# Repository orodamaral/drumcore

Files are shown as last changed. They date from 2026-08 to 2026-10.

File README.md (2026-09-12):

# DRUMCORE — Módulo MIDI-USB/BLE para Bateria Eletrônica (ESP32-S3)

Módulo de disparo MIDI para bateria eletrônica, baseado em ESP32-S3, com suporte a
32 canais analógicos (via 2x multiplexador CD4067, uma "jackboard" de 16 canais
cada — ver [hardware/jackboard/](hardware/jackboard/)), tela TFT ST7735 (SPI) e
1 encoder rotativo com chave para navegação, e um app de configuração em React,
direto pelo navegador via Web Serial — sem instalar nada.

Projeto construído sobre a biblioteca [HelloDrum-arduino-Library](https://github.com/RyoKosaka/HelloDrum-arduino-Library)
de Ryo Kosaka (vendorizada e adaptada em [firmware/lib/HelloDrum-arduino-Library](firmware/lib/HelloDrum-arduino-Library)).

## Estrutura do projeto

```
DrumCore/
├── docs/                 Documentação do projeto (decisões, hardware, progresso)
├── design/               Especificação de UI, identidade visual (logo, paleta)
├── firmware/             Firmware ESP32-S3 (PlatformIO)
│   ├── platformio.ini
│   ├── src/              Código-fonte do módulo
│   ├── include/
│   └── lib/
│       └── HelloDrum-arduino-Library/   Biblioteca base, vendorizada e modificada
├── hardware/             Projetos KiCad (jackboard — placa de conectores TRS + rede de proteção)
├── web-app/              App de configuração do módulo (React/TS), direto no navegador via
│                         Web Serial, sem instalar nada
└── site/                 Site estático de apresentação do projeto (GitHub Pages) — publica
                          o web-app/ em site/app/, ver .github/workflows/pages.yml
```

## Documentação

Todo o histórico de decisões, aprendizados sobre a biblioteca base e notas de
hardware está em [docs/](docs/). Comece por [docs/00-visao-geral.md](docs/00-visao-geral.md).

## Status

Veja [docs/CHANGELOG.md](docs/CHANGELOG.md) para o histórico completo do que já
foi feito.

## Licença

Este projeto é licenciado sob [Creative Commons Atribuição-NãoComercial 4.0
Internacional (CC BY-NC 4.0)](LICENSE) — uso e cópia livres, **sem fins
comerciais**, sempre **citando a fonte** (este repositório e a
HelloDrum-arduino-Library, ver crédito acima). Detalhes completos e a
atribuição de terceiros (a biblioteca base, sob licença MIT própria) estão em
[LICENSE](LICENSE).

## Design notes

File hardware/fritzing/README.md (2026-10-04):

# Peça do Fritzing — DrumCore Jackboard

`DrumCore_Jackboard.fzpz` é a jackboard single-layer como peça do
[Fritzing](https://fritzing.org/), para desenhar a ligação do módulo
(ESP32-S3 + jackboards + tela + encoder) e dos pads.

## Como usar

No Fritzing: **Arquivo > Abrir** (ou arraste o `.fzpz` para a janela). A peça
aparece no bin **Minhas peças** (*My Parts*), família "DrumCore".

## O que a peça tem

- **Medidas reais** do projeto KiCad (`hardware/jackboard_singlelayer/`):
  placa de 184 × 57,5 mm, jacks a cada 22,5 mm, furos nas posições reais
  (vista PCB).
- **24 conectores**:
  - **8 de controle do MUX:** GND, VCC (3,3 V), EN, S0, S1, S2, S3, SIG. O
    EN já vai para o GND na própria placa (no Fritzing, EN e GND estão no
    mesmo barramento), então bastam 7 fios até o ESP32.
  - **Tip e ring dos 8 jacks** (J1 tip = canal 0 = pad 1 no ConfigTool, J1
    ring = canal 1, e assim por diante), para ligar os pads no diagrama.

Ligação no ESP32-S3: S0–S3 = GPIO39/40/41/42 (as 2 placas em paralelo), SIG da
placa A = GPIO2, da placa B = GPIO1. Ver [docs/02-hardware.md](../../docs/02-hardware.md).

## Gerar de novo

```
python hardware/fritzing/make_jackboard_fzpz.py
```

Gera o `.fzpz` e os arquivos soltos em `part/` (`.fzp` + SVGs das vistas
protoboard, esquemático, PCB e ícone). As medidas ficam no topo do script. Se a
placa mudar no KiCad, atualize lá.

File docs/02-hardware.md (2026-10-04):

# Hardware

**Esquemático visual**: [docs/assets/esquematico-hellodrum.html](assets/esquematico-hellodrum.html)
(abrir no navegador) reúne todo o pinout abaixo num diagrama único — ESP32-S3
↔ 2x CD4067 (HW-178) ↔ tela TFT ↔ 1 encoder, já mostrando de qual header
físico (esquerdo/direito) cada fio sai. Também publicado como
[artifact](https://claude.ai/code/artifact/7bcaa18b-a9b3-46e4-8ba0-90197b7ededc)
(link privado, pode estar desatualizado - o arquivo local é a fonte da
verdade). Gerado em 2026-08-20, redesenhado em 2026-08-21 para o CD4067
(Fase K), reorganizado por ergonomia de montagem em 2026-08-21 (Fase L),
refinado no mesmo dia pra usar pinos fisicamente **contíguos** dentro de
cada header, reduzido de 2 encoders pra 1 na Fase Y (2026-09-04) e
**reorganizado por função** (em vez de por alimentação) na Fase Z
(2026-09-05, ver seção "Divisão adotada" abaixo) — atualizar (ou marcar
como desatualizado) se o pinout abaixo mudar de novo.

## Componentes previstos

- 1x placa ESP32-S3 (dev board, 44 pinos em 2 headers de 22, USB-C nativo
  exposto). Pinout confirmado a partir de uma foto da placa real (vendedor
  "OceanLabz") em 2026-08-21 — ver seção "Pinout real da placa" abaixo.
  Módulo confirmado por Rodrigo na serigrafia em 2026-08-31: **ESP32-S3-N16R8**
  (16MB flash + 8MB PSRAM **octal**) — GPIO33-37 são internos (barramento
  da PSRAM) nessa variante, ver "Pinos evitados" abaixo.
  `firmware/platformio.ini` ajustado em 2026-08-31 (overrides de
  `board_build`/`board_upload` + `-D BOARD_HAS_PSRAM`) pra refletir o
  módulo real (16MB flash, PSRAM octal habilitada) — ver
  [01-decisoes-arquiteturais.md](01-decisoes-arquiteturais.md) pro
  detalhe. `pio run` confirmado com sucesso.
- 2x módulo multiplexador analógico CD4067 (breakout "HW-178", 16 canais
  cada → 32 canais totais). Comprado já montado em placa (resistores/
  desacoplamento inclusos) — substitui as 4x CD4051 previstas originalmente,
  ver [01-decisoes-arquiteturais.md](01-decisoes-arquiteturais.md) pro
  racional da troca (Fase K).
  **Realização física (2026-09-06, confirmado por Rodrigo)**: em vez do
  breakout HW-178 avulso, cada um dos 2 MUX vive numa placa própria — a
  **jackboard** (`hardware/jackboard/`, projeto KiCad): HC4067 onboard +
  8 jacks TRS 6.35mm (16 canais) + rede de proteção por canal. O sistema
  final usa **2 jackboards idênticas**, uma por MUX, pra fechar os 32
  canais. **Cada jack TRS leva 2 canais**: canal par (0-based: 0, 2, 4…) =
  **tip**, ímpar (1, 3, 5…) = **ring** — na numeração do ConfigTool, Pad 1
  = tip e Pad 2 = ring do Jack 1, e assim por diante (confirmado pelo
  Rodrigo em 2026-09-27). Sensores de 2 zonas leem a zona principal no 1º
  canal do par, então precisam começar no tip: **tip = pele/corpo, ring =
  aro/borda**, o padrão dos pads de mercado. O firmware recusa tipo de 2
  canais começando num ring (`set_pad` → `two_channel_needs_tip`; na tela
  o encoder pula esses tipos), e a tela LIVE/lista de pads mostra os
  canais agrupados por jack. Ver [site/hardware.html](../site/hardware.html) e
  `docs/CHANGELOG.md` (entrada 2026-09-06) pro estado atual da placa.
- Pads piezo (simples e/ou duplos), pratos 2/3 zonas, hi-hat, conforme suportado
  pela lib (ver [03-biblioteca-hellodrum.md](03-biblioteca-hellodrum.md)).
- Tela TFT 1.8" 128x160 RGB (sticker do modelo real - a doc antiga dizia
  1.44"/128x128, era só suposição antes de conferir na placa física),
  driver ST7735S, interface SPI, rodando em paisagem (160x128 na tela,
  `setRotation(1)` - ver [01-decisoes-arquiteturais.md](01-decisoes-arquiteturais.md),
  Fase R). Substitui o OLED SSD1306/I2C previsto inicialmente.
- 1x encoder rotativo com chave (push-button), para navegação/edição —
  substitui os 5 botões discretos originalmente previstos, e o par de 2
  encoders usado até a Fase Y (2026-09-04) — ver
  [01-decisoes-arquiteturais.md](01-decisoes-arquiteturais.md) (Fase Y e
  Fase Z).

## Pinout real da placa (Fase L, reorganizado na Fase Z)

A placa comprada expõe os 44 GPIOs do ESP32-S3 em 2 headers físicos de 22
pinos cada, um de cada lado do módulo WROOM. Isso importa pra ergonomia da
montagem: **cada subsistema (MUX, tela, encoder) deve sair inteiro de um
único header**, pra não precisar de fios cruzando de um lado ao outro da
placa.

Até a Fase Y, a divisão era guiada por **alimentação**: `3V3` só existia no
header esquerdo (o direito só tinha `GND`), então o MUX e a tela (que
precisam de VCC) ficavam à força no header esquerdo, sobrando o direito só
pros encoders (que usam apenas pull-up interno, sem VCC externo).

**Fase Z (2026-09-05)**: a placa física ganhou pads de `3V3`/`GND` extras
nos **dois** headers (adicionados por fora do dev board original,
independente do desenho de fábrica) — então essa restrição deixou de
existir, e a divisão passou a ser guiada por **função** em vez de
alimentação: interface do usuário (encoder + tela) de um lado, sensing
(2x CD4067) do outro. Cada lado continua usando um bloco único de pinos
**fisicamente contíguos** (sem nenhum outro sinal no meio) — só mudou o
critério de agrupamento, não a regra de contiguidade.

A ordem física real do header esquerdo (de cima a baixo) é `3V3,3V3,RST,
4,5,6,7,15,16,17,18,8,3,46,9,10,11,12,13,14,5V,GND` — descontando `3V3`,
`RST`, `5V`, `GND` (não são GPIO) e os 2 pinos de strapping (`3`, `46`,
avoid list abaixo), sobra um bloco contíguo de 9 GPIOs logo após o `3V3`:
`4,5,6,7,15,16,17,18,8`. É exatamente o tanto que encoder (3 sinais) + tela
(6 sinais) precisam juntos — cabem inteiros nesse bloco, sem pular nada.

A ordem física real do header direito inclui o trecho contíguo `...44,1,2,
42,41,40,39,38,...` (mesmo trecho que os 2 encoders usavam antes da
Fase Y/Z) — descontando o `GPIO38` (evitado, aciona o LED embutido), sobra
o bloco contíguo `1,2,42,41,40,39`, exatamente os 6 sinais que o MUX
precisa (S0-S3 + SIG0 + SIG1).

**Divisão adotada (Fase Z)**:

| Header | Subsistema | Sinais |
|---|---|---|
| **Esquerdo** | Encoder | A, B, SW |
| **Esquerdo** | Tela TFT ST7735 | DC, CS, MOSI, SCLK, BLK, RST |
| **Direito** | 2x CD4067 (HW-178) | S0, S1, S2, S3, SIG0, SIG1 |

> Os pads de `3V3`/`GND` extras nos dois headers (que tornam essa divisão
> possível) são uma modificação física da placa feita pelo Rodrigo, fora do
> escopo do que o firmware/software controla — ver
> [01-decisoes-arquiteturais.md](01-decisoes-arquiteturais.md) (Fase Z).

**Pinos evitados** (`firmware/src/main.cpp`, ver
[01-decisoes-arquiteturais.md](01-decisoes-arquiteturais.md) Fase L pro
racional completo de cada um):

- `GPIO0`, `GPIO3`, `GPIO45`, `GPIO46` — pinos de strapping (afetam o modo
  de boot; nunca usar como sinal de periférico).
- `GPIO19`, `GPIO20` — USB nativo (D-/D+), usados internamente pelo
  USB-MIDI da Fase B.
- `GPIO38` — nessa placa, aciona um LED embutido (rótulo `BUILTIN LED` na
  serigrafia/datasheet do vendedor, confirmado por Rodrigo direto na placa
  física em 2026-08-31 — corrige uma leitura anterior que atribuía o LED
  RGB a este pino). Usar esse pino pra outra coisa entraria em conflito com
  o LED onboard. O LED RGB endereçável de fato fica no `GPIO48` (rótulo
  `RGB LED`), já excluído abaixo por outro motivo (sinal interno de
  flash/PSRAM nessa variante do módulo).
- `GPIO47`, `GPIO48` — rotulados `SPICLK_P`/`SPICLK_N` na placa, sinais
  internos de flash/PSRAM nessa variante do módulo — não expor.
- `GPIO35`, `GPIO36`, `GPIO37` — essa placa expõe eles como GPIO genérico,
  mas em módulos ESP32-S3 com PSRAM **octal** esses mesmos pinos são
  internos (ligados ao chip de PSRAM) e usá-los externamente trava a
  placa. A serigrafia expor esses pinos como header sugere que este
  módulo **não** é a variante octal — mas isso não foi confirmado contra o
  datasheet exato do módulo. Desde o ajuste de contiguidade de
  2026-08-31 (ver seção de encoders abaixo), nenhum pino do projeto atual
  depende disso — o risco fica registrado só como referência caso algum
  uso futuro volte a cogitar esses 3 GPIOs.

## Ligação CD4067 (HW-178) ↔ ESP32-S3 — header DIREITO

Cada módulo HW-178 precisa de 4 pinos digitais de seleção de canal (S0, S1,
S2, S3, compartilháveis entre as 2 placas) + 1 pino ADC dedicado (SIG, saída
analógica — este **não** pode ser compartilhado, cada MUX precisa do seu
próprio pino ADC) + alimentação (VCC 3.3V, GND) + o pino **EN** (enable,
ativo em LOW) **ligado direto em GND** em cada uma das 2 placas — não é
controlado pelo firmware (a lib não expõe esse pino; como cada MUX tem seu
próprio pino SIG, não há necessidade de desabilitar um deles em nenhum
momento, então fica sempre habilitado por fiação).

**Se aparecer crosstalk entre os 2 CD4067** (mesmo canal local em cada
placa — ex: canal 3 do MUX 0 e canal 3 do MUX 1 — lidos no mesmo instante
via o barramento S0-S3 compartilhado): existe uma mitigação por software
(`xtalk`/`xtalk_group` no protocolo, Fase P — ver
[01-decisoes-arquiteturais.md](01-decisoes-arquiteturais.md)) que suprime
o hit mais fraco quando 2 pads do mesmo grupo batem "juntos". Não
substitui um bom desacoplamento elétrico (capacitores perto de cada
CD4067, fiação de sinal curta/blindada se possível) — é um plano B pra
quando o crosstalk aparecer na prática, não uma solução definitiva.

```
HW-178 (CD4067) #n --------- ESP32-S3 (header DIREITO)
S0     ------------ (compartilhado entre as 2 placas)
S1     ------------ (compartilhado entre as 2 placas)
S2     ------------ (compartilhado entre as 2 placas)
S3     ------------ (compartilhado entre as 2 placas)
SIG    ------------ pino ADC dedicado ao MUX #n
EN     ------------ GND (sempre habilitado, fixo por fiação)
VCC    ------------ 3.3V (pad extra adicionado no header direito, Fase Z)
GND    ------------ GND
```

### Pinout (usado em `firmware/src/main.cpp`)

> **Status: validado em hardware real** (2026-10): as 2 jackboards
> montadas, com os 32 canais lidos pelo MUX. Reorganizado na Fase Z (2026-09-05) pro header
> DIREITO, no bloco contíguo
> `GPIO1,2,42,41,40,39` (mesma faixa física que os 2 encoders usavam antes
> da Fase Y/Z). SIG0/SIG1 (leitura analógica) precisam de pino com ADC —
> só `GPIO1`/`GPIO2` desse bloco têm (**ADC1_CH0**/**ADC1_CH1**), então
> ficam com eles; S0-S3 (linhas digitais de seleção, sem precisar de ADC)
> ficam nos 4 restantes (`42,41,40,39`). Isso troca o MUX de ADC2 (Fase L)
> pra ADC1 — mais simples que antes: ADC1 nunca conflita com Wi-Fi (nem
> precisa do racional "tá seguro pq não tem Wi-Fi" que a Fase L precisou).

| Sinal | GPIO (ESP32-S3) |
|---|---|
| S0 (compartilhado) | 39 |
| S1 (compartilhado) | 40 |
| S2 (compartilhado) | 41 |
| S3 (compartilhado) | 42 |
| SIG — MUX 0 / jackboard A (jacks 1-8, pads 0-15) | 2 (ADC1_CH1) |
| SIG — MUX 1 / jackboard B (jacks 9-16, pads 16-31) | 1 (ADC1_CH0) |

**Ajustado em 2026-10-01** com a jackboard A montada (Rodrigo): a ordem do
S0-S3 inverteu (antes S0=42 … S3=39) e os SIGs trocaram de lugar. GPIO39-42
são os pinos de JTAG por pino (MTCK/MTDO/MTDI/MTMS) — livres como GPIO, porque
o ESP32-S3 usa por padrão o JTAG pelo USB (GPIO19/20) — e nenhum deles é de
strapping (0, 3, 45, 46). A ordem do S0-S3 precisa bater exatamente com a
fiação: invertida, o endereço sai com os bits ao contrário e os canais
embaralham (canal 1 lido como 8, 2 como 4...).

As 2 jackboards (A e B) estão montadas e validadas desde 2026-10. Se uma
delas for desconectada, o SIG dela fica flutuando e os pads dessa placa
podem ler ruído como batida: desligue esses canais no ConfigTool.

## Tela TFT (ST7735, SPI) — header ESQUERDO

**Modelo**: 1.8" 128x160 RGB (confirmado pelo sticker na placa física -
`INITR_BLACKTAB`, não `INITR_144GREENTAB`), driver IC ST7735S. 8 pinos:
`GND VCC SCL SDA RES DC CS BLK` (SPI, não I2C). Rodando em paisagem
(`setRotation(1)`, 160x128) - ver
[01-decisoes-arquiteturais.md](01-decisoes-arquiteturais.md) Fase R.

| Sinal na tela | Função | GPIO (ESP32-S3) |
|---|---|---|
| SCL | SPI Clock (SCK) | 7 |
| SDA | SPI Data (MOSI) | 15 |
| RES | Reset | 16 |
| DC | Data/Command | 17 |
| CS | Chip Select | 18 |
| BLK | Backlight | 8 (ou direto em 3.3V, se não precisar controlar brilho) |
| VDD | 3.3V | — (pad extra ao lado do bloco, ver ajuste abaixo) |
| GND | GND | — (pad extra ao lado do bloco, ver ajuste abaixo) |

> **Status: validado em hardware real (2026-09-06)** — Rodrigo conectou a
> tela nesse pinout novo e confirmou funcionando.
>
> **Fase Z (2026-09-05)**: a tela forma um feixe único e contíguo com o
> encoder (`GPIO4,5,6,7,15,16,17,18,8` — encoder nos 3 primeiros, tela nos
> 6 seguintes), já que ambos saem do header ESQUERDO agora (interface do
> usuário de um lado, MUX do outro — ver "Divisão adotada" mais acima).
>
> **Ajuste (2026-09-06)**: a pedido do Rodrigo, os 6 GPIOs da tela foram
> reordenados dentro desse mesmo bloco pra casar com a ordem física real
> do conector dela (`GND VDD SCL SDA RES DC CS BLK`) — descontando
> `GND`/`VDD` (não são GPIO), os 6 sinais restantes saem na sequência
> `SCL(7) → SDA(15) → RES(16) → DC(17) → CS(18) → BLK(8)`, batendo 1:1 com
> a ordem física do bloco `7,15,16,17,18,8`. `GND`/`VDD` da tela vão nos
> pads extras que o Rodrigo está adicionando fisicamente perto desse
> bloco (não existe `GND`/`3V3` de fábrica logo ali — ver "Divisão
> adotada" mais acima sobre os pads extras).

## Navegação/configuração: 1 encoder rotativo com chave — header ESQUERDO

Substitui os 5 botões discretos (EDIT/UP/DOWN/NEXT/BACK) que a classe
`HelloDrumButton` da lib pressupõe originalmente. Até a Fase X eram 2
encoders (rotação + chave cada); a Fase Y (2026-09-04) reduziu pra 1 só,
que sozinho cobre toda a navegação (girar = navega/ajusta valor, clicar =
desce um nível/confirma, segurar = volta um nível) — ver
[01-decisoes-arquiteturais.md](01-decisoes-arquiteturais.md) Fase Y pro
mapeamento completo e o racional, e Fase Z pro pinout atual.

| Sinal | Função | GPIO (ESP32-S3) |
|---|---|---|
| A | Quadratura | 4 |
| B | Quadratura | 5 |
| SW | Click/hold | 6 |

> **Fase Z (2026-09-05)**: migrado do header direito (`GPIO41,40,39`) pro
> header esquerdo, no bloco contíguo que também tem a tela
> (`GPIO4,5,6,7,15,16,17,18,8` — ver "Divisão adotada" mais acima). Os
> `GPIO41,40,39` (ex-encoder) agora fazem parte do bloco do MUX no header
> direito; `GPIO1,2,42` (livres desde a Fase Y) também entraram no bloco
> do MUX.
>
> **VCC do encoder (2026-09-02, ainda válido)**: o módulo físico que
> chegou é um breakout pronto (5 pinos: `GND S1 S2 KEY VCC`) com
> componentes SMD visíveis (resistor + capacitor) — quase certamente
> pull-ups de `S1`/`S2`/`KEY` pra `VCC` (+ talvez um capacitor de
> debounce), não um encoder cru. `VCC` vai no `3V3` (o ESP32-S3 também
> mantém `INPUT_PULLUP` interno ativo em `S1`/`S2`/`KEY` — os dois
> pull-ups ao mesmo tempo não causam problema elétrico).
>
> **Status: validado em hardware real (2026-09-06)** — Rodrigo religou o
> encoder nesse pinout novo (GPIO4/5/6) e confirmou a navegação
> funcionando (giro/clique/hold).

## Notas

- Pinos livres/sobressalentes: `GPIO9,10,11,12,13,14` (header esquerdo,
  onde a tela ficava antes da Fase Z) e `GPIO21` (header direito) — nenhum
  uso previsto por ora. `GPIO9`/`GPIO10` eram usados pelo bring-up sem
  jackboard (canais 1 e 2 lidos direto do ESP32), removido em 2026-09-27
  com a jackboard montada: os 32 canais são lidos pelo MUX.
- `GPIO43`/`GPIO44` (header direito) **não estão livres**, apesar de
  aparecerem como GPIO genérico na serigrafia: são o UART físico
  (TXD0/RXD0) que o firmware usa pra `Serial` (protocolo NDJSON com o app)
  quando compilado com `ARDUINO_USB_CDC_ON_BOOT=0` — ver
  [01-decisoes-arquiteturais.md](01-decisoes-arquiteturais.md) (Fase R).
  Corrige uma nota anterior que os listava como "sem uso previsto".

## Lista de componentes

Lista completa (módulo principal, por jackboard e pads/pedal) na página de
hardware do site: [site/hardware.html](../site/hardware.html#componentes).
Resumo por jackboard (do projeto KiCad `hardware/jackboard_singlelayer/`):

| Por placa | Componente |
|---|---|
| 1 | placa cobreada face simples, mín. 184 × 57,5 mm |
| 8 | jack P10 estéreo (TRS 6,35 mm), footprint Neutrik NMJ6HCD2 |
| 1 | módulo multiplexador 16 canais CD74HC4067 (ex.: HW-178) |
| 1 + 1 | barra de pinos fêmea 2,54 mm 1×16 e 1×8 |
| 16 | resistor 1 kΩ (série, 1 por canal) |
| 16 | resistor 100 kΩ (canal → GND) |
| 32 | diodo 1N4148 (2 por canal: GND e 3V3) |
| 1 | resistor 4,7 kΩ (SIG → GND) |

## Jackboard single-layer montada (2026-10)

As 2 jackboards (A e B) foram corroídas em casa, montadas e validadas.

| Vista de cima | Vista de baixo |
|---|---|
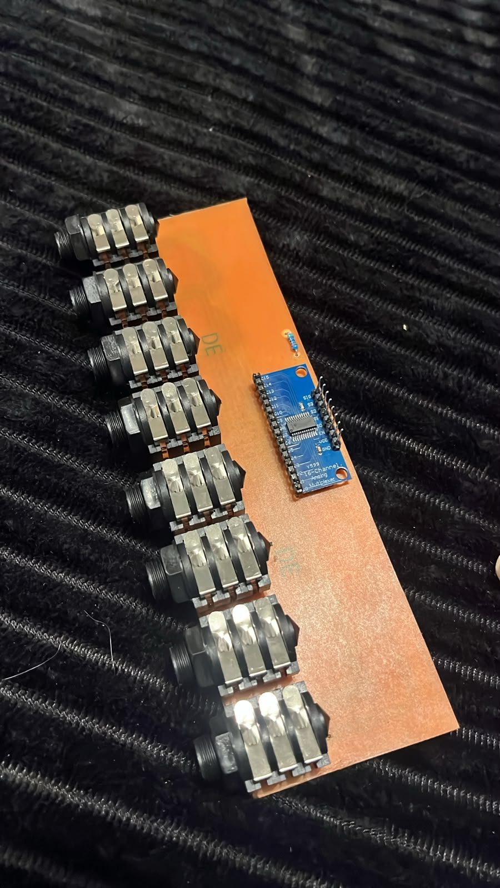
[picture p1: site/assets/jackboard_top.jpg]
Jackboard montada, vista de cima: 8 jacks TRS e o módulo do MUX
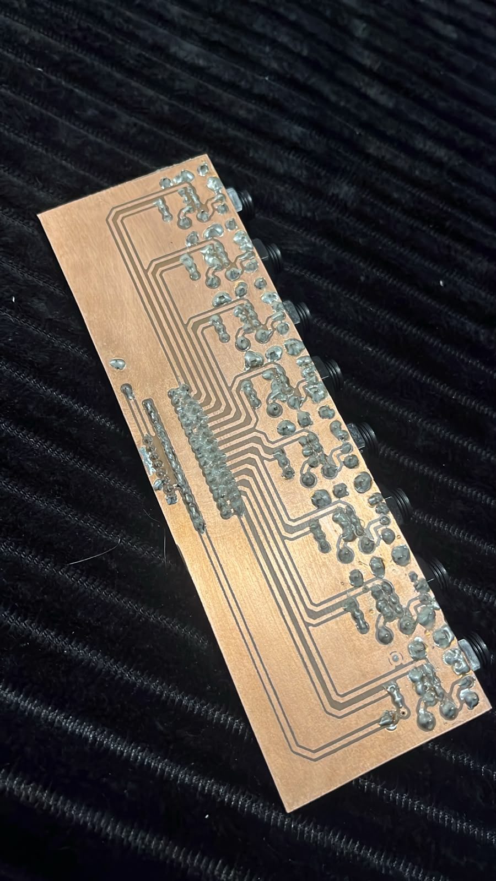
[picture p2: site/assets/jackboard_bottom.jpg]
Jackboard montada, vista de baixo: trilhas corroídas e soldas
|  |  |

## Jack 1: controlador de chimbal com sensor Hall SS49E (2026-10-01)

Montagem **validada na bancada** (Rodrigo, jackboard A single-layer): o
controlador de chimbal do kit de fábrica fica no **jack 1** (ring = sinal,
tip livre), e o SS49E precisa de alimentação pelo cabo.

**Como ficou o jack 1 na placa:**

- **Todos os componentes de proteção dos canais 0 e 1 retirados** (R1, R2,
  R17, R18, D1, D2).
- **Jumper do +3,3 V para o tip** do J1 (alimenta o SS49E). Ponto prático: a
  via de +3,3 V fica logo acima do R1, a ~3 mm do furo de cima dele.
- **Jumper no lugar do R2**: ring do J1 direto no canal 1 do MUX.

Montado com os componentes do esquemático (1k em série, 100k e diodos), a
leitura ficou em 0 o tempo todo e a causa não foi identificada; só com os
jumpers o sinal apareceu. Pela conta, só o 1k + 100k + o 4,7k do SIG deveriam
atenuar ~20%, não zerar — fica como ponto a investigar se um dia esse jack
voltar a ter proteção.

**Cabo / pedal (TRS):** tip = VCC do SS49E · ring = OUT · sleeve = GND.
Opcional: 100 nF entre VCC e GND junto do sensor (reduz o tremor do CC4).

**Leituras (`mux_test`, ADC 12 bits):** repouso ~1850–1860 (±20 de ruído);
com um ímã à mão, 1228–2443 — ~600 contagens úteis para cada lado do repouso,
o suficiente para o CC4 (~5 contagens por degrau). No pedal, o ímã deve se
aproximar **de frente** do sensor, para o percurso aberto→fechado andar num
sentido só (o SS49E sobe com um polo e desce com o outro).

**Cuidados dessa montagem:**

- **Jack 1 é dedicado ao chimbal.** Sem a proteção, um pad de piezo ligado
  ali por engano manda picos direto pro MUX/ADC — marcar o jack no painel.
- **3,3 V direto no tip, sem limitação de corrente:** ao plugar ou desplugar
  com o módulo ligado, a ponta do plugue encosta um instante no GND e pode
  reiniciar o ESP32. Plugar o pedal com o módulo desligado (ou trocar o
  jumper por ~47 Ω).
- **Perna TN do J1:** com 3,3 V no tip, o contato TN (ligado ao GND) não pode
  ficar soldado, senão o 3,3 V entra em curto sempre que o jack estiver
  vazio.
- **Placa B:** o jack 9 é montado normal, como os outros pads.

## Mapeamento de fábrica (2026-09-27)

Kit gravado na primeira inicialização da EEPROM e pelo "restaurar padrão
de fábrica" (comando `factory_reset`, botão na aba Global do ConfigTool,
GLOBAL > FABRICA na tela do módulo). Função `applyFactoryPreset()` em
`firmware/src/main.cpp`; notas do keymap do Addictive Drums 2.

| Jack | Tip (canal par) | Ring (canal ímpar) | Notas |
|---|---|---|---|
| 1 | desligado | HH Pedal (FSR / VH-10 / VH-11) — só CC4, sem chick | (48 se ligar o chick) |
| 2 | HiHat (pad simples, nota fixa) | desligado | 8 ("HiHat CC Tip") |
| 3 | Kick | desligado | 36 |
| 4 | Snare 3 zonas (tip + ring) | | 38 / 43 borda / 37 aro |
| 5–8 | Tom 1–4 dual (tip pele, ring aro) | | 71/72, 69/70, 67/68, 65/66 |
| 9–12 | Cym 1–4 simples | Choke 1–4 | 77/78, 79/80, 81/82, 89/90 |
| 13 | Ride 1 prato 3 zonas (tip corpo, ring borda/cup) | | 60 / 62 / 61 |
| 14–16 | desligado | desligado | — |

Apelidos dos jacks na tela LIVE (até 6 caracteres): HHC, HH, KICK, SNARE,
TOM1–TOM4, CYM1–CYM4, RIDE, XTRA1–XTRA3.

Sensibilidade/threshold/scan/mask e demais parâmetros ficam nos valores
iniciais da lib (100/10/10/30, gain 100%, sem crosstalk); canal MIDI 10,
saída USB + BLE.
- Esta seção deve ser atualizada com o pinout real assim que o hardware for
  prototipado/testado, incluindo fotos ou diagramas se fizer sentido.

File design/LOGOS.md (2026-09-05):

# DrumCore — logos

Referência visual: `DrumCore Logos.html` (abre offline no navegador, contém as 5 direções em tamanho grande, versão 1-bit e ícone quadrado).

**Direção escolhida: 1A (pixel / grade de pads)** — já implementada como serigrafia
(F.SilkS) na `hardware/jackboard/drumcore_jackboard.kicad_pcb`: wordmark "DRUMCORE"
em bitmap 5x7 pixel-art (134 quadrados individuais), canto superior esquerdo da
placa, lado componente (topo). As outras 4 direções (1B-1E) seguem no arquivo de
referência apenas como registro histórico, não usadas.

## Paleta (mesma da UI do módulo)

| Nome | HEX | RGB565 |
|---|---|---|
| BG | #101418 | 0x10A3 |
| SURFACE | #1E252B | 0x1925 |
| LINE | #38434D | 0x3A09 |
| TXT_DIM | #7A8894 | 0x7C52 |
| TXT | #E6EDF3 | 0xE77E |
| ACCENT | #00D2FF | 0x069F |
| HIT | #FF7A1A | 0xFBC3 |

## Tipografia

- **Silkscreen** (Google Fonts) — usada em 1A e em todos os rótulos técnicos. É a fonte pixel; no firmware o equivalente é a GFX 5x7.
- **Archivo** (Google Fonts), pesos 500 / 700 / 900 — usada em 1B, 1C, 1D, 1E.

## As 5 direções

**1A — Pixel / grade de pads.** Grade 8x4 de quadrados de 14 px (gap 3) acima do wordmark em Silkscreen 30 px, tracking 2 px. Uma célula acesa em HIT. É a que casa direto com a tela LIVE.

**1B — Peso partido.** Archivo, "DRUM" em 500 / TXT_DIM e "CORE" em 900 / TXT, 56 px, tracking −2 px, sublinhado ACCENT de 3 px na largura do texto. Ícone: quadrado ACCENT com "DC" em 900.

**1C — Núcleo concêntrico.** Dois quadrados de borda 5 px (76 px externo, 44 px interno) com um quadrado HIT de 16 px no centro, à esquerda do lockup "DRUMCORE" (Archivo 900, 38 px) + "TRIGGER MODULE" (Silkscreen 10 px, tracking 3 px). Única direção com símbolo separável do texto.

**1D — Envelope.** Wordmark Archivo 700, 48 px, tracking 5 px, sobre uma linha de base de 24 barras que descrevem o decay de um trigger (primeiras 2 barras em HIT).

**1E — Placa.** Caixa de borda 3 px dividida: bloco "DC" invertido (Archivo 900, 44 px) + "DRUMCORE" (700, 24 px) e "32 PAD · ESP32-S3" (Silkscreen 8 px, ACCENT).

## Uso na tela de boot (128x128)

O arquivo HTML mostra 1A, 1B e 1D aplicadas ao boot, em 2x. Regras:
- Wordmark centralizado, cor ACCENT, baseline em y≈50.
- Barra de progresso 80x4 em x=24, y=82 (trilho SURFACE, preenchimento ACCENT).
- `v0.1  ESP32-S3` em Silkscreen size 1, cor LINE, y=110.
- Para 1A no firmware, o wordmark cabe em size 2 da GFX 5x7 (8 caracteres × 12 px = 96 px, sobra 16 px de margem em cada lado).

## Grade de 1A como bitmap

Padrão de células acesas (grade 8 colunas × 4 linhas, índice 0 na esquerda em cima, ordem em linha):
`1,2,5,6,9,11,12,14,17,18,21,22,25,26,29,30` acesas em TXT; a célula `12` em HIT; restantes em SURFACE.

Ícone 4x4: acesas `1,2,4,7,8,11,13,14` em TXT; célula `5` em HIT.

## Pendências

- Se uma segunda jackboard (ou outra placa futura) precisar do logo, repetir o
  mesmo processo (bitmap 5x7 manual + import pixel-a-pixel via Konnect — ver
  `hardware/jackboard/assets/pixel.svg`) já que não existe arquivo vetorial
  (.svg/.ai) do wordmark, só a arte pixel-a-pixel direto no `.kicad_pcb`.

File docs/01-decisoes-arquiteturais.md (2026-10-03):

# Decisões Arquiteturais

Registro cronológico de decisões técnicas relevantes, com contexto e alternativas
consideradas. Formato: **Data — Decisão — Contexto/Racional — Alternativas descartadas**.

---

## 2026-08-20 — Placa: ESP32-S3

**Decisão**: usar ESP32-S3 como microcontrolador do módulo.

**Contexto/Racional**: o objetivo é MIDI-USB nativo (o módulo aparece como
dispositivo MIDI USB plug-and-play no computador/DAW, sem software intermediário).
O ESP32 "clássico" (WROOM/WROVER) não tem controlador USB nativo — só USB-serial
via chip conversor (CP2102/CH340), o que não permite classe USB-MIDI real. O
ESP32-S3 (e também o S2) tem USB OTG nativo, suportado pelo core arduino-esp32 via
TinyUSB, permitindo implementar a classe MIDI USB de verdade.

**Alternativas descartadas**:
- ESP32-S2: também teria USB nativo, mas o S3 tem mais memória/performance e
  Wi-Fi+BLE mais robusto, útil caso o projeto evolua para incluir BLE-MIDI como
  opção adicional no futuro.
- ESP32 clássico + BLE-MIDI: viável, mas não atende ao requisito de "módulo
  MIDI-USB" (seria sem fio, não USB).
- ESP32 clássico + Hairless MIDI (serial-to-MIDI): funcional mas depende de
  software rodando no PC, não é plug-and-play.

## 2026-08-20 — Toolchain: PlatformIO

**Decisão**: desenvolver o firmware com PlatformIO (não Arduino IDE).

**Contexto/Racional**: projeto de longa duração, com múltiplas bibliotecas e
necessidade de builds reprodutíveis e bom versionamento das dependências junto
com o código no Git. PlatformIO tem melhor suporte a isso e integra bem com
VSCode.

**Nota de setup**: o PlatformIO CLI ainda não está instalado na máquina de
desenvolvimento no momento da criação do projeto — precisa ser instalado antes
da primeira compilação (via extensão do VSCode ou `pip install platformio`).

**Alternativas descartadas**:
- Arduino IDE: mesmo fluxo dos exemplos originais da HelloDrum-lib, porém pior
  controle de versão de dependências e menos adequado a um projeto que também
  terá firmware + interface desktop versionados juntos.

## 2026-08-20 — Biblioteca base: fork + vendorização

**Decisão**: usar [HelloDrum-arduino-Library](https://github.com/RyoKosaka/HelloDrum-arduino-Library)
como base, mas vendorizada (copiada) em `firmware/lib/HelloDrum-arduino-Library`
dentro do próprio repositório do projeto, em vez de depender dela como submodule
ou dependência externa intocada.

**Contexto/Racional**: o projeto provavelmente vai precisar de modificações na
biblioteca (ex: integração mais direta com USB-MIDI nativo do ESP32-S3, ajustes
para o esquema de 4 MUXes / 32 canais, integração com a tela OLED e fluxo de
configuração custom). Vendorizar permite modificar livremente e documentar essas
mudanças, sem ficar preso à estrutura de um submodule Git ou depender de PRs
aceitos no repositório original.

**Importante**: qualquer modificação feita na cópia vendorizada da lib deve ser
registrada em [03-biblioteca-hellodrum.md](03-biblioteca-hellodrum.md), na seção
"Modificações em relação ao original", para não perdermos rastro do que é
biblioteca original vs. código nosso.

**Alternativas descartadas**:
- Dependência externa (git submodule ou `lib_deps` do PlatformIO apontando pro
  repo original): manteria a lib "limpa", mas dificultaria modificações
  necessárias no código dela.

## 2026-08-20 — Multiplexação: 4x CD4051 nativamente suportado

> **Atualização (Fase K, 2026-08-21)**: essa decisão foi revertida — o
> projeto passou a usar 2x CD4067 (`HelloDrumMUX_4067`) em vez de 4x CD4051.
> Ver entrada "Fase K" no final deste documento. Mantida aqui como registro
> histórico do porquê o CD4051 foi escolhido originalmente (era o chip que
> a lib já suportava nativamente) — os fatos técnicos descritos abaixo sobre
> `rawValue[]`/`muxIndex`/offset manual continuam corretos, só que agora
> aplicados à classe `_4067` (16 canais por MUX, não 8).

**Decisão**: usar a classe `HelloDrumMUX_4051` da própria biblioteca, criando 4
instâncias (uma por chip CD4051), sem necessidade de modificar a lib para isso.

**Contexto/Racional**: ao ler o código-fonte (`hellodrum.cpp`), descobrimos que:
- Existe um array estático global `rawValue[64]` quando compilado para ESP32
  (comentário no código: "8 * 8channel Mux"), ou seja, já suporta até 8 MUXes
  CD4051 (64 canais) nativamente.
- Cada instância de `HelloDrumMUX_4051` recebe um `muxNum` sequencial automático
  (variável estática `muxIndex`, incrementada no construtor) — o 1º MUX
  instanciado no código é `muxNum = 0`, o 2º é `muxNum = 1`, etc.
- O método `scan()` de cada MUX escreve os valores lidos em
  `rawValue[muxNum*8 .. muxNum*8+7]`.
- **Porém**: o construtor de `HelloDrum` (pad) com 1 argumento (`HelloDrum pad(pin1)`)
  usa esse `pin1` diretamente como índice em `rawValue`, **sem aplicar o offset do
  MUX automaticamente**. Ou seja, para pads ligados ao 2º, 3º ou 4º MUX, o índice
  passado deve ser calculado manualmente como `muxNum * 8 + canal_local` (ex: pad
  no canal 3 do 3º MUX instanciado → `HelloDrum pad(2*8 + 3)` = `HelloDrum pad(19)`).
  Isso deve ficar claro no código do firmware (idealmente com uma constante/helper
  que deixe esse cálculo explícito, em vez de números mágicos).

**Conclusão prática**: não é necessário modificar a biblioteca para suportar 4x
CD4051 / 32 canais — é uma questão de uso correto da API existente.

## 2026-08-20 — USB-MIDI nativo: Adafruit TinyUSB + FortySevenEffects MIDI Library

**Decisão**: implementar o envio MIDI usando `Adafruit_USBD_MIDI` (biblioteca
`Adafruit TinyUSB Library`) como transporte da `MIDI Library` (FortySevenEffects,
a mesma já usada nos exemplos originais da HelloDrum-lib) — via
`MIDI_CREATE_INSTANCE(Adafruit_USBD_MIDI, usb_midi, MIDI)`. Isso mantém a mesma
API (`MIDI.sendNoteOn()`/`sendNoteOff()`) já usada no código de sensing, só
trocando o transporte de Serial/BLE para USB nativo.

**Contexto/Racional**: o core `arduino-esp32` (verificamos a v3.20017, instalada
no ambiente de dev) não expõe uma classe Arduino de alto nível para USB-MIDI —
só `USBCDC` e `USBMSC`. A camada MIDI só existe no nível baixo do TinyUSB
(`tinyusb/src/class/midi/midi_device.h`, dentro do próprio core). A
`Adafruit_TinyUSB_Arduino` é a forma prática e testada pela comunidade de obter
uma classe MIDI USB de alto nível no ESP32-S3, confirmada lendo o exemplo oficial
`examples/MIDI/midi_test/midi_test.ino` do repositório.

**Configuração de build necessária** (`firmware/platformio.ini`):
- `-D ARDUINO_USB_MODE=0` — muda o modo USB do ESP32-S3 de "Hardware CDC and
  JTAG" (padrão do board `esp32-s3-devkitc-1`, que é `ARDUINO_USB_MODE=1`) para
  "USB-OTG (TinyUSB)", necessário para expor classes USB customizadas como MIDI.
  Confirmado direto no `boards.txt` do core instalado (menu "USB Mode").
- `-D ARDUINO_USB_CDC_ON_BOOT=1` — mantém uma interface CDC (Serial) ativa desde
  o boot, para continuarmos com debug via Serial monitor mesmo com o dispositivo
  USB composto (CDC + MIDI).

**Problema encontrado e contornado — conflito de linker**: o core `arduino-esp32`
3.x já embute uma TinyUSB pré-compilada (`libarduino_tinyusb.a`, usada
internamente por `USB.cpp`/`USBCDC.cpp`/`USBMSC.cpp`) e a `Adafruit TinyUSB
Library` compila a sua própria a partir do código-fonte — as duas juntas
duplicam símbolos (`tusb.c`, `usbd.c`, `usbd_control.c`, etc) e o link falha
("multiple definition of ..."). Contornado adicionando
`-Wl,--allow-multiple-definition` aos `build_flags`, que faz o linker manter a
primeira definição encontrada (a da Adafruit, confirmado pela ordem nas
mensagens de erro antes da correção). Esse é um conflito conhecido dessa
combinação de versões (core 3.x + Adafruit TinyUSB no ESP32), não um bug do
nosso código.

**Status de validação**: o firmware **compila e linka com sucesso**
(RAM 11.1%, Flash 9.5% no `esp32-s3-devkitc-1`), mas **ainda não foi testado em
hardware real** — não temos como confirmar que o dispositivo enumera
corretamente como USB-MIDI (e que o Serial via CDC continua funcionando
simultaneamente, já que é um dispositivo composto) até termos a bancada
montada. Isso é o próximo passo de validação quando o hardware estiver pronto.

**Alternativas descartadas**:
- Implementar a classe MIDI diretamente sobre a API TinyUSB de baixo nível já
  embutida no core (`esp32-hal-tinyusb.c`), no estilo do que `USBCDC.cpp`/
  `USBMSC.cpp` fazem para suas respectivas classes. Mais trabalho manual
  (descritores USB, callbacks de classe) e sem exemplo de referência pronto —
  descartado em favor da solução já testada pela comunidade.

## 2026-08-20 — Tela: TFT ST7735 (SPI) em vez de OLED SSD1306 (I2C)

**Decisão**: usar uma tela TFT 1.44" 128x128, driver ST7735S, interface SPI
(modelo definido pelo usuário por preço — foto em `Modelo Tela.jpeg` na raiz do
projeto), em vez do OLED SSD1306/I2C previsto inicialmente (que era só o
componente usado nos exemplos da HelloDrum-lib, não um requisito do projeto).

**Contexto/Racional**: o requisito original (item 2 do escopo) era só "prever
possibilidade de tela + botões de configuração" — o componente específico
ficou em aberto até o usuário encontrar um modelo com bom preço. A troca para
SPI (em vez de I2C) muda o pinout (6 sinais dedicados: SCL/SCK, SDA/MOSI, RES,
DC, CS, BLK — vs. 2 pinos compartilhados de I2C) e a biblioteca a usar: a
`u8g2` (usada nos exemplos originais da lib) é focada em displays
monocromáticos e não é a escolha natural para uma TFT RGB colorida.

**Biblioteca escolhida**: `Adafruit GFX Library` + `Adafruit ST7735 and
ST7789 Library` — API simples via construtor (`Adafruit_ST7735(cs, dc, rst)`),
sem exigir edição de arquivo de configuração dentro da lib (diferente da
`TFT_eSPI`, que exige customizar `User_Setup.h` ou definir dezenas de
`build_flags` equivalentes). Como o uso aqui é uma tela de configuração (texto,
menus, valores) e não algo performance-crítico, a simplicidade da Adafruit
pesou mais que a velocidade extra da TFT_eSPI.

**A fazer quando implementarmos o código da tela (Fase C)**:
- Adicionar `lib_deps` no `platformio.ini` (`adafruit/Adafruit GFX Library`,
  `adafruit/Adafruit ST7735 and ST7789 Library`).
- Validar se o pino BLK (backlight) fica fixo em 3.3V ou controlado por GPIO
  (permite dimming/desligar a tela).

**Alternativas descartadas**:
- Manter OLED SSD1306/I2C: descartado porque o usuário já encontrou/comprou
  (ou está prestes a) o modelo TFT por preço.
- `TFT_eSPI`: mais rápida (usa DMA/SPI otimizado para ESP32) mas exige mais
  configuração inicial; guardado como alternativa caso a Adafruit se mostre
  lenta demais na prática (o que não é esperado para uma tela de config).

## 2026-08-20 — Navegação: 2 encoders rotativos com chave (em vez de 5 botões)

> **Atualização (Fase J, 2026-08-21)**: mapeamento de rotação/clique
> redesenhado por completo pra navegação de 6 telas — ver entrada "Fase J"
> mais abaixo. **Atualização (Fase Y, 2026-09-04)**: reduzido de 2
> encoders pra 1 só (rotate navega, click desce um nível/confirma, hold
> sobe um nível) — ver entrada "Fase Y". Mantida aqui como registro
> histórico do porquê os encoders (2, na época) foram escolhidos no lugar
> dos 5 botões originais da lib — esse racional continua válido mesmo com
> 1 encoder só.

**Decisão**: usar 2 encoders rotativos com chave (push-button) para navegar e
editar a configuração, em vez dos 5 botões discretos (EDIT/UP/DOWN/NEXT/BACK)
que a classe `HelloDrumButton` pressupõe nos exemplos originais da lib.

**Mapeamento adotado**:
- **Encoder 1 (pad/valor)** — rotação: navega entre pads (fora do modo de
  edição) ou ajusta o valor do parâmetro selecionado (dentro do modo de
  edição) — o comportamento já muda automaticamente conforme o estado interno
  da lib, sem lógica extra nossa. Chave: entra/confirma a edição do item atual
  (equivalente ao botão EDIT/SET).
- **Encoder 2 (item/parâmetro)** — rotação: navega entre os parâmetros do pad
  selecionado (SENSITIVITY, THRESHOLD, SCAN TIME, ..., NOTE) — equivalente aos
  botões NEXT/BACK. Chave: sem função definida ainda (reservada).

**Contexto/Racional**: a lib já expõe exatamente o ponto de extensão certo
para isso — `HelloDrumButton::readButton(bool set, bool up, bool down, bool
next, bool back)` — um overload que recebe os 5 sinais diretamente, em vez de
`readButtonState()` (que leria botões físicos via `digitalRead()` nos pinos do
construtor). Não precisamos modificar a lib: o `main.cpp` lê os 2 encoders
(via a lib `mathertel/RotaryEncoder`, decodificação em quadratura por
interrupção) e a chave de cada um (debounce simples por tempo), traduz cada
evento (giro ou clique) em um "pulso" momentâneo de um dos 5 sinais (LOW só
durante a chamada em que o evento ocorreu, HIGH nas demais — imita uma
pressionada rápida de botão físico) e chama `readButton()` manualmente a cada
`loop()`. `HelloDrum::settingEnable()` (chamado para todos os pads a cada
`loop()`, como nos exemplos originais) continua lendo os mesmos sinais
internamente, sem saber a diferença entre um botão físico e um encoder.

O construtor de `HelloDrumButton` ainda exige 5 pinos, mas como nunca chamamos
`readButtonState()` (só `readButton()` manualmente), esses pinos nunca são
lidos — usamos `255` como placeholder.

**Bug/pegadinha encontrada durante a implementação**: `HelloDrum::settingName()`
não é só cosmético — além de guardar o nome do pad em `showInstrument[]`, ele
incrementa `nameIndexMax` (variável global da lib que limita até onde a
navegação entre pads pode ir). Sem chamar `settingName()` uma vez por pad na
inicialização, `nameIndexMax` fica 0 e a navegação via encoder fica travada no
pad 0. Além disso, `settingName()` guarda o **ponteiro** que recebe (não copia
a string) — por isso os nomes dos pads (`"Pad 1"`, `"Pad 2"`, ...) são escritos
num buffer `static`/global (`padNames[NUM_PADS][8]` em `main.cpp`) que dura o
programa todo, e não num buffer temporário de escopo local (que causaria um
ponteiro pendente/lixo de memória depois de sair do loop de setup).

**Biblioteca escolhida para os encoders**: `mathertel/RotaryEncoder` —
decodificação em quadratura testada e estável, funciona bem por interrupção
(`attachInterrupt` + `tick()` nos pinos A/B de cada encoder), sem exigir
hardware dedicado (PCNT) do ESP32.

**Status de validação**: build compila e linka com sucesso. **Ainda não
testado em hardware real** — nem os encoders, nem a tela, nem os 4x CD4051
foram montados na bancada até agora. Pontos que só dão pra confirmar com
hardware real: sentido de giro dos encoders (CW/CCW pode estar invertido
dependendo da fiação — fácil de corrigir trocando A/B ou invertendo o sinal no
código), e se o `LatchMode::FOUR3` é o mais adequado para o modelo de encoder
usado (pode precisar de `FOUR0` dependendo do encoder).

**Alternativas descartadas**:
- 5 botões discretos (EDIT/UP/DOWN/NEXT/BACK), como nos exemplos originais da
  lib: descartado por preferência do usuário (encoders dão uma navegação mais
  compacta e fluida com menos componentes físicos no painel).
- Usar a chave do encoder 2 para alguma função imediatamente: deixada em
  aberto por enquanto (reservada) até surgir uma necessidade concreta (ex:
  atalho para "salvar tudo"/"voltar pra tela inicial").

## 2026-08-20 — Persistência: EEPROM (NVS) com flag de primeiro boot

**Decisão**: ativar `EEPROM_ESP` (já presente na lib, wrapper sobre NVS do
ESP32) com um layout de 10 bytes por pad (320 bytes pros 32 pads) + 1 byte
extra usado como flag de "já inicializado" (endereço `NUM_PADS*10`, valor
mágico `0xA5`). No `setup()`: se a flag não bater, chama
`HelloDrum::initMemory()` pra cada pad (grava os valores padrão em EEPROM);
senão, chama `HelloDrum::loadMemory()` (restaura o que foi salvo, incluindo
edições feitas via os encoders em boots anteriores).

**Contexto/Racional**: adiamos isso nas Fases A-C de propósito (ver entrada de
2026-08-20 sobre USB-MIDI/Fase C) porque ativar `EEPROM_ESP.begin()` sem um
fluxo de primeiro-boot deixaria `sensitivity`/`threshold1`/etc como `0` (bytes
não inicializados do NVS), o que quebra o sensing (threshold 0 = dispara com
qualquer ruído). A flag de primeiro boot resolve isso: só usamos os valores
lidos da EEPROM depois de termos certeza que ela foi gravada com
`initMemory()` alguma vez.

As escritas feitas durante o uso normal (girar o encoder em modo de edição)
**não precisam de nenhum código nosso** — `HelloDrum::settingEnable()` já
escreve e comita no EEPROM sozinho a cada mudança (é assim que a lib original
já funciona com botões físicos; com os encoders é a mesma coisa, já que
alimentamos os mesmos sinais via `readButton()`).

**Bug encontrado e corrigido na lib vendorizada**: no branch de incremento
(UP) do item SENSITIVITY (item 0) dentro de `settingEnable()`, o endereço de
EEPROM usado era `padNum * 8` — inconsistente com **todos** os outros 9 itens
e com o branch de decremento (DOWN) do próprio item 0, que usam
`padNum * 10`. Isso faria incrementar a sensibilidade de qualquer pad com
`padNum >= 1` sobrescrever um byte de EEPROM de **outro** pad (ex: pad 1
gravaria no endereço 8, que é o campo `noteRim` do pad 0). Corrigido para
`padNum * 10` nos dois branches (ESP32 e AVR) em `hellodrum.cpp`. Esse bug só
foi percebido agora porque a Fase D foi a primeira vez que a persistência
ficou realmente ativa — nas fases anteriores as escritas eram sempre
no-ops silenciosos (EEPROM nunca inicializada).

**Status de validação**: build compila e linka. **Teste em hardware real
ainda pendente** — falta confirmar que os valores realmente persistem entre
reboots (não temos como simular reboot com NVS real sem a placa física).

**Alternativas descartadas**:
- Detectar "primeiro boot" checando se `sensitivity == 0` (em vez de uma flag
  dedicada): descartado por ser um heurística frágil — um valor legítimo
  poderia coincidir, e não cobre todos os campos.

## 2026-08-20 — Interface desktop: Electron + React/TypeScript, protocolo NDJSON via Serial

**Decisão**: interface desktop em Electron + React + TypeScript (build via
`electron-vite`), comunicando com o módulo por porta serial USB-CDC usando um
protocolo texto linha-a-linha em JSON (NDJSON) — não MIDI SysEx.

**Contexto/Racional**: perguntado diretamente ao usuário (duas decisões sem
trade-off óbvio a favor de uma só opção):
- **Stack**: Electron+React foi escolhido entre as opções apresentadas
  (Python+Qt, .NET/WPF-Avalonia, Tauri+React) — UI web é um bom encaixe pra
  uma tela com grid de 32 pads x ~6 parâmetros cada, e Electron empacota bem
  pra Windows.
- **Protocolo**: Serial+JSON em vez de MIDI SysEx — o módulo já expõe uma
  porta CDC desde a Fase B (`ARDUINO_USB_CDC_ON_BOOT=1`), sem custo extra, e é
  muito mais simples de implementar/debugar dos dois lados (dá pra testar com
  qualquer terminal serial, sem precisar decodificar SysEx). O contrato
  completo está em [04-protocolo-serial.md](04-protocolo-serial.md).

**Firmware (Fase E)**: adicionada a lib `bblanchon/ArduinoJson` e um
protocolo NDJSON sobre a mesma porta Serial já usada desde a Fase B — todo o
tráfego (comandos, respostas, eventos de hit, logs de boot) passou a ser
JSON, uma linha por objeto. Antes disso, os eventos de hit e as mensagens de
boot eram `Serial.print` em texto livre; converter tudo pra JSON evita ter
que filtrar/distinguir linhas de debug de linhas de protocolo do lado do app.
Leitura da porta serial no firmware é não-bloqueante (acumula caracteres até
`\n` a cada `loop()`, sem usar `Serial.readStringUntil()` com timeout, que
pausaria o sensing/MIDI).

**"Modo demo"**: o app tem uma opção de simular o módulo inteiramente no
renderer (`mockDevice.ts`), sem tocar em porta serial nenhuma — permite
validar/demonstrar a UI antes do hardware estar montado (mesma lógica por
trás de termos priorizado "compila e builda" como critério de validação em
todas as fases do firmware).

**Vulnerabilidades de dependências corrigidas antes de seguir**: o scaffold
inicial (`electron@^31`, `vite@^5`) tinha CVEs conhecidos (Electron: várias
falhas de sandbox/IPC; esbuild/vite: servidor de dev expondo requisições a
qualquer site). Atualizado para `electron@^43`, `vite@^7`, `@vitejs/plugin-
react@^5.2` (a v6 do plugin-react exige vite^8, que por sua vez não é
suportado pelo `electron-vite@^5` ainda — ver changelog do `electron-vite`
antes de tentar subir pra vite 8). `npm audit` limpo (0 vulnerabilidades)
nessa combinação de versões.

**Status de validação**: `npm run typecheck` e `npm run build` passam limpo.
**Nunca testado com o módulo real** (sem hardware) — só o modo demo foi
exercitado, e mesmo assim não com uma execução real de `npm run dev` (só
build estático) nesta sessão.

**Alternativas descartadas**:
- Python + PySide6, .NET (WPF/Avalonia), Tauri+React: alternativas viáveis,
  descartadas só por preferência do usuário nessa decisão, não por algum
  defeito técnico.
- MIDI SysEx como protocolo de config: mais "elegante" (um único cabo/
  interface), mas mais complexo dos dois lados e sem nenhum parsing de SysEx
  já implementado no firmware — descartado em favor de Serial+JSON.

## 2026-08-20 — Nome livre por pad, editável só pelo app desktop

**Decisão**: cada pad ganha um "label" de texto livre (ex: `"Caixa"`),
persistido em EEPROM, editável **exclusivamente** via o app desktop (comando
`set_pad` com `field: "label"`, protocolo serial). O número do pad nunca é
editável. O nome exibido (tela TFT e app) é sempre `"N - label"` (1-based) ou
só `"Pad N"` enquanto nenhum label tiver sido definido.

**Contexto/Racional**: pedido direto do usuário. A escolha de "só pelo app
desktop" (não pelos encoders/TFT) evita ter que resolver entrada de texto
numa tela de 128x128 com 2 encoders (giro+clique não dá um jeito natural de
digitar texto livre sem inventar um teclado on-screen) — um teclado
físico+mouse no desktop já resolve isso de forma trivial.

**Implementação**:
- Firmware: `padLabels[NUM_PADS][20]` (texto livre) + `padNames[NUM_PADS][28]`
  (nome final formatado, é o que a lib recebe via `settingName()`) em
  `main.cpp`. `rebuildPadName(i)` recalcula `padNames[i]` a partir de
  `padLabels[i]` sempre que o label muda. Como `padNames[i]` é um buffer
  mutável (não um `const char*` fixo), atualizar seu conteúdo já reflete
  automaticamente no que `HelloDrumButton::GetPadName()` devolve (usado pela
  tela) — não precisa chamar `settingName()` de novo.
- EEPROM: layout extendido com mais `NUM_PADS * 20` bytes (20 bytes fixos por
  pad, incluindo terminador nulo) depois da flag de primeiro-boot já
  existente (Fase D). Usa `EEPROM_ESP.readBytes()`/`writeBytes()` (slots de
  tamanho fixo, mais simples que `readString()`/`writeString()` pra esse
  caso).
- Protocolo: reaproveitado o comando `set_pad` já existente (campo `field`
  agora aceita `"label"` além dos numéricos), em vez de criar um comando
  novo tipo `set_pad_name` — mantém o protocolo mais uniforme. Único ponto
  assimétrico: `set_pad` com campos numéricos responde com `ack`, mas com
  `field: "label"` responde com o `pad_config` inteiro (mais útil pro app já
  receber o `name` recalculado, e evita inventar um tipo de resposta só pra
  string). Documentado em [04-protocolo-serial.md](04-protocolo-serial.md).

**Efeito colateral (não era o objetivo, mas é consequência direta)**: como a
tela TFT também usa `GetPadName()` pra exibir o nome do pad selecionado, um
pad renomeado via o app aparece com o nome novo na tela física também, sem
código extra — é o mesmo dado, uma única fonte de verdade.

**Status de validação**: build/typecheck do firmware e do app passam limpo.
**Nada testado em hardware real.**

**Alternativas descartadas**:
- Comando dedicado `set_pad_name` (em vez de reaproveitar `set_pad` com
  `field: "label"`): descartado pra não duplicar a validação de `pad` e
  manter só um comando de "alterar campo de um pad".
- Permitir renomear pelos encoders também: descartado pelo próprio usuário
  (edição de texto livre com 2 encoders é uma UX ruim sem um teclado
  on-screen, que não estava no escopo).

## 2026-08-20 — Tipos de sensor: todos os 8, topologia de canais configurável pelo app

**Decisão**: implementar os 8 tipos de sensor documentados pela
HelloDrum-lib (ver [05-tipos-de-sensor.md](05-tipos-de-sensor.md) pro
detalhamento), com a topologia (qual canal é qual tipo, e quais 2 canais
formam um pad de 2 zonas) configurável em runtime só pelo app desktop,
persistida em EEPROM — mesmo padrão já usado pro nome do pad (Fase F).

**Contexto/Racional**: perguntado diretamente ao usuário (duas decisões de
escopo genuinamente abertas — quantos tipos implementar, e onde configurar a
topologia). Escolhido o escopo mais completo porque a lógica de sensing em
si já existe pronta na lib (não precisávamos escrever isso do zero) — o
trabalho real foi o despacho por tipo e a modelagem da topologia.

**O problema central**: o construtor de `HelloDrum` (`pin_1`/`pin_2`) só
aceita pinos no momento da construção — não existe setter público pra
trocar os canais de um pad depois de criado. Isso pareceria exigir destruir
e reconstruir objetos `HelloDrum` toda vez que o usuário mudasse o tipo de
um pad via o app (arriscado e complicado em C++ embarcado).

**Solução**: construir **todos** os 32 objetos `HelloDrum` já com 2 pinos
desde o boot (`HelloDrum(i, i+1)` para `i` de 0 a 30, e `HelloDrum(31)` pro
último, que não tem `i+1`). Métodos de sensing de 1 canal (`singlePiezoMUX()`,
`hihatControlMUX()`, etc) simplesmente nunca leem `pin_2` — não há problema
em ele "existir" sem ser usado. Métodos de 2 canais (`dualPiezoMUX()`,
`cymbal2zoneMUX()`, etc) leem `pin_2` normalmente. Resultado: **nunca
precisamos reconstruir nada** — trocar o tipo de um pad em runtime é só
trocar qual método chamamos nele a cada `loop()` (`dispatchSensing()` em
`main.cpp`), uma tabela de despacho baseada num `byte padTypes[32]` que o
app pode alterar livremente.

**Canais consumidos**: quando `padTypes[i]` é um tipo de 2 canais, o canal
`i+1` fica "consumido" — não é sensoreado nem exposto como pad
independente. Isso é **derivado**, não guardado explicitamente: uma função
`recomputeChannelPrimary()` recalcula um array `bool channelPrimary[32]`
toda vez que algum `padTypes[]` muda, percorrendo os canais em ordem (canal
`i` é consumido se o canal `i-1` for primário **e** seu tipo usar 2 canais -
recursão de profundidade 1 só, já que nenhum tipo usa mais de 2 canais, não
há como formar correntes de 3+). Trocar um pad de volta pra um tipo de 1
canal libera o seguinte automaticamente, sem nenhuma limpeza manual.

**Restrição no encoder/TFT**: `nameIndex`/`nameIndexMax` (globais internas
da lib) não são resetáveis de fora de `hellodrum.cpp` (mesmo problema de
`static` com linkage interno já documentado na entrada de
2026-08-20 sobre encoders). Por isso, `settingName()` continua sendo chamado
pra todos os 32 canais no boot (não só os primários) — a navegação pelos
encoders sempre alcança as 32 posições, mas ao chegar num canal consumido a
tela mostra "Canal ocupado" em vez de item/valor (`renderScreen()` usa
`currentPadIndex()` — um truque de comparação de ponteiro, já que não existe
getter pra ler o `nameIndex` bruto: como `GetPadName()` devolve exatamente o
mesmo ponteiro que passamos em `settingName(padNames[i])`, comparar
`padNames[i] == button.GetPadName()` recupera o índice atual de forma
confiável).

**Hi-hat = 2 pads linkados**: a lib não faz a ligação entre o pedal
(`hihatControlMUX()`/`TCRT5000MUX()`, que atualizam `openHH`/`closeHH`) e o
prato/chimbal em si (`HHMUX()`/`HH2zoneMUX()`, que **não** olham esses
campos - confirmado lendo `FSRSensing()`/`TCRT5000Sensing()` e
`singlePiezoSensing()`/`cymbal2zoneSensing()` em `hellodrum.cpp`). Por isso
os tipos de chimbal (2/4) ganharam um campo `hihat_pedal_channel` (índice de
outro pad, tipo 6 ou 7) — nosso próprio código (`handlePadResult()`) lê o
`openHH` do pad linkado pra decidir qual nota usar. Sem link, assume "sempre
aberto".

**Limitação herdada e simplificação feita**: a lib só tem 3 slots de nota
independentes por pad (`note`/`note_rim`/`note_cup`), e `note_rim` seta 4
campos internos da lib pro mesmo valor de uma vez (`noteRim`, `noteEdge`,
`noteClose`, `noteOpenEdge` — mesmo aliasing que `settingEnable()` já faz).
Isso significa que não dá pra ter uma nota diferente pra "borda com o
chimbal aberto" vs "fechado" — os dois usariam o mesmo valor. Simplificamos
o despacho do chimbal 2 zonas pra refletir isso honestamente: só a zona do
corpo (bow) distingue aberto/fechado; a borda usa sempre `note_rim`,
independente do estado do pedal. Ver
[05-tipos-de-sensor.md](05-tipos-de-sensor.md).

**Status de validação**: build/typecheck do firmware e do app passam limpo.
**Nada testado em hardware real** — em especial, não temos como confirmar a
faixa real de `pad.pedalCC` nem o comportamento de `HH2zoneMUX()` num
chimbal físico 2 zonas de verdade.

**Alternativas descartadas**:
- Reconstruir os objetos `HelloDrum` dinamicamente (`new`/`delete`) quando o
  tipo de um pad muda: tecnicamente possível no ESP32, mas mais arriscado e
  sem necessidade real, dado que construir todos com 2 pinos desde o início
  resolve o mesmo problema de forma mais simples.
- Deixar a topologia fixa no código-fonte (não configurável em runtime):
  descartado pelo usuário — o objetivo é poder reconfigurar o kit sem
  recompilar/reflashear.
- Permitir canais não-adjacentes formarem um pad de 2 zonas (ex: canal 3 +
  canal 20): descartado por complexidade desproporcional ao ganho — a
  convenção "sempre o canal seguinte" já resolve o problema de forma simples
  e o usuário só precisa cabear o 2º sensor no próximo slot do MUX.

## 2026-08-20 — BLE-MIDI como transporte adicional (simultâneo ao USB-MIDI)

**Decisão**: enviar todo hit/CC tanto por USB-MIDI (Fase B) quanto por
BLE-MIDI, simultaneamente — não é um "modo" que se escolhe, os dois
transportes ficam sempre ativos, e o BLE só efetivamente transmite quando
houver um dispositivo pareado.

**Contexto/Racional**: o pedido foi "implementar também o modo BLE-MIDI" —
li isso como "adicionar", não "substituir". Como os dois transportes usam
periféricos independentes do ESP32-S3 (USB OTG vs. rádio 2.4GHz) e a
biblioteca já expõe um jeito de saber se há alguém pareado
(`setHandleConnected`/`setHandleDisconnected`), simultâneo ficou mais simples
de implementar do que um esquema de troca de modo (que exigiria persistir
"modo atual" em EEPROM, expor isso no protocolo/app, etc. — sem ganho claro
já que os dois cabem ao mesmo tempo).

**Biblioteca escolhida**: `lathoub/Arduino-BLE-MIDI` (BLE-MIDI 1.0), a mesma
que os exemplos originais da HelloDrum-lib já usam
(`examples/BLE/SimpleSensing_BLEMIDI`, `examples/MUX/muxSensing_BLEMIDI`) —
confirmei a API lendo esses exemplos e o código-fonte da lib direto do
GitHub antes de escrever qualquer coisa. Ela usa a mesma `MIDI Library`
(FortySevenEffects) que já usávamos pro USB, só troca o transporte — mesmo
padrão da Fase B (Adafruit_USBD_MIDI).

**Bluedroid em vez de NimBLE**: essa lib suporta duas stacks BLE no ESP32,
escolhidas por qual header se inclui — `hardware/BLEMIDI_ESP32.h` (Bluedroid,
já embutida no core `arduino-esp32`, sem dependência extra) ou
`hardware/BLEMIDI_ESP32_NimBLE.h` (precisa da lib `h2zero/NimBLE-Arduino`
separada). Escolhemos Bluedroid pra não introduzir mais uma dependência de
terceiros com compatibilidade de versão incerta com o nosso core (3.20017) —
NimBLE é mais leve em RAM/flash e geralmente recomendado pra projetos novos,
mas nosso orçamento de recursos já está confortável mesmo com Bluedroid (ver
abaixo), então não valeu a pena o risco extra agora. Trocar pra NimBLE depois
é só troca de `#include`, as macros (`BLEMIDI_CREATE_INSTANCE`) são
idênticas nos dois casos.

**Evitando colisão de nomes**: `BLEMIDI_CREATE_DEFAULT_INSTANCE()` (usada
nos exemplos originais) cria uma variável chamada `MIDI` — colidiria com o
`MIDI` que já usamos pro USB. Usamos `BLEMIDI_CREATE_INSTANCE("DrumCore",
BleMidi)` em vez do default — isso nomeia a interface MIDI como `BleMidi` e,
como efeito colateral da macro, cria também um objeto de transporte chamado
`BLEBleMidi` (prefixo `BLE` + nome escolhido) — é nele (não em `BleMidi`)
que registramos os callbacks de conexão. `"DrumCore"` é o nome anunciado via
Bluetooth (o que aparece ao parear).

**Consumo de recursos**: build antes de adicionar BLE — RAM 11.9%, Flash
10.9%. **Depois** — RAM 19.8%, Flash 30.0% (de 327680 bytes de RAM e
3342336 bytes de Flash disponíveis). O salto grande é em Flash (a stack
Bluedroid é pesada), mas
ainda com bastante margem no board N8 (8MB). Nenhum conflito de biblioteca
apareceu — o `library.properties` da BLE-MIDI declara `NimBLE-Arduino` e
`ArduinoBLE` como dependências (usadas só pelas variantes de hardware que
não usamos), mas o LDF do PlatformIO (modo "chain", segue os `#include`
reais) não tentou puxar nenhuma das duas.

**Status de validação**: build compila e linka com sucesso. **Nada testado
em hardware real** — isso é ainda mais especulativo que as fases anteriores,
porque compilar não garante que USB-MIDI e BLE-MIDI realmente coexistem em
runtime sem briga de stack/watchdog, nem que o pareamento (a lib usa
`ESP_LE_AUTH_BOND`, ou seja, pede bonding) funciona de primeira em iOS/
Android/Windows. Validar isso é o próximo passo assim que houver hardware.

**Alternativas descartadas**:
- Modo único selecionável (USB *ou* BLE, não os dois): descartado — mais
  complexidade (persistência de modo, UI pra trocar) sem necessidade, já
  que os dois transportes cabem ativos ao mesmo tempo sem conflito aparente.
- NimBLE-Arduino: mais leve, mas dependência extra de terceiros sem
  necessidade imediata dado que Bluedroid já cabe confortavelmente no
  orçamento de flash/RAM atual — guardado como alternativa se surgir
  problema real de recursos ou estabilidade em hardware.

## 2026-08-20 — Tela inicial (grid de pads) + velocímetro na configuração

**Decisão**: a tela TFT ganhou dois estados novos — uma **tela inicial**
(grid 8x4 com o número de cada pad, que acende verde ao ser atingido) que
aparece quando o módulo está ocioso, e um **velocímetro** (arco + agulha)
na tela de configuração, mostrando visualmente onde o valor atual do
parâmetro cai entre o mínimo e o máximo.

**Contexto/Racional**: pedido direto do usuário, pra tornar a tela mais
"bonitinha"/útil no dia a dia (ver ela tocando em vez de só um menu estático
de configuração). O grid 8x4 não é arbitrário — mapeia direto pra `i =
mux*8 + canal`, então cada LINHA do grid corresponde a um CD4051 físico. Não
tentamos mostrar `padType`/consumo de canal nessa tela (ficaria poluído) —
canais consumidos simplesmente nunca acendem (nunca recebem hit), o que já
é auto-explicativo na prática.

**Transição entre telas**: baseada em tempo sem interação
(`lastConfigInteractionMs`, atualizado em `processConfigInput()` a cada
evento real de qualquer encoder) — depois de `IDLE_TIMEOUT_MS` (4s) sem
nenhum giro/clique, a tela volta pro grid. Qualquer interação leva de volta
pra tela de configuração imediatamente. Não distinguimos "está editando" vs
"só navegando" pra esse timeout — qualquer input já reseta o relógio, então
não há risco de a tela "fugir" pro grid no meio de um ajuste de valor.

**Velocímetro sem suporte nativo a arco**: a Adafruit_GFX não tem desenho
de arco — aproximamos com segmentos de reta via trigonometria (5 marcas
fixas + 1 agulha, arco de 150° a 30°, abrindo pra baixo — visual clássico
de painel). Implementado em `drawGauge()`.

**De onde vem o min/max de cada parâmetro**: a lib não expõe isso
estruturado (só o rótulo em texto via `GetSettingItem()`), então
`getGaugeRange()` decide a faixa por *substring* no rótulo (`"SENS"` /
`"THRE"` / `"SCAN"` / `"MASK"` → 1-100, `"CURVE"` → 0-4, `"NOTE"` → 0-127) —
cobre todos os rótulos que existem nos arrays `item[]`/`itemD[]`/
`itemCY2[]`/`itemCY3[]`/`itemHH[]`/`itemHH2[]`/`itemHHC[]` de `hellodrum.h`
(confirmado lendo cada um). No app desktop isso já existe de forma
estruturada (`FieldSpec.min`/`.max` em `protocol.ts`), então o simulador usa
essa fonte diretamente, sem precisar do hack de substring.

**Simulador atualizado em paralelo**: `HardwareSimulator.tsx` replica os
dois estados novos (grid com hits simulados periodicamente, velocímetro via
SVG) usando as mesmas constantes de tempo (`IDLE_TIMEOUT_MS`,
`PAD_FLASH_MS`) pra ficar fiel ao firmware (esse simulador — e o doc que o
descrevia — foi removido do app desktop em 2026-09-04, ver Fase Y mais
abaixo).

**Status de validação**: build/typecheck do firmware e do app passam
limpo. **Nada testado em hardware real** — em especial, a legibilidade do
velocímetro numa tela física de 1.44" (bem menor que a visualização em
tela de computador) só dá pra confirmar na prática; pode precisar de
ajuste de raio/posição.

**Alternativas descartadas**:
- Mostrar o `padType` ou status de canal consumido na tela inicial:
  descartado por poluir uma tela pensada pra ser só "ver o que está
  tocando" — essa informação já está disponível na tela de configuração e
  no app desktop.
- Barra de progresso linear em vez de velocímetro: mais simples de
  desenhar (só `fillRect` proporcional), mas o usuário pediu
  especificamente o visual de velocímetro.

## 2026-08-21 — Fase J: rebranding "DrumCore" + redesenho completo da navegação (design/SPEC.md)

**Decisão**: renomear o projeto de "HelloDrum" para "DrumCore" (exibido como
"DRUMCORE" em telas/branding, "DrumCore" em prosa) e substituir inteiramente
o sistema de tela/encoders das Fases C/I por uma navegação de 6 telas (BOOT,
LIVE, PADS, PAD_EDIT, SIGNAL, GLOBAL), seguindo uma especificação de UI
(`design/SPEC.md` + `design/Modulo Bateria UI.dc.html`) produzida com Claude
Design a partir de uma conversa do usuário fora dessa sessão.

**Contexto/Racional**: pedido direto do usuário ("bati um papo com o claude
design... vamo implementar essa UI"). A biblioteca de terceiros vendorizada
(`firmware/lib/HelloDrum-arduino-Library`, de Ryo Kosaka) **não** faz parte
do rebranding — mantém seu nome, arquivos (`hellodrum.h`/`hellodrum.cpp`) e
identificadores de classe (`HelloDrum`, `HelloDrumMUX_4051`,
`HelloDrumButton`) originais. A pasta raiz do repositório também não foi
renomeada (só o texto de branding em código/docs/UI).

**O antigo sistema de tela/botões foi abandonado, não estendido**: as Fases
C/I giravam em torno de `HelloDrumButton::readButton()`/`settingEnable()` —
um fluxo desenhado pros 5 sinais (SET/UP/DOWN/NEXT/BACK) que os exemplos
originais da lib esperam, e que já tínhamos adaptado pra 2 encoders (ver
entrada de 2026-08-20 sobre navegação). O novo spec pede uma máquina de
estados com semântica bem diferente (2 encoders com papéis distintos —
"página" vs. "navegação/valor" —, gestos de hold de 600ms, edição em RAM
com persistência só sob confirmação explícita) que não mapeia de forma
natural pra esse fluxo de 5 sinais. Optamos por implementar a navegação
inteira em `main.cpp` (novo `enum ScreenPage`, `FieldId`/`FieldDef` +
`getFieldsForType()`/`getFieldValue()`/`setFieldValue()`, detecção de
hold/aceleração por timestamp) e parar de chamar
`HelloDrumButton::readButton()`/`settingEnable()`/`GetPadName()` etc. —
`HelloDrumButton` deixou de ser instanciado. A lib continua fornecendo só a
camada de sensing (`singlePiezoMUX()`, `dualPiezoMUX()`, etc.) e persistência
(`initMemory()`/`loadMemory()`), que não mudou.

**Sistema de campos dinâmico por tipo de sensor (`getFieldsForType()`)**:
o spec original prevê 7 campos fixos por pad (SENSOR/SENSIB/THRESH/SCAN/
MASK/CURVA/NOTA), mas a Fase G já tinha implementado os 8 tipos de sensor
da lib, alguns com mais campos (ex: prato 3 zonas tem thresholds e notas
extras pra edge/cup — até 10 campos). Optamos por manter o modelo de dados
mais rico da Fase G (não reduzir pra só 4 tipos/7 campos como o spec
simplificado sugeria) e fazer a tela PAD_EDIT rolar quando o tipo tem mais
de 7 campos — mesma janela deslizante de 7 linhas usada na lista PADS,
reaproveitando o padrão. `getFieldsForType()` espelha
`PAD_TYPE_META[type].fields` do app desktop (`protocol.ts`), mas descrevendo
como ler/escrever cada campo direto nos membros públicos de `HelloDrum` (via
`getFieldValue()`/`setFieldValue()`), em vez de passar pelo fluxo de botões
da lib.

**Persistência: RAM-only nos encoders, auto-save no protocolo serial
(divergência intencional)**: o spec é explícito — "Edição altera apenas o
buffer em RAM. Persistência só acontece em GLOBAL > SALVAR." Implementamos
isso literalmente pro caminho dos encoders/tela: `setFieldValue()` só
altera os campos em RAM (seta uma flag `unsavedChanges`); só
`saveAllToEeprom()` (chamado em `GLOBAL > SALVAR`) grava de fato, e
`loadAllFromEeprom()` (`GLOBAL > RESTAURAR`) descarta as mudanças não
salvas recarregando da EEPROM. **Mantivemos, de propósito, o comportamento
antigo pro protocolo serial** (`handleSetPad()`/`handleSetGlobal()`
continuam persistindo a cada campo alterado, como desde a Fase D/F) — o app
desktop não tem (e não ganhou) um botão "salvar" equivalente ao da tela
física, então esperar que o usuário abra a aba GLOBAL do app e clique
"Salvar tudo" toda vez que arrasta um slider seria pior UX do que já
funcionava. Os comandos `save_all`/`restore_all` foram adicionados ao
protocolo mesmo assim (documentados em
[04-protocolo-serial.md](04-protocolo-serial.md)), pra permitir que o app
espelhe as mesmas ações da tela quando fizer sentido (ex: descartar edições
feitas nos encoders antes de salvar) — na prática, redundante no caminho
`set_pad`/`set_global`, mas não custa nada expor.

**"SAIDA" (GLOBAL) virou USB/BLE/USB+BLE, não USB/DIN/USB+DIN**: o spec
original (pensado sem contexto do nosso hardware específico) previa DIN
(MIDI 5 pinos) como uma das opções de saída — não existe esse circuito no
projeto (só USB-MIDI da Fase B e BLE-MIDI da Fase H). Em vez de implementar
um "DIN" que nunca faria nada (stub morto), reinterpretamos a mesma posição
na tela GLOBAL como USB/BLE/USB+BLE — as opções reais que o hardware tem.
Isso muda o comportamento de `fireNote()`/`fireControlChange()`: antes (Fase
H) os dois transportes saíam sempre juntos; agora um `byte midiOutput`
(persistido) decide se USB, BLE, ou os dois recebem cada nota/CC.

**"KIT" foi removido do spec, não implementado nem como placeholder**: o
spec original pede um campo "KIT (01-nn)" na tela GLOBAL, sem detalhar o
que uma troca de kit deveria fazer (múltiplos bancos de configuração de
pads selecionáveis por kit). Perguntamos ao usuário se valia implementar
de verdade ou só deixar fixo como placeholder; a resposta foi explícita —
"não vamos implementar isso não, sem kits por enquanto". Por isso o campo
não existe em lugar nenhum: nem `kitNumber` no firmware (nem em RAM, nem em
EEPROM — o bloco de config global ficou com 3 bytes, não 4), nem
`kit_number` no protocolo serial (`set_global`/`device_info`), nem na tela
GLOBAL (que ficou com 5 linhas: MIDI CH, SAIDA, BRILHO, SALVAR, RESTAURAR —
não 6), nem no app desktop ou no `HardwareSimulator.tsx`. Se o recurso for
pedido de novo no futuro, é uma feature nova a projetar do zero (formato de
persistência por kit, o que cada kit duplica ou não), não uma retomada de
código existente.

**Correção de linkage na lib vendorizada — `rawValue[]`**: a tela SIGNAL
(osciloscópio simplificado do envelope do sensor) precisa que `main.cpp`
leia os valores brutos do ADC que `HelloDrumMUX_4051::scan()` grava (dentro
de `hellodrum.cpp`). O array `rawValue[]` era declarado `static` direto no
header (`hellodrum.h`) — igual ao problema já documentado com
`nameIndex`/`editCheck`/`padType[]` nas entradas anteriores, um `static` no
escopo de arquivo/header vira uma cópia **separada e desconectada** por
`.cpp` que faz `#include` (linkage interno), não uma variável
compartilhada. Trocado para `extern int rawValue[64]` no header + a
definição real (`int rawValue[64]`) uma única vez em `hellodrum.cpp`, junto
do resto do estado interno da lib. Essa é a quarta vez que esse mesmo
padrão de bug aparece nessa biblioteca — vale ficar atento a outras
variáveis `static` de escopo de arquivo se precisarmos ler mais estado
interno de fora no futuro.

**Tela SIGNAL usa um envelope aproximado, não uma captura alinhada ao
hit**: o ideal seria capturar exatamente as amostras do ADC durante a
janela de scan/mask de um hit específico. Isso exigiria instrumentar
`hellodrum.cpp` mais a fundo (fora do escopo de "só ler o que já existe").
Optamos por manter um buffer de 120 amostras como uma janela deslizante
contínua do canal em foco, atualizada a cada `loop()` enquanto a tela
SIGNAL está visível, e redesenhada só quando percebemos um hit novo — na
prática mostra o formato geral do envelope de um hit recente, mas não é uma
captura cirurgicamente alinhada ao início do scan. Documentado como
simplificação deliberada no comentário de `captureSignalSample()`.

**Reskin do app desktop (Electron/React)**: paleta e tipografia seguem os
mesmos tokens da tela do módulo (`design/SPEC.md` seção 4: BG/SURFACE/LINE/
TXT_DIM/TXT/ACCENT/EDIT/HIT/OK; fontes Silkscreen + Space Grotesk, via
Google Fonts — exigiu abrir a CSP do `index.html` pra `fonts.googleapis.com`/
`fonts.gstatic.com`, já que o app é Electron com acesso à rede, não um
artifact restrito). A API exposta pelo preload (`contextBridge`) foi
renomeada de `window.helloDrum` para `window.drumCore` (`preload/index.ts`,
`env.d.ts`, `App.tsx`). Nova aba "Global" no app pra configurar canal MIDI/
saída/brilho via `set_global` (sem KIT — ver acima, o campo não existe).
`HardwareSimulator.tsx` foi reescrito do zero (não incrementado) pra
espelhar a nova máquina de 5 páginas em runtime (BOOT não entra, dura só a
inicialização) e a nova semântica dos 2 encoders, incluindo o gesto de hold
de 600ms — simulado no navegador via `onMouseDown`/`onMouseUp` com um
`setTimeout`, já que não existe equivalente nativo de "manter pressionado"
num `<button>` HTML.

**Status de validação**: firmware compila e linka com sucesso via
PlatformIO (`pio run`); app desktop com `npm run typecheck` e `npm run
build` limpos. **Nada testado em hardware real** — em especial, a
legibilidade das 6 telas numa TFT física de 1.44" (bem menor que qualquer
preview), o sentido/aceleração dos encoders, e se o brilho via PWM
(`ledcSetup`/`ledcAttachPin`/`ledcWrite` — API do core 3.x, mais antiga que
o `ledcAttach()` de uma linha que tentamos primeiro e não existe nessa
versão do core) fica suave ou "degrau" na prática.

**Alternativas descartadas**:
- Manter `HelloDrumButton`/`readButton()` e só trocar os textos exibidos:
  descartado porque a semântica de encoder do spec (papéis fixos por
  encoder, hold, edição em RAM) não é representável pelos 5 sinais
  SET/UP/DOWN/NEXT/BACK sem gambiarras piores do que reescrever a
  navegação direto em `main.cpp`.
- Reduzir o modelo de dados de pad pra só os 4 tipos/7 campos do spec
  simplificado: descartado — perderíamos os 8 tipos de sensor da Fase G
  sem necessidade real, só pra bater 1:1 com um mockup que não tinha
  contexto do nosso escopo mais amplo.
- Implementar "DIN" como opção morta na tela GLOBAL (só pra bater com o
  spec ao pé da letra): descartado — preferimos uma opção honesta e
  funcional (BLE) a uma opção que nunca faria nada.
- Dar ao app desktop um botão "Salvar"/"Restaurar" que efetivamente
  passasse a exigir confirmação pra persistir `set_pad`/`set_global` (pra
  unificar o modelo de persistência entre os dois caminhos): descartado —
  mudaria a UX já validada do app (auto-save) sem pedido do usuário, só
  por simetria com a tela física.

## 2026-08-21 — Fase K: multiplexação trocada de 4x CD4051 para 2x CD4067 (HW-178)

**Decisão**: substituir os 4x chip CD4051 avulso (8 canais cada) por 2x
módulos breakout "HW-178" (chip CD4067, 16 canais cada) — mesmas 32 entradas
analógicas totais, só com metade das placas físicas pra montar/cabear.

**Contexto/Racional**: o usuário encontrou/comprou 2 unidades do HW-178 por
um preço melhor do que montar 4x CD4051 soltos (sem contar que o breakout já
vem com os resistores/capacitores de desacoplamento prontos, reduzindo
solda). A biblioteca já suporta `HelloDrumMUX_4067` nativamente (mesma
classe já mencionada desde a entrada de 2026-08-20 sobre multiplexação, só
não tínhamos usado ainda) — troca de chip, não uma modificação de código
sob medida.

**Por que isso não afeta o resto do firmware**: a indexação de pads
(`HelloDrum pads[32]`, `padTypes[]`, EEPROM, protocolo serial, telas) sempre
tratou os 32 canais como um espaço linear único (`i` de 0 a 31) — nunca
soube ou precisou saber quantos chips físicos formam esse espaço. Só a
camada de `HelloDrumMUX_*`/`scan()` muda: em vez de 4 instâncias de
`HelloDrumMUX_4051` (`muxNum*8 + canal_local`, 3 pinos de seleção), agora são
2 instâncias de `HelloDrumMUX_4067` (`muxNum*16 + canal_local`, 4 pinos de
seleção S0-S3) — confirmado lendo `HelloDrumMUX_4067::scan()` em
`hellodrum.cpp`, que usa exatamente esse padrão. `NUM_PADS` continua 32,
`rawValue[64]` (branch ESP32 da lib) segue com folga de sobra.

**Pinout**: `MUX_S0/S1/S2` continuam nos mesmos GPIOs (4/5/6, compartilhados
entre as 2 placas); adicionado `MUX_S3` no GPIO7 — reaproveitando o pino que
antes era o `Z` do 3º CD4051 (que deixou de existir), evitando precisar
caçar um GPIO novo fora das faixas já vetadas (strapping/USB/PSRAM). O GPIO8
(antigo `Z` do 4º CD4051) ficou livre, sem uso previsto por ora. Os 2 pinos
`SIG` (saída analógica de cada HW-178) usam os mesmos GPIOs 1 e 2 que já
eram usados pros 2 primeiros MUX. Detalhes em
[02-hardware.md](02-hardware.md).

**Pino EN do HW-178**: o breakout expõe um pino `EN` (enable, ativo em LOW)
que a lib não controla (o construtor de `HelloDrumMUX_4067` só recebe
S0-S3+SIG, sem EN) — decisão de wiring, não de firmware: ligar `EN` direto
em GND em cada uma das 2 placas, deixando-as sempre habilitadas. Não há
necessidade de desabilitar um MUX (como faria sentido se os dois
compartilhassem um único pino `SIG`), já que cada placa tem seu próprio
pino ADC dedicado.

**Esquemático atualizado**: `docs/assets/esquematico-hellodrum.html`
redesenhado para mostrar 2 blocos HW-178 (com S0-S3 + SIG + EN→GND) em vez
de 4 blocos CD4051 (S0-S2 + Z).

**Status de validação**: firmware compila e linka com sucesso via
PlatformIO (`pio run`). **Nada testado em hardware real** — em especial,
não há confirmação de que o pino `EN` do HW-178 realmente fica sempre
habilitado ligado direto em GND (é o comportamento esperado do datasheet do
CD4067, mas o breakout específico pode ter alguma diferença de fiação não
documentada pelo vendedor).

**Alternativas descartadas**:
- Manter 4x CD4051: descartado por custo/praticidade de montagem — o
  usuário já comprou os 2x HW-178, sem motivo técnico para não usá-los.
- Misturar CD4051 e CD4067 (ex: 2 de cada, pra reaproveitar chips CD4051
  avulsos que sobraram): descartado por complexidade desnecessária — os 2x
  HW-178 já cobrem os 32 canais sozinhos, e misturar exigiria calcular
  offsets manualmente (`muxIndex` é compartilhado entre as duas classes,
  não reinicia por tipo).

## 2026-08-21 — Fase L: pinout reorganizado por ergonomia de montagem (header esquerdo/direito)

**Decisão**: reatribuir os GPIOs dos 2x CD4067, da tela TFT e dos 2
encoders de forma que cada subsistema saia **inteiro de um único header
físico** da placa (esquerdo ou direito) — nenhum sinal de um mesmo módulo
fica dividido entre os dois lados. Header esquerdo = 2x CD4067 + tela TFT.
Header direito = os 2 encoders.

**Contexto/Racional**: o usuário enviou uma foto do pinout real da placa
comprada (dev board ESP32-S3, headers de 22 pinos de cada lado do módulo
WROOM) e pediu que a fiação de cada subsistema saia sempre do mesmo lado,
por ergonomia de montagem — até a Fase K, o pinout tinha sido escolhido "no
papel" (evitando conflitos conhecidos: strapping, USB nativo, PSRAM octal)
sem nenhuma noção de **qual pino sai de qual lado físico da placa real**,
então o barramento dos MUX (S0-S3 num lado, SIG0/SIG1 no outro) e o encoder
2 (A num lado, B/SW no outro) ficavam split entre os dois headers —
exatamente o problema que o usuário queria resolver.

**Dois fatos do pinout real guiaram a divisão** (não foi uma escolha
arbitrária 50/50):
- **`3V3` só existe no header esquerdo** (2 pinos, topo da placa). O header
  direito só expõe `GND`. Como os 2x CD4067 e a tela TFT precisam de VCC,
  eles **têm** que sair do header esquerdo — colocá-los no direito exigiria
  cruzar um fio de 3.3V pela placa de qualquer jeito, o que anularia o
  ganho de ergonomia.
- Os 2 encoders usam só pull-up interno do ESP32-S3 (`INPUT_PULLUP`, sem
  resistor/VCC externo — decisão já registrada na entrada de 2026-08-20
  sobre navegação por encoders) — só precisam de `GND` comum, presente nos
  dois headers. Por isso podem ficar inteiramente no header direito sem
  custo elétrico nenhum.

Ou seja, a divisão "sensing+display de um lado, controles do usuário do
outro" não foi só estética — é a que exige o menor número de fios cruzando
a placa (zero, no caso ideal), porque cada grupo já compartilha a mesma
necessidade (ou não) de alimentação externa.

**Pinos alterados** (`firmware/src/main.cpp`):
- `MUX0_Z`/`MUX1_Z` (SIG dos 2 CD4067): GPIO1/GPIO2 → **GPIO8/GPIO9**
  (ambos ADC1, header esquerdo, ao lado de `MUX_S0-S3` que já estavam lá).
- `TFT_DC`: GPIO9 → **GPIO10** (GPIO9 passou a ser o `SIG` do MUX 1).
- `TFT_CS`: GPIO10 → **GPIO16** (GPIO10 passou a ser o `DC` da tela).
  `TFT_SCLK`/`TFT_MOSI`/`TFT_BLK`/`TFT_RST` não mudaram.
- `ENC1_A/B/SW`: GPIO15/16/17 → **GPIO42/41/40**.
- `ENC2_A/B/SW`: GPIO18/21/38 → **GPIO37/36/35**.

**Achado incidental — GPIO38 aciona um LED embutido nessa placa**: a foto
do pinout real (analisada nesta fase) rotulava GPIO38 como `RGB_LED` além
de `FSPIWP`/`SUBSPIWP`. Esse pino era usado desde a Fase C para o SW do
encoder 2 ("reservada", sem função). Não temos como confirmar sem hardware
se isso já estava causando algum comportamento estranho (ex: o LED
piscando ao girar o encoder, ou o encoder não respondendo por o pino já
estar "ocupado" por outra função da placa), mas de qualquer forma é um
pino a evitar — corrigido nessa mesma passada, mesmo sendo uma correção
independente do pedido original de ergonomia.

**Correção (2026-08-31)**: Rodrigo conferiu o pinout direto na serigrafia
da placa física e o rótulo correto de GPIO38 é `BUILTIN LED` (um LED
simples embutido), não `RGB_LED` — a leitura da foto acima estava errada
nesse ponto específico. O LED RGB endereçável de fato fica no **GPIO48**
(rótulo `RGB LED`), pino que já era excluído do pinout por outro motivo
(`SPICLK_N`, sinal interno de flash/PSRAM — ver risco anotado abaixo para
GPIO35-37/47-48). Isso não muda nenhuma atribuição de pino do firmware:
GPIO38 continua evitado (agora pela razão certa) e GPIO48 continua
excluído (pela razão original, reforçada). Atualizado também em
[02-hardware.md](02-hardware.md), `docs/CHANGELOG.md`,
`docs/assets/esquematico-hellodrum.html` e o comentário em
`firmware/src/main.cpp`.

**Risco não confirmado — GPIO35/36/37 e PSRAM octal (histórico)**: esses
pinos são internos (ligados ao chip de PSRAM) em módulos ESP32-S3 que usam
PSRAM **octal** (ex: variantes "R8" tipo N16R8) — usá-los como GPIO externo
nesses módulos trava a placa. A foto do pinout real expõe os 3 como header
normal, o que sugere que o módulo específico dessa placa **não** é a
variante octal (só teria sentido expor esses pinos se eles não estivessem
ocupados internamente) — mas isso não foi confirmado contra o datasheet/
serigrafia exata do módulo. **Superado pelo ajuste de contiguidade abaixo**:
os encoders não usam mais GPIO35-37, então esse risco deixou de valer pro
pinout atual — mantido aqui só como histórico da Fase L.

**Confirmado (2026-08-31) — é octal, o risco era real**: Rodrigo leu
direto na serigrafia do módulo: `ESP32-S3-N16R8` (16MB flash + 8MB PSRAM
**octal**). Correção de um erro deste assistente na mesma data: uma
mensagem anterior afirmou (errado) que rodar `pio run` tinha "confirmado"
a variante como quad/sem PSRAM — isso é falso, o `pio run` só compila
contra o perfil genérico fixo `board = esp32-s3-devkitc-1` do
`platformio.ini` (8MB, sem PSRAM), sem ler hardware nenhum. Com o módulo
real sendo N16R8, GPIO33-37 **são de fato internos** (barramento de dados
da PSRAM octal) e não devem ser usados como GPIO externo — mas como o
ajuste de contiguidade acima já tirou os encoders desses pinos, não há
nenhuma fiação afetada.

**Corrigido (2026-08-31)**: `firmware/platformio.ini` ajustado pra
refletir o módulo real — `board_build.arduino.memory_type = qio_opi`,
`board_build.partitions = default_16MB.csv`, `board_upload.flash_size =
16MB`/`maximum_size = 16777216` e `build_flags += -D BOARD_HAS_PSRAM`
(sem essa flag o core arduino-esp32 não inicializa a PSRAM externa).
Baseado no board de referência da 4D Systems pra essa mesma combinação
(`framework-arduinoespressif32/boards/4d_systems_esp32s3_gen4_r8n16.json`),
sem trocar o `board` base (continua `esp32-s3-devkitc-1`, cujo
`flash_mode: qio` já era compatível). `pio run` limpo confirma: `HARDWARE:
... 16MB Flash` e partição de app de 6.25MB (era 3.2MB com o perfil
N8/8MB) — `[SUCCESS]`.

**Ajuste de contiguidade física (2026-08-31)**: o pinout de encoders acima
(`ENC1_A/B/SW` = GPIO42/41/40, `ENC2_A/B/SW` = GPIO37/36/35) tinha um vão de
2 pinos (`GPIO39`, `GPIO38`) entre os dois encoders na ordem física real do
header direito (`...44,1,2,42,41,40,39,38,37,36,35,0...`) — o `GPIO38` era
evitado (LED embutido), mas o `GPIO39` ficava pulado sem necessidade,
quebrando a regra de "feixe único contíguo" que já valia pro MUX+tela no
header esquerdo. Reatribuído para usar os 6 pinos realmente contíguos e
livres de qualquer pino evitado: `GPIO1, 2, 42, 41, 40, 39`.
- `ENC1_A/B/SW`: GPIO42/41/40 → **GPIO1/2/42**.
- `ENC2_A/B/SW`: GPIO37/36/35 → **GPIO41/40/39**.

Efeito colateral positivo: o novo intervalo não inclui mais GPIO35-37, então
o risco de PSRAM octal acima deixa de se aplicar a este projeto (nenhum pino
usado depende mais de o módulo ser quad em vez de octal). Também evita
GPIO43/44 (TXD0/RXD0, usados pela porta UART/USB-serial de debug — não
foram usados aqui de propósito, pra não perder o `Serial.print()` de
depuração). Atualizado em [02-hardware.md](02-hardware.md),
`docs/CHANGELOG.md`, `docs/assets/esquematico-hellodrum.html` e
`firmware/src/main.cpp`.

**Status de validação**: firmware compila e linka com sucesso via
PlatformIO (`pio run`). **Nada testado em hardware real** — em especial, a
leitura correta dos encoders nos pinos atuais (GPIO1/2 são ADC1/Touch;
GPIO39-42 são os pinos JTAG MTCK/MTDO/MTDI/MTMS — usáveis como GPIO comum
quando JTAG não está em uso, mas sem histórico de uso anterior neste
projeto) ainda precisa de confirmação física.

**Alternativas descartadas**:
- Manter os encoders divididos entre os dois headers (como estava):
  descartado — é exatamente o problema que o usuário pediu pra resolver.
- Levar um fio de 3.3V até o header direito pra poder colocar o MUX/tela
  lá também: descartado — reintroduziria o mesmo problema de fiação
  cruzando a placa que a reorganização busca eliminar, só que ao contrário.
- Espalhar os 2 encoders entre os dois headers de novo, mas agrupados por
  "papel" (ex: os dois sinais de quadratura de ambos os encoders num lado,
  as duas chaves no outro): descartado — quebraria a regra "cada
  subsistema sai de um único lado" na direção oposta (um subsistema, o
  encoder, ficaria dividido; melhor manter cada encoder inteiro num único
  header, mesmo que os dois encoders entre si fiquem no mesmo header).

**Ajuste de espelhamento da tela com o conector dela (2026-08-31)**:
pedido do Rodrigo — em vez de só "sair do mesmo header, pinos
adjacentes", a tela passa a usar os 6 pinos da **base** do header
esquerdo (`GPIO9,10,11,12,13,14`, logo acima do `5V`/`GND`) em vez de
continuar a sequência logo após o MUX (`17,18,8,9,10,11`). Motivo: o
conector físico da tela segue a ordem `GND VCC SCL SDA RES DC CS BLK`, e
nessa placa o `GND` do header esquerdo é o **último pino da base** (o
`3V3` fica no topo) — subindo a partir do `GND` da base (pulando só o
`5V`, fixo, não é GPIO), os 6 sinais da tela saem na mesma ordem do
conector dela: `SCL`(14, mais perto do `GND`) → `SDA`(13) → `RES`(12) →
`DC`(11) → `CS`(10) → `BLK`(9). Resultado: a fiação da tela sai reta,
pino a pino, sem cruzar — só o `VCC` foge dessa sequência (precisa de um
fio isolado até o `3V3` no topo), aceito de propósito como única exceção.
- `TFT_DC`: GPIO17 → **GPIO11**.
- `TFT_CS`: GPIO18 → **GPIO10**.
- `TFT_MOSI`: GPIO8 → **GPIO13**.
- `TFT_SCLK`: GPIO9 → **GPIO14**.
- `TFT_BLK`: GPIO10 → **GPIO9**.
- `TFT_RST`: GPIO11 → **GPIO12**.

**Trade-off aceito**: a tela deixa de formar um feixe único contíguo com
o MUX (que continua em `GPIO4,5,6,7,15,16`, perto do topo) — sobram
`GPIO17`, `GPIO18`, `GPIO8` livres entre os dois grupos. Priorizado de
propósito: bater com o conector da tela facilita a montagem mais do que
os dois subsistemas seguirem em feixe único (a tela e o MUX já saem por
fios/conectores separados de qualquer forma, só compartilham o mesmo
header). GPIO12/13/14 (antes "livres/sobressalentes") passam a ser usados
pela tela; nenhum pino evitado (strapping, USB, LED, flash/PSRAM) entra
nessa faixa. `pio run` confirma `[SUCCESS]` com o novo pinout. Atualizado
em [02-hardware.md](02-hardware.md), `docs/CHANGELOG.md`,
`docs/assets/esquematico-hellodrum.html` e `firmware/src/main.cpp`.

**Primeiro teste em hardware real (2026-08-31) — tela em branco, causa
raiz encontrada**: após gravar o firmware pela primeira vez (via
`firmware/platformio.ini`, porta `COM5`/CH343 — ver notas de porta
USB/UART abaixo), a tela ficou acesa (backlight ok) mas totalmente em
branco, sem nenhum conteúdo desenhado. Hipóteses investigadas em ordem:
1. Variante de driver errada (`INITR_144GREENTAB` vs `INITR_BLACKTAB`) —
   testado trocando pra `INITR_BLACKTAB`: **mesmo resultado** (branco).
   Duas variantes diferentes dando o mesmo branco descarta essa hipótese
   (se a SPI estivesse chegando no controlador, variantes diferentes
   produziriam pelo menos alguma diferença visual).
2. Interferência do resto do firmware (2900+ linhas: MUX, encoders,
   USB-MIDI, BLE, EEPROM) — testado com um ambiente PlatformIO isolado só
   pra tela (`[env:display_test]` em `platformio.ini`, código em
   `firmware/src/test_display.cpp`, ver comentário no arquivo), sem
   nenhum outro subsistema. **Mesmo resultado** (branco) — descarta
   interferência de software.
3. **Causa raiz**: curto físico na solda de um dos pinos da tela,
   encontrado e corrigido por Rodrigo. Depois da correção, o teste
   isolado (`display_test`) mostrou as cores ciclando corretamente.

Reversão: `tft.initR()` voltado pra `INITR_144GREENTAB` (a variante
correta pra esse tamanho de tela, 1.44"/128×128 — o teste com
`INITR_BLACKTAB` foi feito sob a conexão com curto, portanto inválido e
descartado). Firmware principal regravado com sucesso.

**Ambiente de teste permanente**: `[env:display_test]` fica no
`platformio.ini` como ferramenta de diagnóstico reutilizável (não
depende do `main.cpp`, resolve rápido se um problema futuro é hardware
ou software) — `pio run -e display_test -t upload --upload-port COM5`.
**Cuidado**: rodar `pio run` sem `-e <nome>` processa **todos** os
environments do `.ini` em sequência — se `--upload-port` for passado
assim, cada um sobrescreve o anterior na placa (foi o que aconteceu numa
tentativa aqui: o `display_test` acabou sobrescrevendo o firmware
principal recém-gravado). Sempre usar `-e esp32-s3-devkitc-1` pra
gravar o firmware de verdade.

**Portas COM identificadas nesta placa**: a porta rotulada fisicamente
**"UART"** aparece no Windows como `CH343` (ex: `COM5`) — usa GPIO43/44
(TXD0/RXD0), auto-reset funciona sozinho via RTS, **recomendada pra
gravação**. A porta rotulada **"USB"** é o USB nativo do ESP32-S3 — no
modo bootloader aparece como `USB-Serial/JTAG` (era `COM4` aqui), e uma
vez o firmware rodando (`ARDUINO_USB_MODE=0`+`ARDUINO_USB_CDC_ON_BOOT=1`)
essa mesma porta física passa a carregar tanto `Serial` (console CDC)
quanto a classe MIDI customizada (TinyUSB) — não serve bem pra gravar
(exige BOOT+RESET manual, o app já ocupa a porta).

**Refinamento (mesmo dia)**: "mesmo header" não é o mesmo que "pinos
adjacentes" — a Fase L original já tirava cada subsistema de um único
lado, mas dentro desse lado os pinos ainda podiam estar espalhados (ex:
SIG0/SIG1 em GPIO8/9, física e visualmente distantes de S0-S3 em GPIO4-7
na sequência real da placa, mesmo estando no mesmo header). Reexaminando a
ordem física exata do header esquerdo
(`4,5,6,7,15,16,17,18,8,3,46,9,10,11,12,13,14`), veio o pedido explícito do
usuário pra usar `4,5,6,7,15,16` no MUX — os únicos 6 pinos que formam uma
sequência **contígua** (sem nenhum outro sinal usável entre eles) — e
aplicar o mesmo critério aos demais componentes.

- **MUX (S0-S3, SIG0/SIG1)**: `4,5,6,7,15,16` — sequência contígua na
  ordem física real. **Trade-off aceito**: GPIO15/16 são ADC2, não ADC1
  (as fases anteriores preferiam ADC1 por precaução com o conflito
  clássico ADC2×Wi-Fi). Esse conflito é especificamente com o driver
  Wi-Fi (arbitragem de RF) — este projeto **nunca inicializa Wi-Fi** (só
  BLE-MIDI, que usa outro caminho de rádio e não disputa o ADC2) — então a
  restrição "só ADC1" foi relaxada aqui deliberadamente. Se o projeto um
  dia ganhar Wi-Fi, isso precisa ser reavaliado.
- **TFT (DC, CS, MOSI, SCLK, BLK, RST)**: `17,18,8,9,10,11` — continua a
  mesma sequência física logo depois do MUX, sem pular nada além dos
  pinos de strapping (`3`/`46`, que já eram inevitáveis). `DC`/`CS` ficam
  juntos em `17,18` e `MOSI`/`SCLK` juntos em `8,9` — nenhum desses sinais
  depende de um pino físico específico do chip (SPI é roteado por matriz
  de GPIO no ESP32-S3), então a ordem interna é livre.
- **Encoders**: sem mudança — `42,41,40` e `37,36,35` já eram sequências
  contíguas desde a Fase L original (só coincidência de já estarem bem
  posicionados).

Pinos sobressalentes remanescentes: `12,13,14` (header esquerdo, imediatamente
depois da sequência MUX+TFT) e `1,2,21,39,43,44` (header direito).

**Alternativa descartada**: manter SIG0/SIG1 em GPIO8/9 (ADC1) e aceitar
que ficassem "no mesmo header, mas não adjacentes" — descartado porque o
usuário pediu explicitamente contiguidade física, não só "mesmo lado", e
o motivo original para preferir ADC1 (conflito com Wi-Fi) não se aplica a
este projeto.

## 2026-08-22 — Fase M: tipo de sensor "Caixa 3 zonas" (centro/borda/aro) + bugfix do `PAD_DUAL`

**Decisão**: adicionar `PAD_SNARE_3ZONE` (tipo 8) — uma caixa com 3 sons
(centro da pele, borda da pele, aro/rimshot) — reusando **sem nenhuma
mudança** a mesma sensing já usada pro prato 3 zonas
(`cymbal3zoneMUX()`/`cymbal3zoneSensing()` em `hellodrum.cpp`), só com
zonas/rótulos renomeados pro contexto de caixa.

**Contexto/Racional**: o usuário perguntou como o código trataria uma
caixa real (que tipicamente tem 3 sons: centro da pele, perto da borda da
pele, e o aro) e pediu pra pesquisar como a lib já trata isso. Investigando
`hellodrum.cpp`, achamos que a técnica do prato 3 zonas (tipo 5) já é
exatamente a resposta: 2 piezos (corpo + borda/switch), e o segundo piezo é
comparado contra **2 thresholds em sequência** (`edgeThreshold`,
`cupThreshold`) em vez de um só — isso já separa "vibrou pouco" de "vibrou
muito" no mesmo sensor. É o mesmo princípio físico usado em pads de caixa
reais com 3 sons: eles também não têm 3 sensores — têm 2 (pele + aro), e
distinguem "borda da pele" (vibração leve no sensor do aro) de "aro de
verdade" (vibração forte no mesmo sensor do aro) por amplitude, não por um
terceiro sensor dedicado.

**Implementação**: `PAD_SNARE_3ZONE = 8` despacha pra
`cymbal3zoneMUX()` (dispatchSensing), cabeamento **idêntico** ao
`PAD_DUAL` (pele = `pin_1`, aro = `pin_2` — trocar entre os dois tipos não
exige recabear nada). Campos de configuração reaproveitados: `EDGETHR`/
`RIMTHR` (rim_sensitivity/rim_threshold) e `N.EDGE`/`N.RIM`
(note_rim/note_cup internamente `noteEdge`/`noteCup`). Zonas no protocolo:
`"head"` (centro), `"edge"` (borda), `"rim"` (aro de verdade) — ver
[05-tipos-de-sensor.md](05-tipos-de-sensor.md) pra tabela completa e
[04-protocolo-serial.md](04-protocolo-serial.md) pro contrato de zonas.
Decisões de nomenclatura (tipo novo dedicado, não reaproveitar "Prato 3
zonas" com rótulo genérico; zonas `head`/`edge`/`rim`) confirmadas
diretamente com o usuário via pergunta.

**Bug encontrado e corrigido no caminho — `PAD_DUAL` nunca enviava
hit/nota**: enquanto rastreava onde adicionar o despacho de zona pro tipo
8, percebemos que `handlePadResult()` (a função que decide qual evento
`hit`/nota MIDI enviar por tipo de pad) **nunca teve um `case PAD_DUAL:`**
desde a Fase G — o switch tinha `PAD_SINGLE`, `PAD_HIHAT_SINGLE`,
`PAD_CYMBAL_2ZONE`/`PAD_HIHAT_2ZONE`, `PAD_CYMBAL_3ZONE` e
`PAD_HIHAT_PEDAL`/`PAD_HIHAT_OPTICAL`, mas não `PAD_DUAL` — e sem `default:`
nenhum. Na prática, isso significa que **qualquer pad configurado como
tipo 1 (Aro/Dual) nunca emitiu nota MIDI nenhuma, nem por USB nem por BLE**,
apesar de `dispatchSensing()` continuar chamando `dualPiezoMUX()`
normalmente (a detecção de hit acontecia, só o despacho pra MIDI/protocolo
é que faltava). Confirmamos que isso não era intencional porque tanto
[04-protocolo-serial.md](04-protocolo-serial.md) (zona `hit`) quanto
`mockDevice.ts` (modo demo do app desktop) já documentavam/simulavam as
zonas `"head"`/`"rim"` pra esse tipo desde a Fase G — só a implementação
real no firmware que nunca foi escrita. Corrigido adicionando o `case`
faltante, usando exatamente essas zonas já documentadas.

**Por que isso é especialmente relevante agora**: tipo 1 (Aro/Dual) é o
tipo mais comum pra caixa/tom com aro — bem provável que seja o tipo já
configurado pro pad de caixa do usuário. Sem essa correção, uma caixa
"normal" (2 zonas, sem o refinamento do tipo 8) simplesmente não tocaria
nada.

**Status de validação**: firmware compila e linka com sucesso (`pio run`);
app desktop com `npm run typecheck`/`npm run build` limpos, incluindo o
modo demo atualizado (`mockDevice.ts` simula as 3 zonas do tipo 8) e o
simulador de hardware (`HardwareSimulator.tsx`, pad de exemplo "Caixa"
trocado de tipo 0 pra tipo 8 pra já mostrar a feature). **Nada testado em
hardware real** — em especial, os thresholds de borda/aro do tipo 8 nunca
foram calibrados numa caixa física de verdade (o valor certo depende muito
de onde o piezo do aro é colado e de que aro é esse).

**Alternativas descartadas**:
- Reaproveitar "Prato 3 zonas" (tipo 5) como está, sem tipo novo: o
  usuário preferiu um tipo dedicado com rótulos próprios (Centro/Borda/
  Aro) pra não confundir na tela/app com terminologia de prato.
- Zonas `center`/`edge`/`rim` em vez de `head`/`edge`/`rim`: o usuário
  preferiu `head` por já ser o termo usado no protocolo pro tipo 1
  (Aro/Dual), mantendo consistência entre os dois tipos que compartilham
  o mesmo cabeamento físico.
- Implementar sensoreamento de posição de verdade (centro vs. borda
  detectado por timing/frequência entre 2 piezos, como pads profissionais
  caros fazem): descartado — exigiria modificar a lib vendorizada com DSP
  que ela não tem, fora de escopo pra um piezo simples + scan de
  amplitude.
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

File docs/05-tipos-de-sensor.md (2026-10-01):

# Tipos de sensor por pad (Fase G)

Baseado em [`docs/sensing.md`](https://github.com/RyoKosaka/HelloDrum-arduino-Library/blob/master/docs/sensing.md)
da lib base (cópia local em
`firmware/lib/HelloDrum-arduino-Library/docs/sensing.md`) e na leitura direta
do código-fonte (`hellodrum.cpp`) pra confirmar o que a documentação não deixa
100% explícito.

## Cada tipo usa no máximo 2 canais — nunca 3

O construtor de `HelloDrum` só aceita 1 ou 2 pinos (`HelloDrum(pin1)` ou
`HelloDrum(pin1, pin2)`) — é uma limitação estrutural da lib, não uma escolha
nossa. Isso vale até pro **prato de 3 zonas**: a 3ª zona (cup) não é um canal
separado — é o **mesmo** sinal analógico do switch de filme do prato (o mesmo
usado pra detectar a borda/edge), só que passado por um divisor de tensão no
prato (ex: Yamaha PCY135/155). A lib distingue "borda" de "cup" comparando
esse único valor contra dois limiares diferentes (`Edge Threshold` e
`Cup Threshold`, sendo o do cup mais alto). Confirmado lendo
`cymbal3zoneMUX()`/`cymbal3zoneSensing()` em `hellodrum.cpp` — só lê
`pin_1` (piezo do corpo) e `pin_2` (o switch).

## Os 10 tipos

| # | Tipo | Canais | Método da lib | Zonas/estados |
|---|---|---|---|---|
| 0 | Simples | 1 | `singlePiezoMUX()` | 1 (bow) |
| 1 | Aro / Dual | 2 | `dualPiezoMUX()` | head + rim |
| 2 | Chimbal simples *(oculto)* | 1 | `HHMUX()` | 1 zona, nota varia com aberto/fechado |
| 3 | Prato 2 zonas | 2 | `cymbal2zoneMUX()` | bow + edge |
| 4 | Chimbal 2 zonas *(oculto)* | 2 | `HH2zoneMUX()` | bow + edge, nota varia com aberto/fechado |
| 5 | Prato 3 zonas | 2 | `cymbal3zoneMUX()` | bow + edge + cup (mesmo canal do edge, por threshold) |
| 6 | Pedal de chimbal (FSR/VH-10/VH-11) | 1 | `hihatControlMUX()` | posição (CC) + "chick" ao fechar rápido |
| 7 | Pedal de chimbal óptico (TCRT5000) | 1 | `TCRT5000MUX()` | igual ao 6, sensor diferente |
| 8 | Caixa 3 zonas | 2 | `snare3zoneMUX()` | centro (head) + borda (edge) + aro (rim), por razões entre os 2 piezos |
| 9 | Choke (fita de contato) | 1 | `dispatchChoke()` (própria, fora da lib) | 1 zona (`"touch"`), gatilho binário, velocity sempre 127 |

### Tipo 9 — Choke (fita de contato)

Pedido do usuário: uma fita de alumínio ligada direto num pino analógico do
ESP32 (sem piezo, sem circuito de vibração) — quando o baterista encosta a
mão (ex: pra abafar um prato), o contato faz o `rawValue[]` desse canal
saltar pra perto do topo da escala do ADC. É um **gatilho binário**, não um
sensor de impacto: não faz sentido medir "quão forte" foi o toque, então a
nota sempre sai com `velocity = 127`.

Por isso esse tipo **não usa nenhum método da lib vendorizada**
(`dispatchChoke()`, implementado direto em `main.cpp`) e não reaproveita o
pipeline de envelope/threshold dos outros 9 tipos — só compara `rawValue[i]`
contra um threshold (campo `threshold`, reaproveitado como % do fundo de
escala do ADC) com uma pequena histerese (~10%) pra soltar, evitando repetir
a nota por ruído bem em cima do limiar enquanto a fita continua encostada. A
nota só dispara na borda de subida (não tocado → tocado); segurar o contato
não repete, soltar e encostar de novo dispara de novo.

Consequência prática: **muito menos campos de configuração** que os outros
tipos — só `threshold` (nível de contato) e `note` (nota MIDI a disparar).
Sem `sensitivity`/`scan_time`/`mask_time`/`retrigger`/`gain`/`curve_type`
(não existe envelope pra moldar) nem `xtalk`/`xtalk_group` (não é vibração
mecânica correlacionada entre pads). O assistente de auto-calibração
também não se aplica (foi pensado pra medir pico/ruído de impacto) — tanto
o firmware quanto o modo demo recusam `start_autotune` pra esse tipo com
`error: "not_applicable_for_choke"`.

O evento `hit` desse tipo usa a zona `"touch"` (não `"choke"` — esse nome já
é usado pelo gesto de abafar um prato/caixa detectado via envelope de
vibração nos tipos 3/5/8, um mecanismo completamente diferente; ver
[04-protocolo-serial.md](04-protocolo-serial.md)).
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

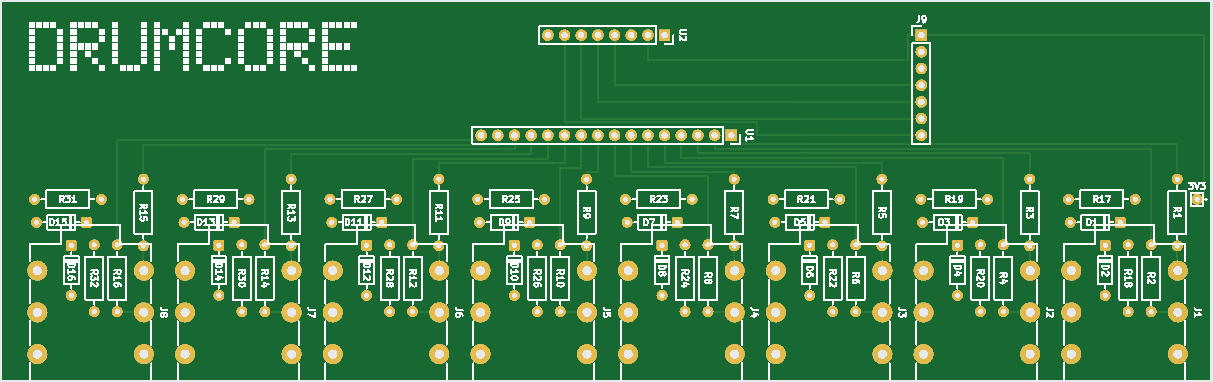
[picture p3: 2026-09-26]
hardware/jackboard/jackboard-top.png

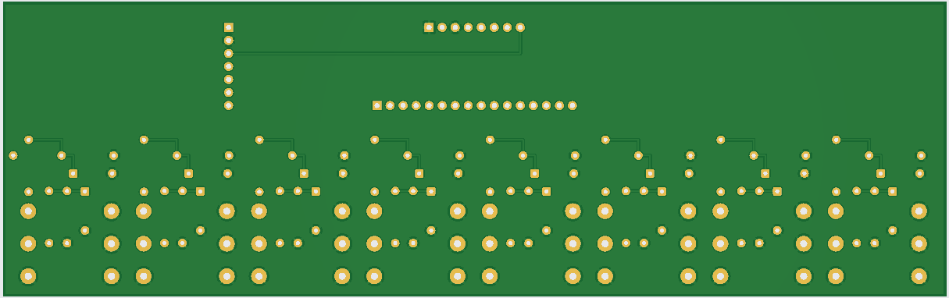
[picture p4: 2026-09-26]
hardware/jackboard/jackboard-botton.png

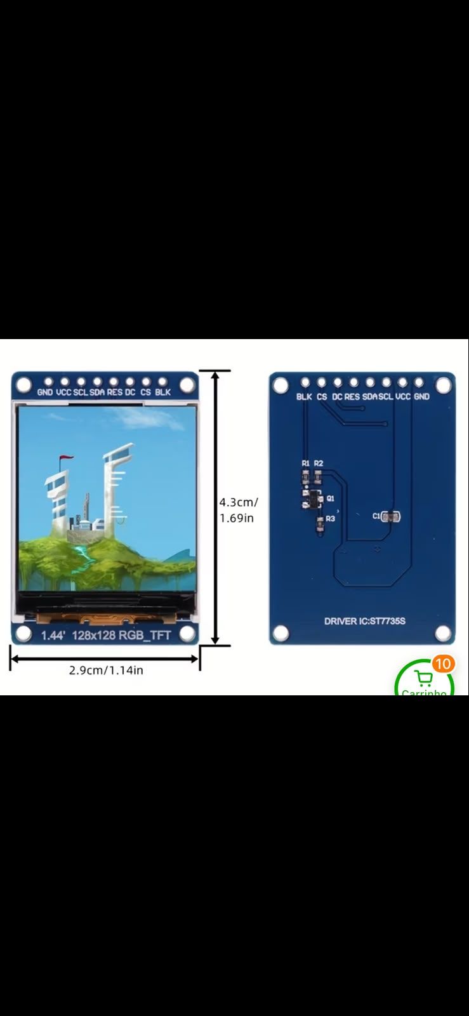
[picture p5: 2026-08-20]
Modelo Tela.jpeg

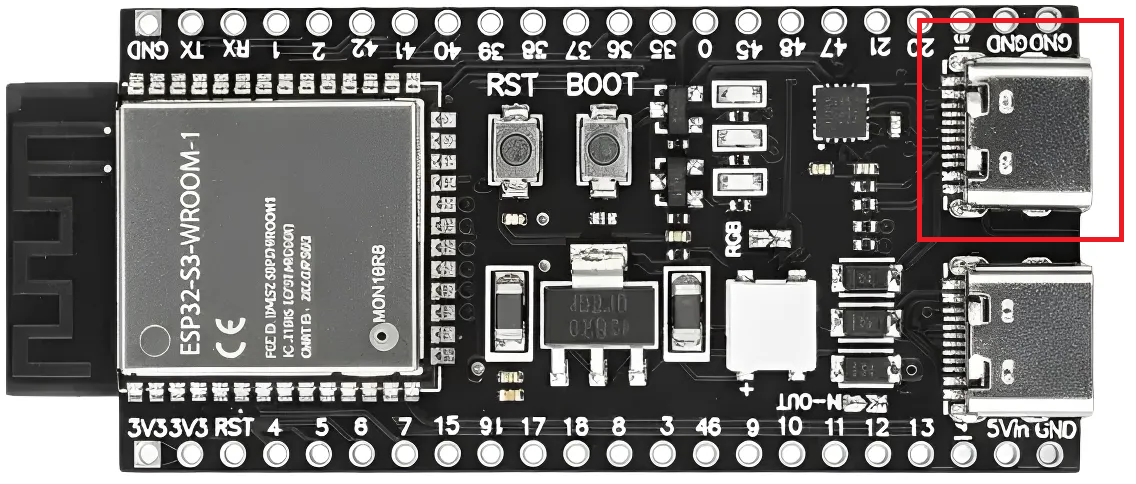
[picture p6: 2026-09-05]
web-app/src/assets/esp32-uart.png

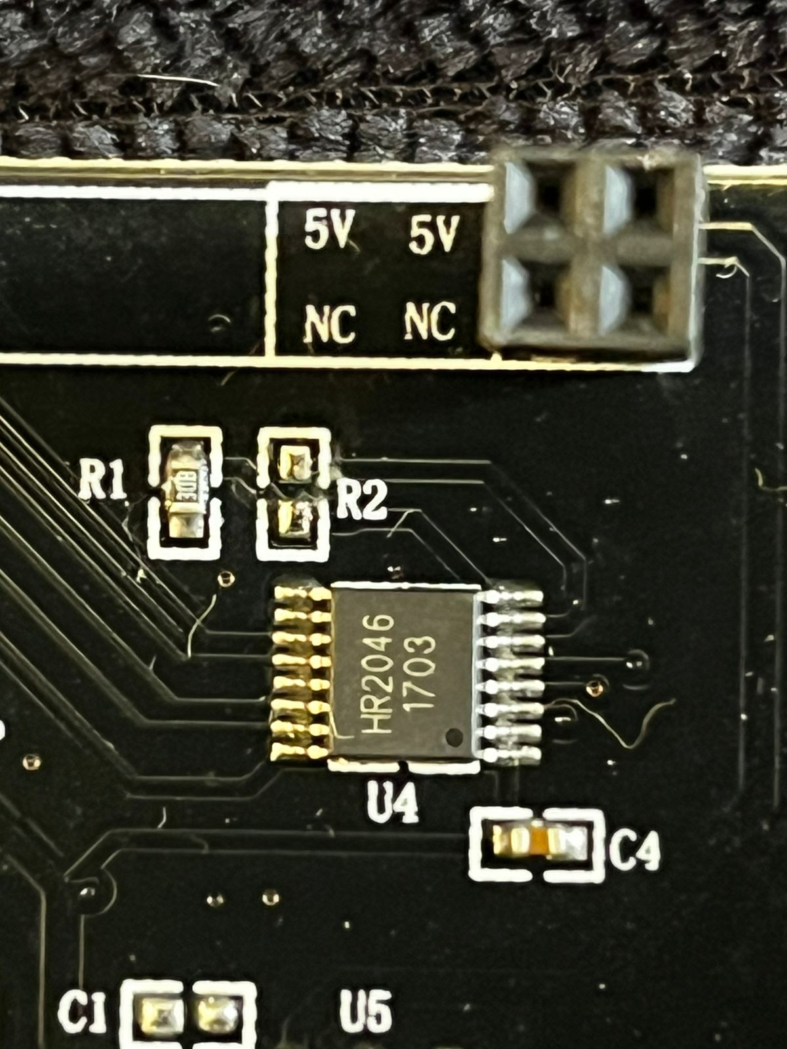
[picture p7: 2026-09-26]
tela2-2.jpeg

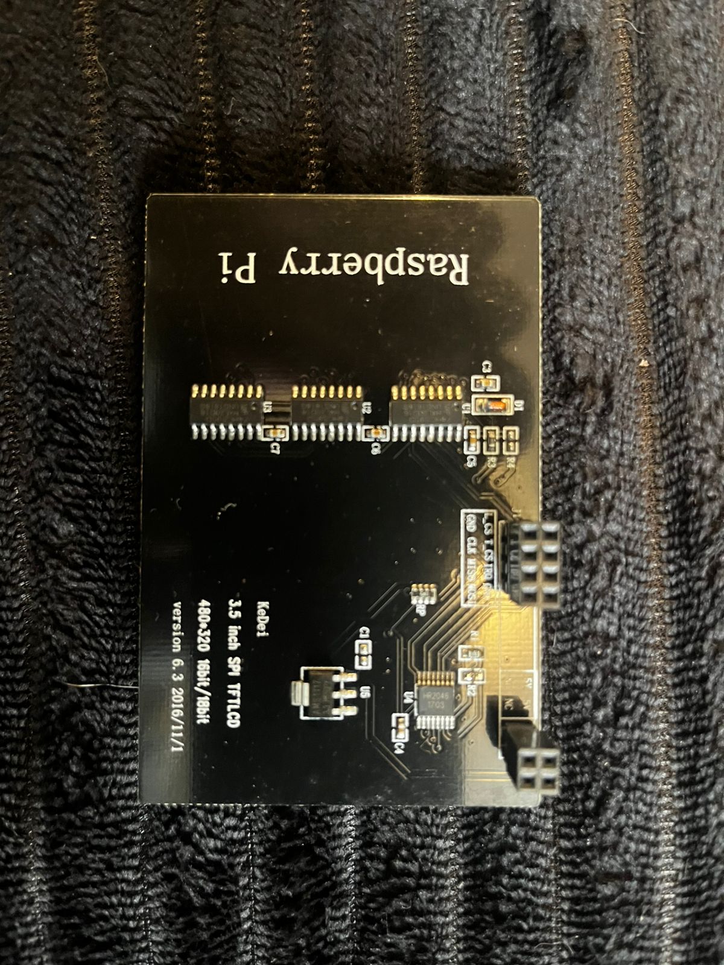
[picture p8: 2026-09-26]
tela2.jpeg

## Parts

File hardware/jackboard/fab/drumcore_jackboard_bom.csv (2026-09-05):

Reference | Value | Footprint | QUANTITY
D1-D16 | BAT85 | Diode_THT:D_DO-35_SOD27_P7.62mm_Horizontal | 16
J1 | PAD1_TRS_6.35MM | Connector_Audio:Jack_6.35mm_Neutrik_NMJ6HCD2_Horizontal | 1
J2 | PAD2_TRS_6.35MM | Connector_Audio:Jack_6.35mm_Neutrik_NMJ6HCD2_Horizontal | 1
J3 | PAD3_TRS_6.35MM | Connector_Audio:Jack_6.35mm_Neutrik_NMJ6HCD2_Horizontal | 1
J4 | PAD4_TRS_6.35MM | Connector_Audio:Jack_6.35mm_Neutrik_NMJ6HCD2_Horizontal | 1
J5 | PAD5_TRS_6.35MM | Connector_Audio:Jack_6.35mm_Neutrik_NMJ6HCD2_Horizontal | 1
J6 | PAD6_TRS_6.35MM | Connector_Audio:Jack_6.35mm_Neutrik_NMJ6HCD2_Horizontal | 1
J7 | PAD7_TRS_6.35MM | Connector_Audio:Jack_6.35mm_Neutrik_NMJ6HCD2_Horizontal | 1
J8 | PAD8_TRS_6.35MM | Connector_Audio:Jack_6.35mm_Neutrik_NMJ6HCD2_Horizontal | 1
J9 | LINK_TO_MAINBOARD | Connector_PinHeader_2.54mm:PinHeader_1x07_P2.54mm_Vertical | 1
R1-R16 | 100R | Resistor_THT:R_Axial_DIN0207_L6.3mm_D2.5mm_P10.16mm_Horizontal | 16
R17-R32 | 100K | Resistor_THT:R_Axial_DIN0207_L6.3mm_D2.5mm_P10.16mm_Horizontal | 16
U1 | HC4067_CHANNELS | Connector_PinSocket_2.54mm:PinSocket_1x16_P2.54mm_Vertical | 1
U2 | HC4067_CTRL | Connector_PinSocket_2.54mm:PinSocket_1x08_P2.54mm_Vertical | 1

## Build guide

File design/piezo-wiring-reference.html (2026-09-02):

DrumCore · referência de hardware

# Ligação do sensor piezo (teste sem MUX)

Enquanto os 2x CD4067 não chegam, dá pra testar um pad dual-zone (corpo + aro) ligando 2 piezos direto em 2 pinos do ESP32-S3 — GPIO17 e GPIO18. Essa página cobre os componentes, o esquemático e um achado importante no firmware que vale corrigir antes de testar.

## ComponentesLista de compras

- ×2 Sensor piezoelétrico (disco cerâmico, 2 fios) o mesmo tipo já usado nos outros pads
- ×2 Resistor 100 kΩ, ¼ W um por piezo — não é opcional, ver abaixo
- — Protoboard + jumpers ou solda direta nos fios do piezo

## EsquemáticoComo ligar cada piezo

O resistor de 100 kΩ fica em paralelo com os dois terminais do piezo — não em série. Ele é o que define o "repouso" do sensor: sem ele, o pino do ESP32 fica flutuando (lê ruído, dispara sozinho); com ele, o pino fica perto de 0 V quando nada bate, e sobe quando o piezo é atingido.

Cada piezo tem seu próprio resistor de 100 kΩ em paralelo entre os dois terminais — o terminal de sinal (ciano) segue pro GPIO correspondente, o de terra (cinza) junta com o do outro piezo num GND comum do ESP32-S3. Sem o resistor, o pino fica boiando e dispara sozinho — foi exatamente o sintoma visto no teste com fio solto.

## PinosReferência rápida

Sinal | Vai em | Papel
Piezo 1 — sinal | GPIO17 | corpo (zona "bow"), aparece como Pad 1
Piezo 2 — sinal | GPIO18 | aro (zona "rim"), consumido pelo Pad 1
Ambos — terra | GND | qualquer GND do header esquerdo ou direito

Já removi do firmware o pull-up interno que eu tinha ligado nesses 2 pinos pro teste com fio solto — com o resistor de 100 kΩ de verdade, ele não é necessário (e atrapalharia o repouso perto de 0 V que o resistor cria sozinho).

Achado no firmware

### A fórmula de leitura do ESP32 pode estar invertendo o sensor

Fui atrás do circuito de referência oficial da HelloDrum-arduino-Library pra desenhar o esquemático acima, e reparei em algo que vale corrigir antes de testar com um piezo de verdade:

1. O circuito oficial ("Single Piezo" e "ESP32 with MUX", ambos do próprio autor) mostra exatamente o que está desenhado acima — resistor em paralelo, repouso perto de 0 V, sinal sobe numa batida.
2. Mas hellodrum.cpp tem um trecho só pra ESP32 (piezoValue = 1023 - bruto/4) que inverte essa leitura — repouso (bruto perto de 0) vira o valor mais alto possível, e uma batida forte (bruto perto do máximo) vira o valor mais baixo. Com o circuito oficial, isso faria o pad disparar parado e ficar quieto justamente quando bate.

Ainda não testei isso com um piezo de verdade (só com fio solto, que não prova nada sobre essa fórmula) — antes de você montar o circuito acima, quer que eu corrija essa inversão no firmware, ou prefere testar primeiro do jeito que está pra confirmarmos o sintoma com dados reais?

Esquemático baseado nos diagramas oficiais "Single Piezo Circuit" e "ESP32 with MUX" de RyoKosaka/HelloDrum-arduino-Library (https://github.com/RyoKosaka/HelloDrum-arduino-Library) (open-e-drums.com).

DrumCore · módulo MIDI-USB/BLE para bateria eletrônica · ver docs/02-hardware.md

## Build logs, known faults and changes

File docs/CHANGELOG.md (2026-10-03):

# Changelog

Registro cronológico do que foi feito no projeto (mais recente no topo).

## 2026-10-03 — Site atualizado; jackboards validadas

- As **2 jackboards** (32 canais pelos 2 CD4067) estão montadas e
  validadas em hardware real.
- Site: Wi-Fi e atualização pelo Wi-Fi, caixa 3 zonas por razões, pedal de
  chimbal contínuo (SS49E), mapa do Superior Drummer 3, aviso do jack 1
  dedicado ao pedal, e status do hardware validado.
- Esquemático do site corrigido: mostrava a pinagem antiga do MUX. O
  certo, igual ao firmware: S0–S3 = GPIO39/40/41/42, SIG da jackboard A =
  GPIO2, da B = GPIO1.

## 2026-10-03 — Wi-Fi, fase 3: atualizar o firmware pela rede

- Com o ConfigTool aberto pela placa, a aba **Firmware** atualiza o
  firmware **pelo Wi-Fi**: baixa a versão mais recente do GitHub (precisa
  de internet, ou seja, rede de casa) ou usa um arquivo `.bin` escolhido.
- **Confirmação física**: o módulo pergunta na tela e só um clique no
  encoder libera o envio. Ninguém na mesma rede troca o firmware sem mexer
  no módulo.
- Testado de ponta a ponta: 1,6 MB em ~10 s na rede de casa. O módulo
  reinicia sozinho com o Wi-Fi ligado e o app reconecta. Arquivo errado e
  envio sem confirmação são recusados.
- Corrigido: a aba Firmware escolhia a versão "mais recente" comparando
  as tags como texto (`fw-v0.0.9` vinha antes de `fw-v0.0.10`).
- Comandos `ota_request`/`ota_cancel`, evento `ota_status`. A release grava
  `app_offset` no `manifest.json`.

## 2026-10-03 — Wi-Fi, fase 2: rede de casa

- O módulo pode entrar no **Wi-Fi de casa**: no ConfigTool, aba Global >
  Wi-Fi, procure a rede, digite a senha e salve. Daí em diante, ligar o
  Wi-Fi já entra nela, e o ConfigTool abre em `http://drumcore.local` na
  própria rede de casa, sem trocar de rede.
- Se a rede de casa não conectar em 15 s, o módulo para de tentar e põe a
  rede própria no ar para corrigir ("Tentar de novo" no app).
- Opção **ligar o Wi-Fi sempre que o módulo ligar** (padrão: desligado).
- A tela GLOBAL mostra o estado (`LIGADO` / `CONECT...` / `CASA` /
  `FALHOU`) e o endereço.
- Comandos novos `set_wifi_network`, `retry_wifi_network`,
  `forget_wifi_network`, `scan_wifi` (resposta `wifi_scan`); `set_wifi`
  aceita `autostart`; `device_info.wifi` com o estado da rede de casa.

## 2026-10-03 — Wi-Fi, fase 1: ConfigTool direto da placa

- O módulo cria a **própria rede Wi-Fi** (`DrumCore-XXXX`, senha de 8
  dígitos própria de cada placa), ligada em **GLOBAL > WI-FI** na tela ou
  pelo ConfigTool (aba Global). Começa desligada a cada boot.
- Com o Wi-Fi ligado, o **ConfigTool abre direto da placa** em
  `http://drumcore.local` ou `http://192.168.4.1`, em qualquer navegador,
  inclusive no celular, sem cabo. O app vem embutido no firmware e conecta
  sozinho por WebSocket, com o mesmo protocolo da serial.
- Comando novo `set_wifi`; `device_info` ganhou o objeto `wifi`.
- Medido sem aparelho conectado: o loop de leitura dos pads passa de 1,93
  para 1,98 ms em média com o Wi-Fi ligado.
- Detalhes em [08-wifi.md](08-wifi.md).

## 2026-10-03 — Mapa MIDI do Superior Drummer 3 no ConfigTool

- Novo mapa **Superior Drummer 3** (layout padrão da Toontrack, 36 = C1) no
  seletor de mapas e em "Aplicar mapa aos pads". O padrão continua sendo o
  Addictive Drums 2.
- Notas por instrumento: caixa 38 / aro 40 / borda 33; toms Racktom 1–3 e
  Floortom 1 (48/47/45/43, rimshot 82/80/78/75); chimbal pelas notas "Trig"
  controladas pelo CC do pedal (8 tip / 7 edge / 9 bell), chick 21 (Closed
  Pedal); condução 51 / borda 59 / cúpula 53; pratos nos slots que coincidem
  com o GM (Cymbal 2 = 49, Cymbal 4 = 57, Cymbal 3 = 55 splash, Cymbal 5 = 52
  china), com choke na nota "Muted".

## 2026-10-02 — Pedal de chimbal (tipo 6) com CC contínuo e calibração de 10 s

- **Pedal de chimbal** (`pad_type` 6) com rotina própria no firmware, no
  lugar da `FSRSensing()` da lib. A rotina da lib arredondava o CC em degraus
  de 20 e usava `scan_time`/`mask_time` como posições de "fechou/abriu", o que
  deixava o SS49E sempre "fechado". Agora o CC vai de 0 a 127 em passos
  contínuos entre os pontos calibrados (respeitando "Inverter"), com filtro
  suave e histerese de 2. O chick sai quando o pedal passa de ~90% do
  percurso e só rearma abaixo de ~70%. A força do chick vem da velocidade de
  fechamento ("sensibilidade do pedal"). O óptico (tipo 7) não mudou.
- **Calibração do pedal**: 10 s em cada posição (eram 3 s), com média dos
  últimos 3 s de cada uma.

## 2026-10-01 — Caixa 3 zonas só com 2 piezos (razões) e varredura só dos canais em uso

- **Caixa 3 zonas** (`pad_type` 8) com sensing novo, `snare3zoneSensing()`:
  **aro** quando pico ring ÷ pico tip ≥ `rim_threshold` % (padrão 30);
  **borda da pele** quando o piezo central tem um pico tardio (3,5–9 ms) ≥
  `rim_sensitivity` % do pico cedo (0–2,5 ms) (padrão 80, experimental);
  **centro** no resto. Regras tiradas da sessão 3 do `rawpad`. Antes o
  tipo reusava a rotina de prato com chaves, que não servia para piezo.
- **Varredura só dos canais em uso**: o loop deixou de ler os 32 canais em
  toda volta — com menos canais, cada um é lido mais vezes, o que a
  detecção de zonas precisa. Comando novo **`get_timing`** informa o tempo
  médio/máximo do loop.
- Calibração automática da caixa 3 zonas passa a calibrar só a pele. Kit de
  fábrica com as razões 80 / 30 no Snare. ConfigTool: campos "Borda da pele
  (razão)" e "Aro (razão)" em %, com ajuda e padrão próprios.
- Detalhes em [05-tipos-de-sensor.md](05-tipos-de-sensor.md).

## 2026-10-01 — Controlador de chimbal (SS49E) funcionando no jack 1

- Jackboard A montada parcialmente (J1 e J2). O SS49E no jack 1 só funcionou
  **sem** a rede de proteção dos canais 0 e 1: todos os componentes retirados,
  jumper do +3,3 V para o tip e jumper no lugar do R2. Com os componentes do
  esquemático a leitura ficava em 0 (causa não identificada).
- Leitura: repouso ~1855, com ímã à mão 1228–2443 (~600 contagens úteis de
  cada lado). Detalhes e cuidados (jack dedicado, plugar desligado, perna TN)
  em [02-hardware.md](02-hardware.md).

## 2026-10-01 — Pinagem do MUX ajustada para a jackboard A montada

- **S0-S3 = GPIO 39/40/41/42** (ordem invertida em relação à anterior) e
  **SIGs trocados**: jackboard A (jacks 1-8) no **GPIO 2**, jackboard B
  (jacks 9-16) no **GPIO 1**. Firmware principal, `mux_test`, `rawpad` e
  `test_hall` atualizados; tabela em [02-hardware.md](02-hardware.md).
- `rawpad` agora lê **pelo MUX** o tip e o ring de um jack (comando `j <n>`,
  padrão jack 1), a **5 kHz por canal** (antes 8 kHz em 2 pinos diretos do
  bring-up sem jackboard).
- `test_hall` lê o SS49E pelo ring do jack 1 (canal 1 do MUX).

## 2026-09-27 — Tela LIVE com 1 célula por jack e apelido do jack

- **LIVE**: grade 4×4 com os **16 jacks** (antes 32 canais), placa A nas
  linhas 1–2 e B nas 3–4. Cada célula mostra o número do jack, 2
  indicadores (tip / ring — acendem no canal que recebeu a batida; num pad
  de 2 zonas o aro/borda conta como ring) e o **apelido**.
- **Apelido do jack**: até **6 caracteres** ASCII — o máximo que cabe na
  célula de 39 px com a fonte 6×8 (6 × 6 − 1 = 35 px + 1 px de respiro de
  cada lado). Sem apelido, a tela usa o nome do pad do tip (ou do ring).
  Comandos novos `get_jacks` / `set_jack` e mensagem `jack_config`;
  gravado numa área nova no fim da EEPROM (placas em uso começam sem
  apelido).
- ConfigTool: campo "Apelido do jack (tela LIVE)" no editor do pad (tira
  acentos sozinho), apelido no cabeçalho de cada jack na lista, e
  export/import levando os apelidos. Kit de fábrica com apelidos HHC, HH,
  KICK, SNARE, TOM1–TOM4, CYM1–CYM4, RIDE e XTRA1–XTRA3.

## 2026-09-27 — Chimbal no padrão do Addictive Drums (CC de posição + nota fixa)

- **Tipos "chimbal simples" e "chimbal 2 zonas" ocultos** (firmware e
  ConfigTool): o chimbal passa a ser um pad comum com nota fixa — no AD2,
  8 (tip) / 7 (borda) / 9 (bell) — e o software decide aberto/fechado pelo
  CC do pedal. O código continua no firmware, configs antigas seguem
  funcionando e `set_pad` ainda aceita (import de backups).
- **Pedal de chimbal**: novo `pedal_note` (liga/desliga a nota de chick ao
  fechar — no AD2 quem gera o chick é o software) e `pedal_cc` (número do
  CC de posição, padrão 4). Na tela: itens CHICK e CC no editor do pedal.
  Gravados em 2 áreas novas no fim da EEPROM (placas já em uso leem o
  padrão antigo: chick ligado, CC 4).
- **Kit de fábrica**: HH Pedal só com CC4 (sem chick); HiHat como pad
  simples na nota 8.
- ConfigTool: mapa AD2 com 8/7/9 no grupo HiHat e "Aplicar mapa aos pads"
  usando essas notas; export/import com `pedal_note`/`pedal_cc`.

## 2026-09-27 — ConfigTool: exportar e importar configuração (JSON)

- Aba Global > **Backup e compartilhamento**: "Exportar configuração
  (.json)" salva tipos, nomes, notas, calibração e crosstalk dos pads, mais
  canal/saída MIDI e o mapa MIDI escolhido
  (`drumcore-config-AAAA-MM-DD.json`).
- "Importar configuração…" valida o arquivo e mostra um resumo antes de
  aplicar (pads, canal MIDI, mapa, nomes), com opções de levar ou não os
  nomes e o canal/saída MIDI, e avisos do que não dá para aplicar (ex:
  sensor de 2 zonas num ring). Aplica só o que muda, em fila com progresso.
- A fila de envio passa a esperar a resposta certa de cada campo
  (`pad_config` para label/tipo/ativo/pedal, `ack` para os numéricos e para
  `set_global`) e informa quantas alterações o módulo recusou.
- Formato documentado em [04-protocolo-serial.md](04-protocolo-serial.md)
  ("Arquivo de configuração do ConfigTool"). Sem mudança no firmware.

## 2026-09-27 — Mapeamento de fábrica, restaurar padrão de fábrica e fim do bring-up sem jackboard

- **Kit de fábrica** (`applyFactoryPreset()`): HH Pedal, HiHat, Kick,
  Snare 3 zonas, Tom 1–4, Cym 1–4 com choke no ring, Ride 1 3 zonas e 3
  jacks livres, com notas do Addictive Drums 2. Tabela completa em
  [02-hardware.md](02-hardware.md). Gravado na primeira inicialização da
  EEPROM.
- **Restaurar padrão de fábrica**: comando `factory_reset` (exige
  `"confirm": true`), botão com confirmação na aba Global do ConfigTool e
  item GLOBAL > FABRICA na tela do módulo (2 cliques para confirmar). Apaga
  a configuração atual.
- **Bring-up sem jackboard removido**: o firmware não desliga mais os
  canais 3–32 a cada boot nem lê os canais 1–2 direto dos GPIO 9/10 — os
  32 canais voltam a ser lidos pelo MUX. `GPIO9`/`GPIO10` ficam livres.
- ConfigTool: o modo demo começa com o kit de fábrica; canal desligado sem
  nome aparece como "livre"; Restaurar da memória e fábrica limpam o
  histórico de desfazer.

## 2026-09-27 — Firmware: regra do tip e telas agrupadas por jack

- **Regra**: sensor de 2 zonas só pode começar no **tip** do jack (canal
  0-based par). `set_pad` de `pad_type` responde `error`
  `two_channel_needs_tip` num ring; na tela física o encoder pula os tipos
  de 2 zonas nesses pads, em vez de travar. Configurações antigas salvas
  na EEPROM que atravessam jacks continuam funcionando, mas aparecem
  marcadas em laranja.
- **LIVE**: grade 8×4 agrupada como a jackboard — tip e ring colados, mais
  respiro entre jacks e entre as placas A (pads 1–16) e B (17–32); pad de
  2 zonas vira uma célula larga ocupando o jack.
- **Lista de pads**: colchete por jack, coluna T/R, a linha do ring de um
  pad de 2 zonas mostra "+ aro" (ou borda/cup) com a nota da 2ª zona, e o
  título mostra o jack ("J02 03/32"). A rolagem anda sempre de jack em
  jack.
- Modo demo do app recusa igual ao firmware.

## 2026-09-27 — ConfigTool: pads agrupados por jack (tip/ring)

- A lista de pads passa a mostrar os canais agrupados como estão na placa:
  um bloco por jack TRS (tip = pad ímpar, ring = pad par), separados em
  Placa A (jacks 1–8) e Placa B (jacks 9–16). Sensor de 2 zonas vira um
  item só no bloco ("tip pele · ring aro", notas "38 / 39").
- Editor: chip "Jack N · tip/ring"; tipos de 2 canais bloqueados nos pads
  do ring (a 2ª zona cairia no jack seguinte); aviso ⚠ para configurações
  que já atravessam jacks (ex: feitas pela tela do módulo).
- Convenção documentada em [02-hardware.md](02-hardware.md). Só no app — o
  firmware ainda aceita 2 canais começando no ring.

## 2026-09-27 — Bug corrigido: tela não atualizava após mudanças feitas pelo app

- Renomear um pad pelo app (e também mudar nota, tipo, ativo, valores,
  canal/saída MIDI ou usar Salvar/Restaurar) não redesenhava a tela
  física, e a mudança só aparecia no próximo movimento do encoder ou na
  troca de página. O despacho de `set_pad`/`set_global`/`save_all`/
  `restore_all` agora marca `forceScreenRedraw`. Vários comandos seguidos
  (ações em lote) viram um único redesenho.
- Primeira release de teste com a correção do `apply_autotune`
  persistente (abaixo): `fw-v0.0.5-test`.

## 2026-09-26 — ConfigTool: aba Pads redesenhada, mapas MIDI (GM + Addictive Drums 2) e ações em lote

- **Parâmetros**: sliders com trilha preenchida e campo numérico,
  unidades reais (ms, %), padrão de fábrica com restauração, ajuda por
  parâmetro e envio com debounce (menos gravações na EEPROM).
- **Organização**: seções (Identificação, Detecção, Resposta, Crosstalk,
  MIDI), cabeçalho "Pad N · nome" com ◀ ▶, switch Ativo/Inativo, curva
  com gráfico usando as fórmulas reais do firmware, nota MIDI com nome e
  instrumento, grupo de crosstalk segmentado.
- **Mapas MIDI**: General MIDI e **Addictive Drums 2** (padrão), com
  **"Aplicar mapa aos pads"**, que preenche as notas de cada zona a partir
  do instrumento de cada pad.
- **Ações por pad** (menu ⋯): copiar, colar, copiar para outros pads e
  restaurar padrões, enviados em fila com progresso.
- **Calibração**: tabela atual → proposto, aplicação parcial por
  checkbox e a linha do gain (que o apply sempre força em 100%) agora
  visível.
- **Ao vivo**: flash de batida na lista proporcional à velocity, monitor
  de velocity do pad selecionado, "Seguir pad tocado".
- **Desfazer/refazer** (Ctrl+Z / Ctrl+Shift+Z), painel **"?"** de
  atalhos, barra de conexão única com estado DEMO inconfundível, log
  recolhível e layout responsivo para tablet.
- Detalhes: [01-decisoes-arquiteturais.md](01-decisoes-arquiteturais.md)
  (Fase AC).

## 2026-09-26 — `apply_autotune` passa a gravar na EEPROM

- **Bug**: `applyAutoTuneResult()` só alterava a RAM e marcava
  `unsavedChanges` — a calibração aplicada se perdia ao desligar o módulo
  se ninguém usasse SALVAR, apesar de o
  [04-protocolo-serial.md](04-protocolo-serial.md) já dizer "persiste em
  EEPROM". Agora grava na hora (`initMemory()` + `persistPadRetrigger()` +
  `persistPadGain()`), igual a um `set_pad` do app.
- Vale também pro apply feito pela tela física: calibração aplicada não
  depende mais do SALVAR, e o RESTAURAR não a desfaz.
- Documentado o que já acontecia sem constar no protocolo: o apply força
  `gain` = 100.
- App (ConfigTool): a tabela de resultado da calibração mostra a linha do
  gain e permite aplicar só parte dos valores (`cancel_autotune` +
  `set_pad` dos campos escolhidos — sem comando novo).

## 2026-09-15 — Fase AB: `curve` e `retrigger` inferidos automaticamente pelo auto-tune de pads

- O assistente de auto-calibração passa a decidir sozinho a **curva de
  resposta** (`curve_type`) e o **retrigger**, além de sensitivity/
  threshold/scan/mask/rim_* já calibrados — reaproveitando dados que a
  coleta já produzia e não usava pra nada (nível MÉDIO, antes só
  "checagem de consistência"; taxa de decaimento, já usada pro
  `mask_time`). Sem coleta extra, sem gate de qualidade — infere e aplica
  direto, mesmo padrão dos demais campos; o usuário sempre pode ajustar
  `CURVA`/`RETRIG` manualmente depois.
- **`curve`**: olha onde o pico médio do nível MÉDIO caiu dentro da faixa
  threshold..sensitivity. Perto do meio → LINEAR. Colado no threshold
  (sensor comprime força baixa/média) → LOG (mais resolução onde o
  usuário mais toca). Colado no sensitivity (sensor satura rápido) → EXP.
- **`retrigger`**: taxa de decaimento observada (pico forte até cair pra
  metade) vira um piso decrescente calibrado, um pouco mais devagar que o
  real medido de propósito (evita confundir ringing com pancada nova).
  Pad com decaimento lento naturalmente sai com retrigger baixo/0 da
  própria fórmula.
- Só se aplica a pads de impacto — o controlador de pedal (HHC) não ganha
  nenhum dos dois campos.
- Detalhes completos: [01-decisoes-arquiteturais.md](01-decisoes-arquiteturais.md)
  (Fase AB)

## 2026-09-15 — Bug corrigido: `retrigger` comparava domínios diferentes (bug desde a Fase P)

- Achado ao desenhar a calibração automática do `retrigger` (próxima
  entrada abaixo): o piso decrescente do `retrigger` (`decayFloor`) partia
  de `velocity`, que a própria lib reaproveita tanto pra pico **bruto**
  (durante o scan) quanto pro resultado **já mapeado por `curve()` pra
  1-127** (assim que o golpe termina) — mas era comparado contra
  `piezoValue`, sempre bruto. Na prática, o piso caía abaixo de qualquer
  valor bruto plausível quase imediatamente, deixando passar quase
  qualquer coisa durante o `mask_time`, quase sempre, independente da
  força real do novo golpe — `retrigger` não estava de fato exigindo "bem
  mais forte que o anterior" como pretendido.
- Sem efeito pra quem usa `retrigger = 0` (comportamento original,
  intocado). Nunca testado com hardware real, nem antes nem depois da
  correção.
- Corrigido em `firmware/lib/HelloDrum-arduino-Library/src/hellodrum.h`/
  `hellodrum.cpp` (`singlePiezoSensing()`, `dualPiezoSensing()`,
  `cymbal2zoneSensing()`, `cymbal3zoneSensing()`) — 2 campos novos,
  `lastRawVelocity`/`lastRawVelocityRim`, guardam o pico bruto do golpe
  anterior separado do resultado mapeado. Detalhes completos:
  [03-biblioteca-hellodrum.md](03-biblioteca-hellodrum.md).

## 2026-09-15 — Fase AA: auto-tune de pads passa a colher por janela de tempo (10s por nível)

- **Cada nível de força (fraco/médio/forte) agora colhe por 10 segundos**
  em vez de uma meta fixa de 8 golpes — mais amostras por nível, média
  mais confiável, principalmente pra quem não bate com força constante
  golpe a golpe. Pedido do Rodrigo. **Fora de escopo**: a calibração do
  controlador de pedal (HHC) continua igual (3s segurando cada posição),
  não é um sensor de impacto.
- `firmware/src/main.cpp`: `AUTOTUNE_HIT_TARGET` (8) vira
  `AUTOTUNE_TIER_WINDOW_MS` (10000) — a condição de "nível completo" em
  `autoTuneTick()` deixa de ser contagem de golpes e passa a ser tempo
  decorrido desde `atTierStartMs`, checado tanto logo após capturar um
  golpe quanto ociosamente esperando o próximo (pra não travar esperando
  um golpe que não precisa mais vir). Lógica de avançar nível/zona/
  finalizar extraída pra `advanceAfterAutoTuneTier()`. Médias em
  `finishAutoTune()` passam a dividir pela contagem real de golpes de
  cada nível/zona (`atHitCountByTier`/`atRimHitCountByTier`/
  `atCupHitCountByTier`, novos), não mais por uma constante.
- Tela física (`renderAutoTune()`): barra de progresso por contagem de
  golpes vira contagem regressiva em segundos + barra por tempo
  decorrido (mesmo padrão já usado na calibração do pedal); golpes
  capturados continuam visíveis como texto pequeno complementar.
- Protocolo: `autotune_status` troca o `hit_target` fixo por
  `tier_elapsed_ms`/`tier_target_ms` (ver
  [04-protocolo-serial.md](04-protocolo-serial.md)).
- `web-app/`: `PadEditor.tsx` (barra/contagem por tempo, texto de dica
  reescrito), `protocol.ts` (`AUTOTUNE_TIER_WINDOW_MS`), `mockDevice.ts`
  (simulação de demonstração segue o mesmo modelo de janela de tempo).
- Detalhes completos:
  [01-decisoes-arquiteturais.md](01-decisoes-arquiteturais.md) (Fase AA)

## 2026-09-12 — Licença do projeto: CC BY-NC 4.0

- Adiciona `LICENSE` na raiz do repositório: Creative Commons
  Atribuição-NãoComercial 4.0 Internacional (CC BY-NC 4.0) — uso e cópia
  livres, sem fins comerciais, sempre citando a fonte (o próprio DrumCore
  e, quando aplicável, a HelloDrum-arduino-Library). Deixa explícito que
  a biblioteca vendorizada em `firmware/lib/HelloDrum-arduino-Library/`
  mantém sua própria licença MIT original (Ryo Kosaka), não substituída
  pela CC BY-NC.
- `README.md` ganha seção "Licença" apontando pro `LICENSE`.
  `web-app/package.json` ganha o campo `license`.
- Site (`site/index.html`, `site/hardware.html`,
  `site/assets/schematic.html`): nota de licença + link no rodapé de
  todas as páginas.

## 2026-09-12 — 2 bugs corrigidos na tela SIGNAL (osciloscópio ao vivo)

- **Escala vertical errada**: o gráfico limitava a escala em 0-1023 (ADC de
  10 bits), mas o ADC do ESP32-S3 é de 12 bits (0-4095, `ADC_RAW_MAX`) — o
  resto do firmware (gain, threshold, etc.) já assumia 0-4095. Qualquer
  leitura real acima de 1023 aparecia cortada/achatada no topo do gráfico.
  Corrigido em `renderSignal()` (`firmware/src/main.cpp`).
- **Gráfico "congelado"**: só redesenhava ao entrar na tela ou trocar de
  pad (girar o encoder) — o buffer (`captureSignalSample()`) continuava
  sendo alimentado a cada `loop()` em segundo plano, mas a linha na tela
  não se mexia sozinha enquanto o pad era tocado. Corrigido forçando
  redesenho todo `loop()` enquanto a tela SIGNAL estiver aberta.

## 2026-09-11 — Novo tipo de sensor: Choke (fita de contato); bring-up dos canais 1/2 sem jackboard

- **`pad_type` 9 (`PAD_CHOKE`)**: fita de alumínio ligada direto num pino
  analógico (sem piezo) — gatilho binário, dispara a nota configurada com
  `velocity` sempre `127` quando o `rawValue[]` cruza um threshold (com
  histerese pra não repetir enquanto a fita fica encostada). Implementado
  fora da lib vendorizada (`dispatchChoke()` em `firmware/src/main.cpp`,
  não usa nenhum método `HelloDrum::...MUX()`). Bem mais simples de
  configurar que os outros 9 tipos: só `threshold` e `note` (sem
  sensitivity/scan/mask/retrigger/gain/curva/xtalk, e sem auto-tune — ver
  [05-tipos-de-sensor.md](05-tipos-de-sensor.md), seção "Tipo 9").
- Evento `hit` desse tipo usa a zona `"touch"` (não `"choke"` — nome já
  ocupado pelo gesto de abafar prato/caixa nos tipos 3/5/8, mecanismo
  diferente baseado em envelope de vibração).
- `firmware/start_autotune` e o modo demo (`web-app/src/mockDevice.ts`)
  recusam calibrar um pad desse tipo (`error: "not_applicable_for_choke"`).
  `web-app` (`protocol.ts`/`PadEditor.tsx`) atualizado em conjunto: novo
  item na lista de tipos, painel de auto-tune escondido pra esse tipo.
- **Bring-up sem jackboard ainda montada**: os 2 canais de teste (canal 1
  e 2, "Pad 1"/"Pad 2") passaram a ser lidos direto de 2 pinos livres do
  ESP32-S3 (`GPIO9`/`GPIO10`, ambos ADC1), sobrescrevendo `rawValue[0]`/
  `[1]` depois do `scan()` dos MUX — os outros 30 canais continuam
  desligados em RAM. Substitui o hack anterior de um único pino
  (`TEST_DIRECT_HEAD_PIN`, usado só pro teste do sensor hall) — remover
  (voltar a ler pelo MUX0 de verdade) quando a jackboard for montada e
  conectada.

## 2026-09-06 — Aba MIDI Monitor no ConfigTool

- **Nova aba "MIDI Monitor"** (`web-app/src/components/MidiMonitor.tsx`),
  entre Global e Firmware — independente da conexão Web Serial (protocolo
  NDJSON), usa a **Web MIDI API** (`navigator.requestMIDIAccess()`)
  direto do navegador.
- Enxerga tanto a porta USB-MIDI nativa do módulo (descriptor "DRUMCORE",
  ver `TinyUSBDevice.setProductDescriptor()` em `firmware/src/main.cpp`)
  quanto qualquer porta BLE-MIDI já pareada no SO — um único seletor
  cobre os dois transportes, com auto-seleção de qualquer porta cujo
  nome contenha "drumcore".
- Log em tempo real decodificando Note On/Off (com nome da nota),
  Control Change, Program Change, Aftertouch e Pitch Bend, com
  pausar/limpar. Tipos da Web MIDI API já vêm no `lib.dom.d.ts` do
  TypeScript 5.9 — nenhuma dependência nova precisou ser adicionada.
- Só funciona em Chrome/Edge (mesma limitação do Web Serial já usado no
  resto do app) e em contexto seguro (HTTPS/localhost) — GitHub Pages já
  atende. Validado via `tsc --noEmit`/`vite build`; teste com hardware
  real ainda pendente.

## 2026-09-06 — Menu do site reorganizado; página de gravação manual removida

- **Nav padronizado** em `site/index.html`, `site/hardware.html` e no
  topnav do app (`web-app/src/App.tsx`): ordem única "Visão geral,
  Hardware, ConfigTool, GitHub" nas três telas. O item que apontava pro
  app web foi renomeado de "Configurar (web)" pra **ConfigTool**.
- **`site/flash.html` removido**: o guia manual de compilar/gravar via
  PlatformIO ficou redundante — a aba Firmware do ConfigTool já baixa a
  release mais recente e grava direto do navegador via Web Serial. Todos
  os links/botões que apontavam pra essa página (nav, hero, cards,
  rodapé) também saíram.

## 2026-09-06 — Desktop (Electron) aposentado; app web unificado visualmente com o site

- **Decisão**: só o app web (`web-app/`) segue como forma de configurar o
  módulo — o build Electron nunca chegou a ser usado de fato fora de teste
  local, e mantê-lo vivo só duplicava trabalho toda vez que algo mudava em
  `App.tsx`/`protocol.ts`/etc (ver entrada de 2026-09-06 acima, que já
  descrevia o problema da dependência cruzada `web-app/` → `desktop-app/`).
- **`desktop-app/` removido por completo**: processo principal Electron,
  preload/`contextBridge`, `serialport`, `electron-builder`/NSIS e a
  pipeline `.github/workflows/app-release.yml` que gerava o instalador
  Windows — tudo apagado, sem deixar código morto.
- **Arquivos migrados, não duplicados**: `App.tsx`, `components/`
  (`FirmwareManager.tsx`/`PadEditor.tsx`/`PadGrid.tsx`), `env.d.ts`,
  `firmwareCheck.ts`, `mockDevice.ts`, `protocol.ts`, `styles.css`,
  `webDrumCore.ts` e o asset `esp32-uart.png` foram movidos (`git mv`) de
  `desktop-app/src/renderer/src/` pra `web-app/src/` — `web-app` deixa de
  importar arquivos de fora da própria pasta, e o `resolve.alias` +
  `server.fs.allow` do `vite.config.ts` (workarounds pra resolução
  cross-package do Node/TS) saem de cena.
- **Visual unificado**: `web-app/src/styles.css` reescrito pra usar a
  mesma paleta/tipografia do site (`site/assets/style.css` — IBM Plex
  Sans/Mono no lugar de Space Grotesk, tokens de cor do site no lugar dos
  antigos `--accent`/`--edit`/`--hit`). App ganhou o mesmo `<nav
  class="topnav">` do site no topo, com os mesmos links (Visão geral,
  Configurar (web), Gravar firmware, Hardware, GitHub).
- **Logo novo**: a marca "DRUMCORE" (grade de pixels 8x4, direção 1A de
  `design/LOGOS.md` — mesmo bitmap usado no silkscreen da jackboard) virou
  um SVG inline (`web-app/src/components/Logo.tsx`), reusado no nav do
  site (`site/index.html`/`hardware.html`/`flash.html`, substituindo o
  antigo `.dot`) e no nav do app.
- Textos que ainda descreviam o app como "desktop"/Electron atualizados em
  `README.md`, `site/index.html`, `docs/00-visao-geral.md`,
  `docs/02-hardware.md`, `docs/04-protocolo-serial.md`,
  `docs/05-tipos-de-sensor.md` e nos comentários do firmware
  (`firmware/src/main.cpp`) — entradas antigas deste changelog e de
  `docs/01-decisoes-arquiteturais.md` continuam descrevendo o que era
  verdade em cada data, sem reescrita retroativa.

## 2026-09-06 — App de configuração também como página web (`web-app/`)

- **Motivação**: a aba Firmware já usava Web Serial (funciona em qualquer
  navegador Chromium, não só Electron) — deu pra estender o mesmo
  mecanismo pras abas Pads/Global e publicar o app inteiro como uma
  página do `site/` (GitHub Pages), sem precisar instalar nada.
- **Reuso total de código**: só `App.tsx` e `FirmwareManager.tsx` tocavam
  `window.drumCore` (confirmado por grep) — todo o resto
  (`PadGrid`/`PadEditor`/`protocol`/`mockDevice`/`styles.css`) já era
  100% portável. Novo `web-app/` (projeto Vite standalone, irmão de
  `desktop-app/`) reusa esses arquivos direto de
  `desktop-app/src/renderer/src/` via import relativo — zero duplicação.
- **`webDrumCore.ts`** (novo): segunda implementação de `DrumCoreApi`
  (a de sempre é o preload/`contextBridge` do Electron), baseada em
  `navigator.serial` — leitor de linhas NDJSON via `TextDecoderStream`
  equivalente ao `ReadlineParser` do lado Electron
  (`desktop-app/src/main/serial.ts`). `listPorts()` sempre `[]` (Web
  Serial não expõe nome de porta por privacidade) — `App.tsx` ajustado
  pra só exigir porta selecionada quando a lista não estiver vazia.
- **CORS do firmware resolvido na raiz, não mais contornado**: descoberto
  que `raw.githubusercontent.com` manda `Access-Control-Allow-Origin: *`
  pra qualquer arquivo do repo — diferente dos assets de Release
  (`release-assets.githubusercontent.com`, sem CORS). A CI de release do
  firmware (`firmware-release.yml`) agora também publica
  `manifest.json`/`.bin` num branch dedicado (`firmware-artifacts/<tag>/`,
  um commit por release). Isso eliminou a necessidade de proxy externo
  (chegou a ser cogitado Cloudflare Worker) e permitiu **remover** todo o
  caminho IPC que tinha sido criado pra isso no Electron
  (`desktop-app/src/main/firmwareRelease.ts` e os 2 handlers
  correspondentes) — `FirmwareManager.tsx` agora usa um módulo
  compartilhado (`firmwareCheck.ts`) igual nos dois builds.
- **Publicação**: `.github/workflows/pages.yml` builda `web-app/` e
  publica em `site/app/` junto do site estático de sempre —
  `https://orodamaral.github.io/drumcore/app/`. Link novo no nav/hero de
  `site/index.html`.
- Validado localmente: `web-app` compila e builda limpo (typecheck +
  `vite build`, incluindo os componentes reusados do `desktop-app`);
  `desktop-app` continua buildando normalmente depois da remoção do
  código IPC de firmware. Teste real de conexão via Web Serial (que
  precisa de navegador + hardware) fica para o Rodrigo.

## 2026-09-06 — Firmware gravado não bootava; achado e corrigido (CI + CORS + layout)

- **Sintoma real**: Rodrigo gravou o firmware pela aba nova e a tela não
  ligou. Pinagem (encoder/tela/MUX/GPIO9) conferida linha a linha em
  `firmware/src/main.cpp` contra `docs/02-hardware.md` — bate 100%, não
  era bug de pinagem.
- **Causa raiz #1 (CORS)**: "Verificar atualizações" na aba Firmware
  falhava com "Failed to fetch" — os links de asset do GitHub
  (`release-assets.githubusercontent.com`) não mandam CORS liberado pro
  renderer. Fetch/download movidos pro processo main (Node, sem essa
  restrição) via novo `desktop-app/src/main/firmwareRelease.ts` + 2
  handlers IPC.
- **Causa raiz #2 (o binário mesclado vinha com cabeçalho errado)**: a CI
  de release montava o `merge_bin` assumindo `--flash_mode qio` (baseado
  num comentário errado do `platformio.ini`) e sem `--flash_freq` — o real
  é `dio`/`80m` (confirmado no comando de upload de verdade). Um binário
  com flash_mode errado grava sem erro nenhum mas não boota direito
  (sensível aqui por causa da PSRAM octal). `extract_flash_args.py`
  reescrito pra extrair os valores reais do log verboso do PlatformIO em
  vez de assumir.
- **Causa raiz #3 (a CI nunca chegava a rodar o upload verboso)**: mesmo
  corrigido, a extração continuava falhando — o log nunca tinha uma linha
  `write_flash`. Diagnosticado publicando o log completo num branch
  temporário (`ci-debug-logs`, já removido) pra ler sem precisar de token
  de autenticação. Causa: a instalação do zero da CI puxa
  `tool-scons@~4.41101.0` (SCons upstream 4.11.1), que tem um bug real no
  modo verbose (`SCons/Action.py:print_cmd_line` faz `s + "\n"` com `s`
  sendo o sentinela interno `_Null`, `TypeError`, build inteiro falha).
  Tentativa de fixar a versão via `platform_packages` não colou (o
  PlatformIO detecta o conflito e remove a versão fixada, mantendo a que
  o `espressif32` pede). Solução: `.github/scripts/
  patch_scons_verbose_bug.py`, que corrige o arquivo com bug depois que o
  PlatformIO instala os pacotes (build normal primeiro, sem `-v`) e antes
  do build verboso que a CI precisa pra descobrir os parâmetros reais.
  De quebra, também fixada a versão da plataforma (`espressif32@7.0.1`)
  pra CI parar de divergir silenciosamente da versão testada localmente.
- **Layout**: o quadro da aba Firmware ficava restrito a 640px (sobrava
  num canto) — removido, agora ocupa a página inteira como as outras
  abas.
- Validado publicando `fw-v0.0.2-test`: manifest e binário conferidos
  byte a byte (`flash_mode: dio`, cabeçalho `0x02` correto, versão
  embutida certa) — pipeline completa (build → extrai parâmetros reais →
  mescla → publica) funcionando de ponta a ponta pela primeira vez.

## 2026-09-06 — Aba de Firmware no app desktop + instalador do app

- **Objetivo**: montar/atualizar um DrumCore sem saber programar — hoje
  exigia PlatformIO CLI (firmware) e `npm run dev` (app desktop).
- **Nova aba "Firmware"** no app (`desktop-app/src/renderer/src/components/
  FirmwareManager.tsx`): busca a release de firmware mais recente no
  GitHub (tag `fw-v*`), baixa o binário e grava no ESP32-S3 via Web Serial
  + `esptool-js` (port oficial da Espressif do protocolo esptool, sem
  precisar de Python/esptool.py instalado). Cobre primeira gravação e
  atualização com o mesmo fluxo. Inclui a foto da placa com a porta
  USB-UART marcada (a que faz auto-reset pro bootloader, confirmada pelo
  Rodrigo) como guia visual.
- **Pipeline de release do firmware** (`.github/workflows/
  firmware-release.yml`, tag `fw-v*`): builda com PlatformIO, mescla
  bootloader+partition table+app num único `.bin` (offset `0x0`, via
  `esptool merge_bin` — offsets extraídos do log verboso do próprio build
  em vez de hardcoded, `.github/scripts/extract_flash_args.py`), publica
  junto com um `manifest.json`.
- **Versão do firmware**: era só o literal `"v0.1"` sem fonte única —
  agora `FW_VERSION` é injetado via `build_flags` a partir da tag git
  (`firmware/version_flag.py`), usado na tela BOOT e no campo
  `firmware_version` de `device_info` (permite o app comparar "versão
  conectada" vs "última release").
- **Instalador do próprio app desktop**: `electron-builder` (NSIS,
  Windows) + pipeline própria (`.github/workflows/app-release.yml`, tag
  `app-v*`) — sem isso, ter uma aba de firmware no app não ajudava quem
  não sabe rodar `npm run dev`. Sem assinatura de código por enquanto
  (SmartScreen vai avisar).
- Testado localmente nesta máquina: `npm run dist` gerou um instalador
  `.exe` funcional (~107MB) com o módulo nativo do `serialport`
  recompilado certo pro Electron. O fluxo de flash em si (esptool-js +
  Web Serial) só é validável com hardware real — ver
  `desktop-app/src/main/index.ts` (handler `select-serial-port`, escolhe a
  primeira porta da lista por simplicidade, revisar se aparecer mais de
  uma porta serial disponível na prática).

## 2026-09-06 — Jackboard: roteamento completo, silk final, logo e ajuste de placa

- **Roteamento completo** (via Konnect MCP): as 16 trilhas de canal (U1 →
  rede de proteção de cada canal) e o barramento de controle U2↔J9 (S0-S3,
  SIG, +3V3, GND) foram totalmente roteados. Conflitos de cruzamento
  resolvidos com detours e com divisão de camada (56 trilhas de junção
  série→paralelo→diodo movidas pra B.Cu). DRC limpo: 0 `shorting_items`,
  0 `unconnected_items` — só ficam os 112 avisos de courtyard/PTH aceitos
  por design (footprints de jack fisicamente próximos dos resistores/diodos
  do canal, sem risco elétrico real).
- **U1/U2 recentralizados**: os headers do HC4067 (U1, 16 pinos) e do
  header de controle (U2, 8 pinos) estavam deslocados ~8mm à direita do
  centro real da placa (resquício de uma placa mais larga de uma fase
  anterior). Corrigido com um shift uniforme de -8.32mm em X nos dois, com
  re-roteamento completo das 66 trilhas afetadas.
- **Silkscreen só com referência (sem valor)**: referências dos resistores/
  diodos (R.SilkS/F.SilkS) ajustadas à mão pelo Rodrigo no KiCad — texto de
  valor ocultado, referência rotacionada legível dentro do componente.
  Nenhuma ferramenta Konnect expõe edição de `fp_text`/rotação hoje (só
  gráficos de footprint, não texto) — ajuste feito direto na UI do KiCad.
- **Logo "DRUMCORE" na serigrafia** (F.SilkS, canto superior esquerdo):
  wordmark pixel-art 5x7 (134 quadrados), direção 1A do `design/LOGOS.md`.
  Construído pixel a pixel via `import_svg_logo` (a ferramenta só persiste
  a 1ª forma de um SVG multi-shape — workaround: 1 chamada por pixel, com
  um SVG reutilizável de 1 quadrado). Colocado por engano em B.SilkS
  (verso) na primeira tentativa; corrigido para F.SilkS (frente/topo).
- **Pad de teste +3V3 no estilo dos resistores**: o antigo via de acesso a
  +3V3 perto do J1 foi substituído por um footprint de pad único (círculo
  THT 1.6mm/furo 0.8mm, mesmas dimensões do pad dos resistores) — criado via
  `create_footprint` na biblioteca local do projeto
  (`drumcore_jackboard.pretty/TestPoint_3V3.kicad_mod`). O net do pad não
  pôde ser atribuído por nenhuma ferramenta Konnect (sem símbolo no
  esquemático, não há chamada de "atribuir net a um pad solto"); atribuído
  manualmente pelo Rodrigo no KiCad (Pad Properties → Net → `/+3V3`).
- **Ajuste de dimensão da placa**: altura reduzida em ~2.5mm (feito manualmente
  pelo Rodrigo no KiCad) pra deixar a rosca de um dos jacks pra fora da
  placa. A malha de GND (`GND_POUR_BOTTOM`, B.Cu) foi recriada com o novo
  contorno e recalculada (`refill_zones`).
- **Gerbers regenerados** (3x ao longo do dia, conforme cada ajuste acima) em
  `hardware/jackboard/fab/`, incluindo `drumcore_jackboard_gerbers.zip`.
- **Arquitetura esclarecida (confirmado por Rodrigo)**: o sistema final usa
  **2 jackboards idênticas** (16 canais cada) para completar os 32 canais
  já descritos em `docs/00-visao-geral.md`/`docs/02-hardware.md` (2x
  CD4067) — a jackboard atual não é uma redução de escopo, é a primeira das
  duas unidades. `README.md` atualizado pra refletir isso.

## 2026-09-06 — Pinout da tela ajustado pro conector + mainboard aposentada

- **Tela**: os 6 GPIOs (dentro do mesmo bloco contíguo da Fase Z) foram
  reordenados pra bater com a ordem física do conector dela (`GND VDD SCL
  SDA RES DC CS BLK`) — `SCL(7) → SDA(15) → RES(16) → DC(17) → CS(18) →
  BLK(8)`, a pedido do Rodrigo. Atualizados `firmware/src/main.cpp` (+
  `test_display.cpp`/`test_hall.cpp`, que tinham pinos antigos próprios),
  `docs/02-hardware.md` e o esquemático.
- **Validado em hardware real**: Rodrigo religou o encoder e a tela
  nesse pinout novo — os dois confirmados funcionando (navegação por
  encoder, imagem na tela). O MUX ainda não foi conectado nesse layout.
- **Mainboard aposentada**: com o pinout novo, a fiação ficou pouca o
  bastante pra conectar tudo direto nos headers da própria placa de dev
  do ESP32-S3, sem precisar de uma PCB dedicada — `hardware/mainboard/`
  (`.kicad_sch`/`.kicad_pcb`/`.kicad_pro`/`.kicad_prl`/`.png`) foi
  **apagado** do repositório. Isso resolve (por não ser mais relevante) o
  pendente da Fase Z sobre esse projeto ainda ter 2 encoders desenhados —
  não existe mais projeto pra corrigir. A jackboard continua normalmente.

## 2026-09-05 — Fase Z: pinout reorganizado por função (encoder+tela vs MUX)

- **Motivação**: a placa física ganhou pads de `3V3`/`GND` extras nos 2
  headers (modificação fora do dev board original) — isso removeu a
  restrição de alimentação que forçava o MUX e a tela a ficarem no mesmo
  header (Fase L). Pedido do Rodrigo: reorganizar por FUNÇÃO — encoder +
  tela de um lado, MUX (sensing) do outro, sempre mantendo blocos de
  pinos fisicamente contíguos.
- **Novo pinout**: header ESQUERDO = encoder (`GPIO4,5,6`) + tela
  (`GPIO7,15,16,17,18,8`), um bloco contíguo de 9 pinos. Header DIREITO =
  2x CD4067 (`GPIO42,41,40,39` pras linhas de seleção S0-S3, `GPIO1,2`
  pros 2 pinos SIG — os únicos 2 ADC desse bloco, agora ADC1 em vez de
  ADC2). Teste temporário do sensor hall (`TEST_DIRECT_HEAD_PIN`) migrado
  de GPIO17 (virou sinal permanente da tela) pra GPIO9 (livre).
- **Ajuste (2026-09-06)**: os 6 GPIOs da tela, dentro desse mesmo bloco,
  foram reordenados pra bater com a ordem física do conector dela (`GND
  VDD SCL SDA RES DC CS BLK`) — `SCL(7) → SDA(15) → RES(16) → DC(17) →
  CS(18) → BLK(8)`, a pedido do Rodrigo.
- De quebra, corrigida uma nota antiga: `GPIO43`/`GPIO44` nunca estiveram
  livres — são o UART físico usado pelo `Serial` (protocolo NDJSON), não
  "sem uso previsto" como o doc dizia.
- Atualizados `firmware/src/main.cpp`, `docs/02-hardware.md`,
  `docs/assets/esquematico-hellodrum.html` (e a cópia em `site/`). Ver
  [01-decisoes-arquiteturais.md](01-decisoes-arquiteturais.md) (Fase Z)
  pro racional completo.
- **Validado em hardware real (2026-09-06)**: Rodrigo religou o encoder e
  a tela nesse pinout novo — os dois confirmados funcionando (navegação e
  imagem na tela). O MUX ainda não foi conectado nesse layout.
- **Pendente** (resolvido no dia seguinte — ver entrada 2026-09-06 acima):
  `hardware/mainboard/*.kicad_sch`/`.kicad_pcb` ainda não tinham sido
  atualizados pra esse pinout novo nem pra 1 encoder só (Fase Y). A
  fiação do MUX também ainda precisa ser feita.

## 2026-09-04 — Fase Y: navegação reduzida de 2 encoders pra 1 (rotate/click/hold)

- **Motivação**: o ENC1 (página/pad em foco) tinha poucas responsabilidades
  na prática, enquanto o ENC2 concentrava quase toda a navegação. Decisão:
  1 encoder só, cobrindo tudo via hierarquia de profundidade — girar
  navega no nível atual, clicar desce um nível (ou confirma/dispara uma
  ação), segurar sempre volta um nível (em PADS/GLOBAL, volta direto pra
  LIVE).
- Item novo "SINAL" na lista de campos do PAD_EDIT — antes, alternar
  PAD_EDIT↔SIGNAL era o click do ENC1 (uma ação lateral que não cabia no
  modelo de profundidade linear); virou uma linha clicável, igual o
  CALIBRAR.
- Rodapés de instrução (ex: "ENC2 GIRA VALOR") removidos das telas
  PAD_EDIT/AUTOTUNE — interface considerada simples o bastante sem eles.
- **Simulador do LCD + encoders removido do app desktop**
  (`HardwareSimulator.tsx`, `EncoderRemote.tsx`,
  `docs/06-simulador-hardware.md`, ~400 linhas de CSS) — não fazia mais
  sentido simular 2 encoders físicos que deixaram de existir. A
  configuração de pads (`PadEditor.tsx`/`PadGrid.tsx`) e o modo demo
  (`mockDevice.ts`) continuam intactos.
- Protocolo `enc_input` continua aceitando `enc: 1` ou `2` (compatibilidade
  com o app existente) — os dois caem no mesmo handler físico agora. Ver
  [01-decisoes-arquiteturais.md](01-decisoes-arquiteturais.md) (Fase Y)
  pro mapeamento completo.

## 2026-09-04 — Jackboard: pinos T/R corrigidos + rede de proteção por canal

- Esquemático da jackboard (`hardware/jackboard/`): jacks usavam TN/RN
  (contato normal/switched) como sinal por engano — corrigido pra T/R de
  verdade (Tip = canal par, Ring = canal ímpar), com TN/RN/S/SN todos em
  GND.
- Rede de proteção por canal adicionada (16x): resistor série 100Ω +
  resistor paralelo 100kΩ + diodo BAT85, mesma topologia do esquema de
  referência da HelloDrum-arduino-Library pro MUX.
- PCB: os 8 jacks recriados com a netlist corrigida e realinhados no
  passo físico de 22.5mm; os 48 componentes de proteção posicionados no
  espaço livre entre as duas colunas de pads de cada jack; cluster do MUX
  recentralizado sobre a fileira de jacks. Roteamento das trilhas fica
  pra uma próxima etapa — placa ainda não fabricada nem testada.
- Firmware: novo ambiente de teste isolado `test_hall`
  (`firmware/src/test_hall.cpp`) — mostra a leitura bruta do sensor hall
  (SS49E) na tela + Serial, sem MUX/encoders/USB-MIDI/BLE/EEPROM.

## 2026-09-02 — Fase X: calibração do controlador de pedal (HHC) — range + inversão

- **Novo assistente de captura de range** (`PAD_HIHAT_PEDAL`/
  `PAD_HIHAT_OPTICAL`, pad_type 6/7): diferente do resto (sensor de
  posição contínua, não de impacto) — pede pra segurar o pedal solto e
  depois pressionado até o fim, 3s cada, e calcula `threshold`/
  `sensitivity` (min/max) sozinho. Esses 2 campos já eram usados pela lib
  como os pontos de calibração do range (`curve()`/`map()` em
  `FSRSensing()`/`TCRT5000Sensing()`) — só nunca tinham um jeito
  automático de descobrir os valores certos.
- **Novo campo `hihat_invert`** (Sim/Não): alguns sensores mandam a
  posição invertida — liga isso pra corrigir. Aplicado no CC final
  (`127 - CC`), não no range calibrado — efeito imediato, sem precisar
  recalibrar. Novo array `padHihatInvert[]` + persistência EEPROM (mesmo
  padrão do `gain`, Fase P).
- Protocolo (`autotune_status` ganha `phase`/`hold_elapsed_ms`/
  `hold_target_ms`/`mode`, `set_pad` ganha `hihat_invert` — ver
  [04-protocolo-serial.md](04-protocolo-serial.md)), tela física e app
  desktop (checkbox dedicado "Inverter", mockups de LCD e modo demo)
  atualizados em conjunto. Ver
  [01-decisoes-arquiteturais.md](01-decisoes-arquiteturais.md) (Fase X)
  pro relato completo.
- **Nunca testado com hardware real** (nem o sensor físico, nem o
  assistente) — ver [05-tipos-de-sensor.md](05-tipos-de-sensor.md).

## 2026-09-02 — Fase W: auto-tune agora ignora o gain antigo do pad (calibra sempre "do zero")

- **Bug relatado**: em alguns pads, o nível FRACO da calibração não
  detectava as batidas. Causa: `rawValue[]` é um array global
  compartilhado entre `main.cpp` e a lib (`int rawValue[]` em
  `hellodrum.cpp`) — `applyPadGain()` (Fase P) escala ele usando o
  `gain` que o pad já tinha ANTES de `autoTuneTick()` ler o mesmo
  array. Se esse gain não estava neutro (100, ex: de uma calibração/
  ajuste manual anterior), a margem de segurança do piso de ruído
  (`atNoiseFloor*1.3 + 5`) tem um "+5" fixo que não escala junto — com
  gain baixo, uma batida fraca de verdade podia não superar esse piso.
- **Correção**: `startAutoTune()` agora salva o gain atual do pad
  (`atSavedGain`) e força `padGain[pad] = 100` (neutro) assim que a
  calibração começa — o assistente sempre parte "do zero", como pedido.
  Como `rawValue[]` é compartilhado, isso também neutraliza a sensing de
  verdade enquanto a calibração está rodando (consistente — os
  resultados calculados assumem gain neutro). Restaurado em
  `cancelAutoTune()`/`goToLive()` (ambos os únicos caminhos de saída sem
  aplicar, incluindo o "pânico" ENC1 hold → LIVE) se o usuário não
  aplicar; fica em 100 de propósito se aplicar
  (`applyAutoTuneResult()`), já que o resultado calculado só faz sentido
  combinado com gain neutro.
- Ver [01-decisoes-arquiteturais.md](01-decisoes-arquiteturais.md)
  (Fase W) pro relato completo.

## 2026-09-02 — Fase V: auto-tune estendido pra prato/caixa 3 zonas (edge + cup/aro)

- **Generalização da Fase U**: o assistente de auto-calibração agora
  também cobre `PAD_CYMBAL_3ZONE` (prato) e `PAD_SNARE_3ZONE` (caixa),
  não só `PAD_DUAL`. `cymbal3zoneSensing()` (`hellodrum.cpp`) discrimina
  zona por 2 FAIXAS de threshold no MESMO canal secundário (`edgeThreshold`/
  `cupThreshold`), diferente do `PAD_DUAL` (diferença entre 2 canais) —
  então esses pads fazem 2 rodadas extras (edge, depois cup/aro) em vez
  de 1, cada uma com os mesmos 3 níveis × 8 golpes.
- `bool atCalibrateSecondZone` virou `enum AutoTuneShape`
  (single/dual/tri), decidido por `pad_type` em `startAutoTune()`. Novo
  `atSumCupByTier[3]` acumula a rodada extra do cup/aro-forte.
  `edgeThreshold` sai da mesma margem de 30% usada em todo o assistente;
  `cupThreshold` sai de 30% do caminho entre o edge mais forte e o cup
  mais fraco observados, com salvaguarda contra faixas sobrepostas.
- **Nomenclatura de zona alinhada ao protocolo**: `autotune_status.zone`
  passou de nomes genéricos (`"primary"`/`"rim"`) pro MESMO vocabulário
  já usado no evento `hit`: `"head"`/`"rim"` (`PAD_DUAL`), `"bow"`/
  `"edge"`/`"cup"` (prato), `"head"`/`"edge"`/`"rim"` (caixa) — ver
  [04-protocolo-serial.md](04-protocolo-serial.md).
- App desktop: `protocol.ts` ganhou `autoTuneShapeFor()`/
  `autoTuneZonesFor()` como fonte única do mapeamento `pad_type` →
  sequência de zonas (evita reimplementar isso em 3 arquivos
  diferentes); rótulos de `rim_sensitivity`/`rim_threshold` no resultado
  agora vêm do mesmo lugar que os sliders (`PAD_TYPE_META`), não mais um
  texto fixo "aro". Ver [01-decisoes-arquiteturais.md](01-decisoes-arquiteturais.md)
  (Fase V) pro relato completo, incluindo a lógica de
  `cymbal3zoneSensing()` investigada antes de implementar.
- **Tradeoff aceito de antemão**: prato/caixa 3 zonas agora levam 72
  golpes pra calibrar (24 por zona × 3 zonas) em vez de 24.

## 2026-09-02 — Fase U: auto-tune passa a calibrar também o aro em pads de 2 zonas

- **Ideia do Rodrigo**: em pads `PAD_DUAL` (pele+aro), os 2 piezos sempre
  disparam juntos (bater na pele "vaza" pro aro e vice-versa), e a
  classificação de zona (`dualPiezoSensing()` em `hellodrum.cpp`) decide
  isso comparando os 2 picos do mesmo golpe — não olhando cada piezo
  isolado. O auto-tune (Fase O/T) nunca calibrava `rim_sensitivity`/
  `rim_threshold` (sempre manual), então essa comparação nunca tinha dado
  real por trás.
- **Nova 2ª passada**: pads `PAD_DUAL` agora repetem os 3 níveis inteiros
  (mais 24 golpes) batendo no ARO, depois da passada normal na pele —
  capturando os dois canais em paralelo nas duas rodadas (o que importa é
  a diferença entre eles, não cada um isolado). `rimThreshold` sai do
  pior vazamento visto no aro durante os golpes de pele; `rimSensitivity`
  sai do pior caso (maior diferença pele-aro) visto nos golpes reais de
  aro, com folga.
- **Fora de escopo por ora**: prato 2/3 zonas (mesmo tendo 2 canais
  físicos) usa uma lógica de discriminação diferente (faixa de threshold
  no mesmo canal, não diferença entre 2 canais) — não mexido.
- Protocolo (`autotune_status` ganha `zone`/`rim_sensitivity`/
  `rim_threshold` — ver [04-protocolo-serial.md](04-protocolo-serial.md)),
  tela física e app desktop (`PadEditor.tsx`, `mockDevice.ts`,
  `HardwareSimulator.tsx`) atualizados em conjunto. Ver
  [01-decisoes-arquiteturais.md](01-decisoes-arquiteturais.md) (Fase U)
  pro relato completo, incluindo a fórmula do resultado do aro.
- **Tradeoff aceito de antemão**: pads de aro agora levam 48 golpes pra
  calibrar (24 pele + 24 aro) em vez de 24.

## 2026-09-02 — Fase T: auto-tune corrigido (mesma inversão do ESP32 da Fase S) e evoluído pra 3 níveis de força

- **Bug encontrado**: `autoTuneTick()` (`firmware/src/main.cpp`) tinha
  sua própria cópia da fórmula de normalização do ESP32 que fora
  corrigida em `hellodrum.cpp` na Fase S — ainda invertida
  (`1023 - rawValue[atPad] / 4`). Era a causa do "auto-calibrar não
  funciona": o piso de ruído calculado ficava mais alto que qualquer
  pancada real, e o assistente sempre estourava o timeout de 15s.
  Corrigido pra `rawValue[atPad] / 4` (sem inversão).
- **Achado à parte**: pad 0 estava com `sensitivity`/`threshold`/
  `mask_time` zerados (resíduo de experimentação anterior), causando
  disparo constante e erros `map(): min == max`. Corrigido ao vivo via
  `set_pad` (sem reflash); adicionada uma salvaguarda em
  `HelloDrum::curve()` pra essa classe de config nunca mais travar/
  disparar sem parar.
- **Calibração em 3 níveis** (fraco/médio/forte, 8 golpes cada — 24 no
  total, antes eram 8 de intensidade livre): nível fraco calibra o
  `threshold`, nível forte calibra a `sensitivity`, nível médio serve só
  de checagem de consistência. Novo `atSumPeakByTier[3]` no lugar de um
  único acumulador. Atualizado em conjunto: tela física
  (`renderAutoTune()`), protocolo serial (`autotune_status` ganha
  `tier`/`tier_index`/`tier_count` — ver
  [04-protocolo-serial.md](04-protocolo-serial.md)), e o app desktop
  (`PadEditor.tsx`, `mockDevice.ts`, mockup de LCD em
  `HardwareSimulator.tsx`). Ver
  [01-decisoes-arquiteturais.md](01-decisoes-arquiteturais.md) (Fase T)
  pro relato completo, incluindo a fórmula do resultado.

## 2026-09-01 — Fase S (continuação): primeiro sensing real validado — fórmula do ESP32 estava invertida

- **Marco**: primeira leitura de piezo real, velocity-sensitive,
  confirmada de ponta a ponta neste projeto — testado com 2 piezos
  ligados direto em `GPIO17`/`GPIO18` (sem o MUX, que ainda não chegou),
  configurados como um pad dual-zone de teste (ver `TEST_DIRECT_HEAD_PIN`/
  `TEST_DIRECT_RIM_PIN` em `firmware/src/main.cpp`).
- **Bug encontrado**: `hellodrum.cpp` tinha, em 4 funções de sensing
  baseadas em piezo (`singlePiezoSensing`, `dualPiezoSensing`,
  `cymbal2zoneSensing`, `cymbal3zoneSensing`), uma fórmula só pra ESP32
  (`piezoValue = 1023 - piezoValue / 4`) que **invertia** a leitura —
  repouso virava "batida forte" e vice-versa. Confirmado contra os
  circuitos de referência oficiais da lib (piezo + resistor de 100 kΩ em
  paralelo, sem inversão nenhuma). Corrigido pra só normalizar 12→10 bits,
  sem inverter (`piezoValue = piezoValue / 4`). `TCRT5000Sensing`/
  `FSRSensing` (sensores ópticos/resistivos, tecnologia diferente) não
  foram mexidos - ficam pendentes de investigação própria.
- Depois da correção: cada batida gera um hit, zona certa ("head" em vez
  de sempre "rim"), velocidade variando de forma plausível com a força da
  batida. Ver [01-decisoes-arquiteturais.md](01-decisoes-arquiteturais.md)
  (Fase S) pro relato completo, incluindo os diagramas de referência
  consultados.
- Removido o `pinMode(..., INPUT_PULLUP)` usado no teste anterior (fio
  solto, sem resistor) — com o resistor de 100 kΩ de verdade instalado,
  pull-up interno não é necessário.

## 2026-09-01 — Fase S: causa raiz do bug do array `pads[]` (Fase Q) encontrada e corrigida

- **Marco**: leitura real por pad restaurada (`pads[i].begin(i, i+1)`,
  cada pad no seu próprio canal do MUX) — desde a Fase Q, todos os 32
  pads liam o mesmo canal (`begin(0,1)` constante) como contorno de um
  bug não identificado.
- **Causa raiz**: `hellodrum.cpp` (lib vendorizada) usa `#ifdef PULLUP`
  pra decidir se chama `pinMode(pin, INPUT_PULLUP)` dentro de `begin()` —
  uma flag que o autor original comentou por padrão
  (`//#define PULLUP`). O core arduino-esp32 já define seu próprio
  `PULLUP` (`0x04`, flag de modo do `pinMode()`) — `#ifdef` só olha se o
  nome existe, não quem definiu, então essa flag ficava **sempre ativa**
  no ESP32. `begin()` chamava `pinMode()` usando `pin1`/`pin2` como se
  fossem GPIOs reais, mas nesse projeto (MUX 2x CD4067) esses valores são
  índices de canal (0-31) — ao coincidir com um GPIO reservado
  internamente (flash/PSRAM), corrompia o sistema. Explica o padrão "ok
  até uns 26, quebra a partir de 27+" da Fase Q. Bug secundário
  encontrado no mesmo lugar: as funções de sensing também tinham
  `#ifdef PULLUP` invertendo a leitura do sensor — teria deixado a
  detecção de toque errada com sensores reais conectados. Ver
  [01-decisoes-arquiteturais.md](01-decisoes-arquiteturais.md) (Fase S)
  pro relato completo.
- Corrigido em `firmware/lib/HelloDrum-arduino-Library/src/hellodrum.cpp`
  — removidos os `pinMode()` de dentro de `begin()`, `#undef PULLUP`
  logo no topo do arquivo neutraliza o resto.
- `padEnabled[i] = false` continua forçado em todos os canais (não é
  mais sobre esse bug — é só porque os pads físicos ainda não estão
  conectados, e os canais ADC flutuando captariam ruído).
- BLE-MIDI confirmado anunciando certinho (visível num scanner BLE
  genérico) — o Windows MIDI Services ainda não tem transporte BLE-MIDI
  nativo; precisa de um app-ponte (ex. "BLE-MIDI Connect" na Microsoft
  Store). Não é um bug do firmware.

## 2026-09-01 — Fase R: USB-MIDI funcionando de verdade + tela em paisagem

- **Marco**: USB-MIDI reconhecido de verdade por uma DAW ("DRUMCORE"
  aparece em Active MIDI Inputs) — até então a porta nativa só enumerava
  como uma serial genérica, mesmo com o firmware "correto" segundo a API
  da Adafruit TinyUSB. Causa raiz: no ESP32,
  `Adafruit_USBD_Device::begin()` não religa o periférico USB de verdade
  (isso fica a cargo do core arduino-esp32, mas só acontece automaticamente
  se `CDC_ON_BOOT`/`MSC_ON_BOOT`/`DFU_ON_BOOT` estiverem ligados — nenhum
  estava). Corrigido religando o hardware manualmente em
  `bringUpNativeUsbHardware()` (`firmware/src/main.cpp`), replicando a
  sequência de baixo nível que a própria lib Adafruit deixa desligada de
  propósito nesse chip. Ver
  [01-decisoes-arquiteturais.md](01-decisoes-arquiteturais.md) (Fase R)
  pro histórico completo da investigação (incluindo uma primeira tentativa
  que travava o boot).
- Nomes USB/BLE unificados como "DRUMCORE" (fabricante, produto, porta
  MIDI, nome do dispositivo Bluetooth) + número de série USB fixo
  (`setSerialDescriptor`), antes nunca definido.
- BLE-MIDI ainda não confirmado funcionando do lado do host (não
  encontrado num scanner BLE) — investigação pausada pra focar no
  USB-MIDI primeiro.
- **Tela girada pra paisagem** (era retrato desde a Fase J, mas o painel
  físico real é 128x160, não 128x128 como a doc antiga assumia — sticker
  confirma "1.8' 128x160 RGB_TFT"). `tft.setRotation(1)`; barras de
  título/rodapé e a grade da tela LIVE redesenhadas pra usar a largura
  cheia da tela; lista de PADS também alargada.
- Removido o controle de brilho da tela (PWM no backlight não tinha
  efeito visível na faixa útil dessa placa clone — não valia a pena
  investigar mais fundo agora): backlight fica sempre ligado no máximo,
  sem dimming. Removido de `main.cpp`, do protocolo serial
  (`set_global`/`device_info`) e do app desktop.
- Coluna de tipo na lista de PADS trocada pra mostrar o nome configurado
  pelo pad (`label`), com `--` se vazio, em vez do tipo de sensor.
- Campo "ATIVO" na tela PAD_EDIT mostra "SIM"/"NAO" em vez de `1`/`0`.
- Novo comando de protocolo `enc_input` (`firmware/src/main.cpp` +
  `docs/04-protocolo-serial.md`) — encoder virtual via serial, chama os
  mesmos handlers dos encoders físicos. Novo componente
  `EncoderRemote.tsx` no app desktop, visível quando conectado ao
  hardware real — permite navegar a tela do módulo pelo app antes dos
  encoders físicos estarem conectados.

## 2026-08-31 — Fase Q: primeiro boot completo em hardware real (com contorno pendente)

- **Marco**: primeiro boot completo do firmware principal até `goToLive()`
  — tela renderizando, USB-MIDI e BLE-MIDI ativos, EEPROM funcionando,
  protocolo NDJSON emitindo eventos. Ver
  [01-decisoes-arquiteturais.md](01-decisoes-arquiteturais.md) (Fase Q)
  pro histórico completo da investigação.
- **Bug não resolvido**: o array `HelloDrum pads[32]` (inicializado com
  pinos sequenciais `0,1,2,...,31`, a forma original desde a Fase A)
  trava o boot com watchdog reset, sem causa raiz identificada apesar de
  investigação extensiva (isolamento por tamanho de array, por valor
  individual, por tempo, com/sem BLE — nada explicou o padrão observado).
  **Contorno em produção**: todos os 32 pads chamam `begin(0, 1)`
  (valores constantes) — desbloqueia o boot, mas todos os pads leem o
  mesmo canal do MUX (sem leitura real de sensor por pad ainda).
  **Pendente**: investigar a causa raiz e restaurar a leitura real
  (`begin(i, i+1)`) antes de conectar os pads/MUX físicos de verdade.
- Refatorado `HelloDrum` (biblioteca vendorizada) pra ter um construtor
  padrão trivial + método `begin(pin1[, pin2])` explícito, permitindo um
  array `pads[]` default (sem lista de inicializadores) inicializado
  dentro do `setup()` em vez de como array global — corrige um problema
  real e distinto (estouro de pilha da tarefa principal com arrays
  agregados de 27+ elementos não-triviais), mesmo esse não sendo a causa
  completa do bug acima.
- Novo ambiente de teste/regressão `test_pads` no `platformio.ini`
  (`firmware/src/test_pads.cpp`) — isola o array `pads[]` sem
  MUX/TFT/USB-MIDI/BLE/EEPROM, útil pra retomar a investigação depois.
- **Correção de um erro deste assistente**: `ARDUINO_USB_CDC_ON_BOOT=1`
  fazia o `app_main()` do core chamar `Serial.begin()` (USBCDC) antes do
  `setup()` do sketch, antes do `TinyUSBDevice.begin()` — travava
  esperando uma pilha TinyUSB que ainda não existia. Corrigido pra `0`.

## 2026-08-22 — Fase P: `Retrigger`, `Gain` e `Xtalk` (parâmetros do microDRUM)

- **`Retrigger`** (0-100, `0` = desligado): dentro do `mask_time`, uma
  pancada bem mais forte que a anterior pode "furar" o corte e disparar de
  novo — limiar decrescente com o tempo, evita perder golpes em rufos/
  rolls rápidos. **Única mudança de lógica de sensing já feita na lib
  vendorizada** — modificadas as 4 funções que fazem detecção de hit
  (`singlePiezoSensing`, `dualPiezoSensing`, `cymbal2zoneSensing`,
  `cymbal3zoneSensing`; HH/HH2zone já chamam essas mesmas 4 por dentro),
  porque a lógica de `mask_time` mora em variáveis privadas da lib.
  Comportamento original preservado exatamente quando `retrigger == 0`
  (default).
- **`Gain`** (10-200 = 0.10x-2.00x, 100 = neutro): recalibra a amplitude
  lida do sensor antes do threshold — sem tocar na lib, aplicado direto no
  `rawValue[]` em `main.cpp` com uma fórmula que preserva o "repouso" do
  sensor independente do multiplicador (`raw' = 4095 - gain*(4095-raw)`).
- **`Xtalk`/`Xtalk_group`** (0-100 / 0-4, `0` = desligado/sem grupo):
  suprime um hit se outro pad do mesmo grupo bateu bem mais forte no mesmo
  instante — cobre tanto vibração mecânica entre pads montados juntos
  quanto crosstalk elétrico entre canais (inclusive os 2 CD4067 que
  compartilham o barramento S0-S3). Também resolvido sem tocar na lib,
  rodando entre o `dispatchSensing()` e o `handlePadResult()`.
- Universais pros 9 tipos de pad — `MAX_FIELDS_PER_PAD` subiu de 13 pra 17.
  Persistem em EEPROM em blocos próprios (mesmo padrão do `enabled`, Fase
  N) — `retrigger` fica dentro do objeto `HelloDrum`, mas não é persistido
  pelo mecanismo próprio da lib.
- Validado: `pio run` compila e linka com sucesso (lib vendorizada
  modificada incluída); `npm run typecheck`/`npm run build` no app
  desktop, ambos limpos. **Nada testado em hardware real.**

## 2026-08-22 — Pesquisa: microDRUM/nanoDRUM (massimobernava/md-firmware)

- Explorado o código-fonte do firmware do microDRUM/nanoDRUM em busca de
  parâmetros de sensing que a nossa lib base (HelloDrum) não tem. Achados
  de maior valor: assistente de auto-calibração ("Auto Tune"), `Retrigger`
  (threshold decrescente durante o mask_time, evita perder golpes em
  rolls), `Gain` (multiplicador de calibração por canal), supressão de
  crosstalk entre multiplexadores/grupos de pads, choke de prato, e
  detecção de "foot splash"/"foot close" no pedal de chimbal por
  velocidade de fechamento. Implementado nessa mesma sessão: auto-tune
  (Fase O, ver abaixo). Os demais ficam como candidatos pra fases futuras.

## 2026-08-22 — Fase O: assistente de auto-calibração ("auto-tune")

- **Novo recurso**: bate no pad 8x e o firmware calcula sensibilidade,
  threshold, scan time e mask time sozinho — inspirado no "Auto Tune" do
  microDRUM/nanoDRUM, com um algoritmo próprio mais simples (1 fase de
  ruído de 2s + 8 golpes, em vez de ~50 golpes em 2 fases).
- **Firmware**: nova tela `PAGE_AUTOTUNE` (acessada pelo item `CALIBRAR`,
  sempre o último campo de qualquer pad em `PAD_EDIT`); só calibra o
  sensor principal do pad (pin_1) — pads de 2 canais continuam com ajuste
  manual pro 2º sensor. `MAX_FIELDS_PER_PAD` subiu de 12 pra 13.
- **Protocolo serial**: `start_autotune`/`cancel_autotune`/`apply_autotune`
  + evento `autotune_status` (progresso em tempo real, não só resposta a
  comando) — dá pra disparar/acompanhar tanto pela tela física quanto pelo
  app desktop.
- **App desktop**: painel de calibração no `PadEditor` (botão, progresso,
  aplicar/descartar); `mockDevice.ts` simula a sequência inteira com
  temporizadores; `HardwareSimulator.tsx` replica a mesma tela/fluxo.
- Validado: `pio run` compila e linka com sucesso; `npm run typecheck` e
  `npm run build` no app desktop, ambos limpos. **Nada testado em
  hardware real** — os fatores de margem usados no cálculo (+15%/+20%/
  +30%) são estimativas, não calibrados contra um piezo real.

## 2026-08-22 — Fase N: canal habilitado/desabilitado por pad (ruído em slot vazio)

- **Novo campo `enabled` por pad** (protocolo + `padEnabled[]` no
  firmware, persistido em EEPROM): canal desligado é completamente
  ignorado (`dispatchSensing()`/`handlePadResult()` nunca rodam pra ele) —
  resolve slots sem sensor físico conectado captando ruído/interferência e
  gerando `hit`/nota MIDI fantasma. Não resolve ruído em canal que
  **tem** sensor conectado (isso é hardware — resistor de sangramento).
- **Tela/encoders**: novo campo `ATIVO` (universal, 2º campo de todo tipo
  de pad em `PAD_EDIT`). Canal desligado aparece apagado na tela LIVE
  (grid) e como "OFF" na tela PADS — visível, não escondido.
- **App desktop**: checkbox "Canal ativo" no `PadEditor`, lista de pads
  (`PadGrid`) mostra linha esmaecida com "desligado"; `HardwareSimulator`
  replica a mesma UX (item ATIVO, grid e lista com o mesmo tratamento).
- Documentação: `docs/04-protocolo-serial.md` (campo `enabled`),
  `docs/01-decisoes-arquiteturais.md` (Fase N completa, incluindo o
  esclarecimento de que isso não substitui resistor de sangramento em
  sensores conectados).
- Validado: `pio run` compila e linka com sucesso; `npm run typecheck` e
  `npm run build` no app desktop, ambos limpos. **Nada testado em
  hardware real.**

## 2026-08-22 — Fase M: tipo de sensor "Caixa 3 zonas" + bugfix crítico do `PAD_DUAL`

- **Novo tipo de sensor `PAD_SNARE_3ZONE` (8)**: caixa com 3 sons (centro
  da pele, borda da pele, aro/rimshot) — reusa a mesma sensing do prato 3
  zonas (`cymbal3zoneMUX()`), sem mudanças na lib vendorizada, só com
  zonas renomeadas (`head`/`edge`/`rim`). Cabeamento idêntico ao tipo 1
  (Aro/Dual): pele + aro, 2 piezos.
- **Bug corrigido (crítico)**: `handlePadResult()` nunca teve um `case
  PAD_DUAL:` desde a Fase G — qualquer pad configurado como tipo 1
  (Aro/Dual, o tipo mais comum pra caixa) **nunca enviava nota MIDI
  nenhuma** ao ser atingido, apesar da detecção de hit funcionar
  normalmente. Corrigido usando as zonas `head`/`rim` já documentadas em
  [04-protocolo-serial.md](04-protocolo-serial.md) e simuladas em
  `mockDevice.ts`.
- App desktop: `protocol.ts` (`PAD_TYPE_META[8]`), modo demo
  (`mockDevice.ts`) e simulador de hardware (`HardwareSimulator.tsx`,
  pad "Caixa" de exemplo agora usa o tipo 8) atualizados.
- Documentação: `docs/05-tipos-de-sensor.md` (novo tipo 8 detalhado, nota
  sobre o bugfix), `docs/04-protocolo-serial.md` (`pad_type` 0-7→0-8),
  `docs/01-decisoes-arquiteturais.md` (Fase M completa).
- Validado: `pio run` compila e linka com sucesso; `npm run typecheck` e
  `npm run build` no app desktop, ambos limpos. **Nada testado em
  hardware real** — threshold de borda/aro do tipo 8 nunca foi calibrado
  numa caixa física.

## 2026-08-21 — Fase L (refinamento): pinos fisicamente contíguos, não só "mesmo header"

- **Firmware** (`firmware/src/main.cpp`): MUX (S0-S3, SIG0/SIG1) passa a
  usar GPIO4,5,6,7,15,16 — a única sequência de 6 pinos fisicamente
  contígua no header esquerdo (antes: SIG0/SIG1 em GPIO8/9, no mesmo
  header mas distantes de S0-S3 na ordem física real da placa). TFT passa
  a usar GPIO17,18,8,9,10,11 (continuação imediata da sequência do MUX).
  Encoders sem mudança (já eram contíguos).
- **Trade-off aceito**: GPIO15/16 (SIG0/SIG1) são ADC2, não ADC1 — a
  restrição "só ADC1" das fases anteriores existia por precaução com o
  conflito clássico ADC2×Wi-Fi, que não se aplica aqui porque o projeto
  nunca inicializa Wi-Fi (só BLE-MIDI). Ver
  [01-decisoes-arquiteturais.md](01-decisoes-arquiteturais.md) (adendo na
  entrada da Fase L).
- Documentação (`docs/02-hardware.md`) e esquemático visual
  (`docs/assets/esquematico-hellodrum.html`) atualizados com os novos
  números de GPIO.
- Validado: `pio run` compila e linka com sucesso. **Nada testado em
  hardware real.**

## 2026-08-21 — Fase L: pinout reorganizado por ergonomia de montagem

- **Hardware**: pinout reatribuído a partir de uma foto real da placa
  comprada (dev board ESP32-S3, headers de 22 pinos de cada lado) — cada
  subsistema (2x CD4067, tela TFT, cada encoder) agora sai inteiro de um
  único header físico, sem fios cruzando a placa. Header esquerdo (único
  lado com `3V3`): MUX + tela. Header direito (só `GND`, suficiente pros
  encoders que usam pull-up interno): os 2 encoders.
- **Firmware** (`firmware/src/main.cpp`): `MUX0_Z`/`MUX1_Z` GPIO1/2→8/9;
  `TFT_DC` GPIO9→10; `TFT_CS` GPIO10→16; `ENC1_A/B/SW` GPIO15/16/17→
  42/41/40; `ENC2_A/B/SW` GPIO18/21/38→37/36/35.
- **Achado incidental**: GPIO38 (usado até então pro SW do encoder 2)
  aciona um LED embutido dessa placa específica — evitado. (Correção
  2026-08-31: o rótulo real, conferido na serigrafia, é `BUILTIN LED`, não
  `RGB_LED` — o LED RGB endereçável fica no GPIO48, já excluído por outro
  motivo. Ver [01-decisoes-arquiteturais.md](01-decisoes-arquiteturais.md).)

## 2026-08-31 — Ajuste de contiguidade física dos encoders

- **Firmware** (`firmware/src/main.cpp`): `ENC1_A/B/SW` GPIO42/41/40→
  **1/2/42**; `ENC2_A/B/SW` GPIO37/36/35→**41/40/39**. Corrige um vão de 2
  pinos (`GPIO39`, `GPIO38`) que sobrava entre os dois encoders na
  atribuição da Fase L — agora os 6 sinais saem contíguos na ordem física
  real do header direito (`GPIO1,2,42,41,40,39`), sem pular nenhum outro
  pino. Como efeito colateral, deixa de usar GPIO35-37 (risco de PSRAM
  octal) e não toca em GPIO43/44 (UART/USB-serial de debug). Ver
  [01-decisoes-arquiteturais.md](01-decisoes-arquiteturais.md).
- **Módulo confirmado como ESP32-S3-N16R8** (16MB flash + 8MB PSRAM octal,
  lido na serigrafia por Rodrigo) — corrige uma afirmação anterior errada
  deste assistente (que tinha confundido o perfil genérico de build com
  detecção de hardware real). `firmware/platformio.ini` ajustado pra
  refletir o módulo: `board_build.arduino.memory_type = qio_opi`,
  `board_build.partitions = default_16MB.csv`, `board_upload.flash_size =
  16MB`, `build_flags += -D BOARD_HAS_PSRAM`. `pio run` confirma
  `[SUCCESS]` com `16MB Flash`.
- **Tela TFT remapeada pra espelhar o próprio conector** (`GND VCC SCL
  SDA RES DC CS BLK`): passa da sequência logo após o MUX
  (`GPIO17,18,8,9,10,11`) para os 6 pinos da base do header esquerdo,
  logo acima do `GND` (`GPIO9,10,11,12,13,14`) — `TFT_SCLK` GPIO9→**14**,
  `TFT_MOSI` GPIO8→**13**, `TFT_RST` GPIO11→**12**, `TFT_DC` GPIO17→**11**,
  `TFT_CS` GPIO18→**10**, `TFT_BLK` GPIO10→**9**. Como o `GND` do header
  esquerdo fica na base (e o `3V3` no topo), subir a partir do `GND` casa
  cada sinal com a ordem física do conector da tela, sem cruzar fios — só
  o `VCC` precisa de um fio isolado até o `3V3` no topo. Deixa de formar
  um feixe único com o MUX (sobram GPIO17/18/8 livres) — trade-off aceito
  de propósito. Ver [01-decisoes-arquiteturais.md](01-decisoes-arquiteturais.md).
- **Risco anotado, não confirmado**: GPIO35-37 (usados pelos encoders)
  são internos em módulos ESP32-S3 com PSRAM octal — a placa expõe eles
  como header normal, sugerindo que não é essa variante, mas vale
  confirmar contra o código impresso no módulo antes de soldar. Ver
  [01-decisoes-arquiteturais.md](01-decisoes-arquiteturais.md) (Fase L).
- Documentação (`docs/02-hardware.md`, `01-decisoes-arquiteturais.md`) e
  esquemático visual (`docs/assets/esquematico-hellodrum.html`)
  atualizados pra mostrar de qual header cada fio sai.
- Validado: `pio run` compila e linka com sucesso. **Nada testado em
  hardware real.**

## 2026-08-31 — Primeiro teste em hardware real: tela funcionando

- **Marco**: primeira gravação e teste do firmware num ESP32-S3 físico
  (porta `COM5`/CH343, ver notas de porta USB/UART em
  [01-decisoes-arquiteturais.md](01-decisoes-arquiteturais.md)).
- Tela ficou em branco na primeira gravação (backlight ok, sem conteúdo).
  Investigado com um ambiente de teste isolado
  (`[env:display_test]`/`firmware/src/test_display.cpp`, novo, permanente
  no repo) que descartou variante de driver errada e interferência do
  resto do firmware como causas. **Causa raiz**: curto físico na solda de
  um dos pinos da tela — corrigido por Rodrigo. Depois da correção, a
  tela mostrou as cores do teste corretamente, e o firmware principal
  (`tft.initR(INITR_144GREENTAB)`) foi regravado com sucesso. Ver
  [01-decisoes-arquiteturais.md](01-decisoes-arquiteturais.md) pro
  diagnóstico completo passo a passo.

## 2026-08-21 — Fase K: multiplexação trocada pra 2x CD4067 (HW-178)

- **Hardware**: substituídas as 4x CD4051 (8 canais cada) por 2x módulos
  breakout HW-178 (chip CD4067, 16 canais cada) — mesmas 32 entradas, menos
  placas pra montar. O usuário já comprou as 2 unidades.
- **Firmware** (`firmware/src/main.cpp`): troca de `HelloDrumMUX_4051` por
  `HelloDrumMUX_4067` (2 instâncias em vez de 4). Adicionado `MUX_S3`
  (GPIO7, reaproveitando o antigo pino Z do 3º CD4051); os pinos `SIG` dos 2
  MUX continuam nos GPIOs 1 e 2. Nenhuma mudança em `pads[]`, EEPROM,
  protocolo serial ou telas — a indexação de pad (0-31) sempre foi
  independente de quantos chips físicos formam o espaço de canais.
- **Documentação**: `docs/02-hardware.md` (pinout/componentes),
  `docs/03-biblioteca-hellodrum.md` (fórmula de índice do MUX),
  `docs/01-decisoes-arquiteturais.md` (nova entrada "Fase K" com o racional
  completo, incluindo a fiação do pino EN do HW-178) e o esquemático visual
  (`docs/assets/esquematico-hellodrum.html`) atualizados.
- Validado: `pio run` compila e linka com sucesso. **Nada testado em
  hardware real.**

## 2026-08-21 — Fase J: rebranding + redesenho da UI do firmware

- **Renomeação do projeto**: "HelloDrum" → "DrumCore" (nome de exibição
  "DRUMCORE" em telas/branding, "DrumCore" em prosa). A biblioteca de
  terceiros vendorizada (`firmware/lib/HelloDrum-arduino-Library`, de Ryo
  Kosaka) mantém seu nome original — não faz parte do rebranding.
- **Redesenho completo da tela/navegação do firmware**
  (`firmware/src/main.cpp`), seguindo uma especificação de UI produzida com
  Claude Design (`design/SPEC.md`). Substitui o sistema de botões/tela das
  Fases C/I por 6 telas: BOOT, LIVE (grade 8x4 dos 32 pads, com flash ao
  bater), PADS (lista rolável dos 32 pads), PAD_EDIT (edição dos parâmetros
  do pad em foco, lista de campos dinâmica por tipo de sensor), SIGNAL
  (osciloscópio simplificado do envelope do sensor) e GLOBAL (canal MIDI,
  saída MIDI, brilho da tela via PWM, e ações SALVAR/RESTAURAR com toast —
  sem "KIT", ver abaixo).
- **Dois encoders com semântica nova**: ENC1 navega entre páginas/pad em
  foco (clique alterna PAD_EDIT↔SIGNAL, hold de 600ms volta pra LIVE); ENC2
  navega a lista/edita o valor em foco (clique confirma, hold de 600ms volta
  um nível). Ambos com aceleração de valor (>8 giros/s pula de passo 1 pra
  5).
- **Mudança de modelo de persistência**: editar um pad pelos
  encoders/tela agora só altera um buffer em RAM — só grava na EEPROM
  quando o usuário confirma GLOBAL > SALVAR (GLOBAL > RESTAURAR descarta as
  mudanças não salvas, recarregando da EEPROM). Diverge intencionalmente do
  caminho do protocolo serial (usado pelo app desktop), que continua
  salvando cada campo imediatamente ao mudar — o app desktop não tem um
  botão "salvar" equivalente.
- Como o hardware não tem circuito de MIDI DIN (5 pinos), a opção "SAIDA"
  da tela GLOBAL (que na especificação original previa USB/DIN/USB+DIN) foi
  adaptada pra USB/BLE/USB+BLE, os dois transportes que o projeto de fato
  tem (USB-MIDI da Fase B e BLE-MIDI da Fase H).
- O campo "KIT" do spec original **não foi implementado**, nem como
  placeholder — o usuário pediu explicitamente pra não implementar por
  enquanto. Não existe em nenhuma camada (firmware, protocolo serial, app
  desktop, simulador). Ver [01-decisoes-arquiteturais.md](01-decisoes-arquiteturais.md).
- **Correção de linkage na lib vendorizada**: o array `rawValue[]`
  (`hellodrum.h`/`hellodrum.cpp`) era `static` no header, causando uma cópia
  isolada por arquivo `.cpp` (linkage interno). Trocado para `extern` no
  header + definição única no `.cpp`, permitindo que `main.cpp` leia os
  valores brutos do ADC pra desenhar a tela SIGNAL.
- **Reskin visual completo do app desktop** (Electron/React), seguindo a
  mesma paleta e tipografia da tela do módulo (tokens de cor BG/SURFACE/
  LINE/TXT_DIM/TXT/ACCENT/EDIT/HIT/OK; fontes Silkscreen + Space Grotesk via
  Google Fonts). API exposta pelo preload do Electron renomeada de
  `window.helloDrum` para `window.drumCore`. Nova aba "Global" no app
  desktop pra configurar canal MIDI/saída/brilho. `HardwareSimulator.tsx`
  reescrito do zero pra espelhar a nova máquina de estados de 5 páginas e a
  nova semântica dos dois encoders, incluindo o gesto de "hold" de 600ms
  (simulado via mouse down/up no navegador).
- Validado: compilação do firmware via PlatformIO (`pio run`, sucesso) e
  `npm run typecheck` + `npm run build` no app desktop (ambos limpos).

## 2026-08-20 (15) — bugfix

- **Corrigido**: sliders do editor de pad (app desktop) não refletiam a
  mudança - arrastar e soltar fazia o valor "voltar" pro que era antes.
  Causa: `set_pad` em campos numéricos responde com `ack` (não
  `pad_config`), e `App.tsx` só registrava o `ack` no log, nunca atualizava
  o estado local `pads` — como o slider é um input controlado ligado a
  esse estado, ele sempre reexibia o valor antigo. Corrigido aplicando o
  `ack` (`pad`/`field`/`value`) no estado local também. Afeta tanto o modo
  demo quanto o módulo real (bug era só no app, não no protocolo/firmware).

## 2026-08-20 (14)

- **Fase I**: tela inicial (grid 8x4 com o número de cada pad, acende verde
  ao ser atingido) que aparece após 4s ocioso e dá lugar à tela de
  configuração assim que qualquer encoder é usado. A tela de configuração
  ganhou um velocímetro (arco + agulha) mostrando onde o valor atual do
  parâmetro cai entre o mínimo e o máximo.
- Grid mapeado 1:1 com a fiação real: linha = MUX físico (0-3), coluna =
  canal dentro do MUX (0-7).
- Velocímetro desenhado via trigonometria (`drawGauge()`), já que a
  Adafruit GFX não tem desenho de arco nativo; faixa min/max de cada
  parâmetro inferida por substring no rótulo (`getGaugeRange()`), já que a
  lib não expõe isso estruturado.
- Simulador do módulo (`HardwareSimulator.tsx`) atualizado com os mesmos
  dois estados — grid com hits simulados periodicamente, velocímetro via
  SVG — usando as mesmas constantes de tempo do firmware
  (`IDLE_TIMEOUT_MS`, `PAD_FLASH_MS`).
- Build/typecheck do firmware e do app validados. **Nada testado em
  hardware real** — em especial a legibilidade do velocímetro na tela
  física de 1.44" ainda precisa de confirmação. Detalhes em
  [01-decisoes-arquiteturais.md](01-decisoes-arquiteturais.md).

## 2026-08-20 (13)

- **Fase H**: BLE-MIDI (`lathoub/Arduino-BLE-MIDI`, stack Bluedroid já
  embutida no core) como transporte adicional — todo hit/CC vai tanto pro
  USB-MIDI quanto pro BLE-MIDI simultaneamente (não é um "modo" a escolher;
  o BLE só efetivamente transmite quando há um dispositivo pareado).
  Confirmei a API lendo os próprios exemplos vendorizados da HelloDrum-lib
  (`examples/BLE/`, `examples/MUX/muxSensing_BLEMIDI`) e o código-fonte da
  lib BLE-MIDI direto do GitHub antes de implementar.
- Nome anunciado via Bluetooth: `"DrumCore"`. Instância nomeada `BleMidi`
  (em vez do nome padrão `MIDI` que a lib usaria, que colidiria com o `MIDI`
  já usado pro USB).
- `device_info` ganhou o campo `ble_connected`; o firmware reenvia
  `device_info` automaticamente a cada pareamento/desconexão BLE, sem o app
  precisar dar poll. App desktop: indicador "BLE ●/○" na barra superior,
  modo demo simula pareamento/desconexão periódicos pra exercitar a UI.
- Consumo de recursos antes/depois: RAM 11.9%→19.8%, Flash 10.9%→30.0% (a
  stack Bluedroid é pesada em flash, mas ainda com bastante margem no board
  N8 de 8MB). Build validado, nenhum warning novo.
- **Nada testado em hardware real** — essa fase é mais especulativa que as
  anteriores: compilar não garante que USB-MIDI e BLE-MIDI realmente
  coexistem em runtime sem briga de stack, nem que o pareamento (a lib usa
  bonding BLE) funciona de primeira em iOS/Android/Windows. Detalhes em
  [01-decisoes-arquiteturais.md](01-decisoes-arquiteturais.md).

## 2026-08-20 (12)

- Criado esquemático visual de ligação (ESP32-S3 ↔ 4x CD4051 ↔ tela TFT ↔ 2
  encoders), reunindo o pinout já documentado num diagrama único. Salvo em
  [docs/assets/esquematico-hellodrum.html](assets/esquematico-hellodrum.html)
  e também publicado como artifact. Inclui notas de montagem que ainda não
  estavam explícitas (VDD/VSS/INH do CD4051, pull-up interno dos encoders).

## 2026-08-20 (11)

- **Simulador do módulo** (nova aba no app desktop): recria a tela TFT
  128x128 + navegação pelos 2 encoders rotativos, pra testar a UX da
  configuração via hardware antes da tela/encoders físicos chegarem.
  Reproduz fielmente a máquina de estados do firmware (navegação de pad/item,
  modo de edição, encoder 2 desabilitado durante edição, mensagem "Canal
  ocupado") - removido do app desktop em 2026-09-04 (Fase Y, ver mais abaixo),
  quando o hardware passou a ter 1 encoder só.
- Controle por scroll do mouse nos "encoders" na tela, ou por teclado
  (setas + Enter/Espaço) - dataset de 32 pads local com uma mistura de
  tipos pra dar um "tour" pelas telas possíveis sem precisar configurar
  nada primeiro.
- Build/typecheck validados.

## 2026-08-20 (10)

- App desktop: lista de pads trocada de um grid de botões grandes pra uma
  lista compacta (uma linha por pad — número, nome/"Sem nome", nota),
  ocupando uma coluna fixa mais estreita à esquerda, deixando mais espaço
  pro editor do pad. Ajuste de UI, sem mudança de protocolo/firmware.

## 2026-08-20 (9)

- **Fase G**: os 8 tipos de sensor documentados pela HelloDrum-lib (simples,
  aro/dual, chimbal simples, prato 2 zonas, chimbal 2 zonas, prato 3 zonas,
  pedal FSR/VH-10/VH-11, pedal óptico TCRT5000), com a topologia de canais
  (tipo de cada canal, e quais 2 canais formam um pad de 2 zonas)
  configurável em runtime só pelo app desktop, persistida em EEPROM.
  Detalhamento completo em [05-tipos-de-sensor.md](05-tipos-de-sensor.md).
- Confirmado lendo o código-fonte: **nenhum tipo de sensor dessa lib usa mais
  de 2 canais** — inclusive o prato de 3 zonas (a 3ª zona/cup é o mesmo canal
  do switch de borda, discriminado por um threshold mais alto).
- Firmware: todos os 32 pads passaram a ser construídos com 2 pinos desde o
  boot (`HelloDrum(i, i+1)`) pra permitir trocar o tipo de um pad em runtime
  sem reconstruir objetos C++ — só troca qual método de sensing é chamado.
  Canais consumidos por um pad de 2 canais ficam sem configuração própria
  (`"primary": false` no protocolo). Chimbal (prato/simples) e pedal de
  chimbal são pads separados, linkáveis via `hihat_pedal_channel` (a lib não
  faz essa ligação automaticamente). Detalhes e limitações herdadas da lib
  (só 3 slots de nota independentes) em
  [01-decisoes-arquiteturais.md](01-decisoes-arquiteturais.md).
- Protocolo (`04-protocolo-serial.md`) estendido: `set_pad` ganhou os campos
  `rim_sensitivity`, `rim_threshold`, `note_rim`, `note_cup`, `pad_type` e
  `hihat_pedal_channel`; `pad_config` ganhou `primary`/`consumed_by`; `hit`
  ganhou `zone`.
- App desktop: seletor de tipo de sensor por pad, campos condicionais por
  tipo (só mostra o que faz sentido), seletor de pedal linkado pros tipos de
  chimbal, e exibição diferenciada pra canais consumidos no grid e no editor.
  Modo demo simula a mesma lógica (incluindo consumo de canal e simulação de
  hits por zona).
- Build/typecheck do firmware e do app validados. **Nada testado em
  hardware real** — em especial a faixa de `pedalCC` e o comportamento real
  de `HH2zoneMUX()` num chimbal físico.

## 2026-08-20 (8)

- **Fase F**: nome livre por pad (ex: "Caixa"), editável só pelo app
  desktop. Número do pad fixo — nome exibido sempre `"N - label"` (ou
  `"Pad N"` sem label), na tela TFT e no app.
- Firmware: `padLabels`/`padNames` em `main.cpp`, persistidos em EEPROM
  (layout estendido). Protocolo `set_pad` ganhou o campo `label` (string),
  reaproveitando o comando existente em vez de criar um novo. Detalhes em
  [01-decisoes-arquiteturais.md](01-decisoes-arquiteturais.md) e
  [04-protocolo-serial.md](04-protocolo-serial.md).
- App desktop: campo de texto no editor do pad (com o número fixo ao lado),
  commit ao sair do campo ou apertar Enter. Modo demo atualizado pra
  simular o mesmo comportamento.
- Build/typecheck do firmware e do app validados. Nada testado em hardware
  real ainda.

## 2026-08-20 (7)

- Iniciada a **interface desktop** (item 4 do escopo original) em
  `desktop-app/` — Electron + React + TypeScript, build via `electron-vite`.
  Decisões (stack e protocolo) perguntadas diretamente ao usuário. Detalhes
  em [01-decisoes-arquiteturais.md](01-decisoes-arquiteturais.md).
- **Fase E do firmware**: protocolo serial NDJSON sobre a porta USB-CDC
  (`bblanchon/ArduinoJson`). Todo o tráfego Serial passou a ser JSON (uma
  linha por objeto) — inclusive os eventos de hit e logs de boot, que antes
  eram texto livre. Contrato completo documentado em
  [04-protocolo-serial.md](04-protocolo-serial.md).
- App desktop implementado: tela de conexão (lista/seleciona porta serial),
  grid dos 32 pads, editor de parâmetros (sliders), log de eventos. Inclui
  **"modo demo"** — simula o módulo inteiramente no processo renderer
  (`mockDevice.ts`), sem precisar de porta serial nem hardware, útil pra
  validar/demonstrar a UI antes da bancada estar montada.
- Corrigidas vulnerabilidades de dependências encontradas no scaffold inicial
  (Electron e esbuild/vite desatualizados) antes de seguir — atualizado para
  `electron@^43`, `vite@^7`, `0` vulnerabilidades no `npm audit`.
- Validado: `npm run typecheck` e `npm run build` (main+preload+renderer)
  passam limpo. Firmware da Fase E compila (RAM/Flash sem mudança
  significativa). **Nada testado com o módulo real** — sem hardware montado,
  só o modo demo do app foi exercitado (e mesmo assim só via build, não
  `npm run dev` de fato nesta sessão).

## 2026-08-20 (6)

- Implementada a **Fase D**: persistência das configurações em EEPROM (NVS).
  `firmware/src/main.cpp` agora chama `EEPROM_ESP.begin()` no `setup()` e usa
  um byte de flag ("já inicializado", endereço `NUM_PADS*10`) pra decidir
  entre `initMemory()` (primeiro boot, grava os defaults) ou `loadMemory()`
  (demais boots, restaura o que foi salvo/editado via os encoders).
- **Bug real encontrado e corrigido na lib vendorizada**: no branch de
  incremento (UP) do item SENSITIVITY, o endereço de EEPROM usado era
  `padNum * 8` em vez de `padNum * 10` (usado por todo o resto do código) —
  gravava por cima de dados de **outro** pad para qualquer `padNum >= 1`.
  Corrigido nas duas variantes (ESP32/AVR) em `hellodrum.cpp`. Só apareceu
  agora porque é a primeira fase em que a EEPROM foi de fato ativada — antes
  as escritas eram no-ops silenciosos. Detalhes em
  [01-decisoes-arquiteturais.md](01-decisoes-arquiteturais.md) e
  [03-biblioteca-hellodrum.md](03-biblioteca-hellodrum.md).
- Build validado (compila e linka, RAM 11.4%, Flash 10.4%). **Teste em
  hardware real ainda pendente** — não há como simular reboot com NVS real
  sem a placa física, então a persistência de fato ainda não foi confirmada.

## 2026-08-20 (5)

- Implementada a **Fase C**: tela TFT (ST7735, `Adafruit GFX` + `Adafruit
  ST7735 and ST7789 Library`) e navegação/edição via **2 encoders rotativos
  com chave** (lib `mathertel/RotaryEncoder`), em vez dos 5 botões discretos
  originalmente previstos.
- `firmware/src/main.cpp`: os encoders alimentam
  `HelloDrumButton::readButton(set, up, down, next, back)` diretamente (sem
  modificar a lib), e a tela mostra pad/item/valor atuais, com flash
  transiente "EDITAR"/"OK" ao entrar/sair do modo de edição.
- Pinout proposto para tela e encoders em [02-hardware.md](02-hardware.md).
- **Bug/pegadinha encontrada e corrigida**: `settingName()` precisa ser
  chamado uma vez por pad no `setup()` (incrementa `nameIndexMax`, que limita
  a navegação entre pads) e precisa apontar para um buffer estático/global
  (não temporário) já que guarda o ponteiro recebido, não uma cópia. Detalhes
  em [01-decisoes-arquiteturais.md](01-decisoes-arquiteturais.md).
- Build validado (compila e linka, RAM 11.4%, Flash 10.1%). **Ainda não
  testado em hardware real** — falta confirmar sentido de giro dos encoders,
  `LatchMode`, e a inicialização/cores da tela (`INITR_144GREENTAB`).
- Edições feitas via os encoders ainda **não persistem** (sem EEPROM ativada
  nesta fase, de propósito — habilitar `EEPROM_ESP.begin()` sem também
  implementar `initMemory()` no primeiro boot deixaria sensibilidade/threshold
  zerados e sensing instável). Persistência fica para uma fase futura.

## 2026-08-20 (4)

- **Mudança de hardware**: tela definida como TFT 1.44" 128x128, driver ST7735S
  (SPI), em vez do OLED SSD1306 (I2C) previsto inicialmente — modelo escolhido
  pelo usuário por preço (foto em `Modelo Tela.jpeg` na raiz do projeto).
- Atualizado pinout proposto em [02-hardware.md](02-hardware.md) para os 6
  sinais SPI da tela (SCK, MOSI, RES, DC, CS, BLK), sem conflito com os pinos
  já usados pelos 4x CD4051.
- Decisão de biblioteca registrada em
  [01-decisoes-arquiteturais.md](01-decisoes-arquiteturais.md): Adafruit GFX +
  Adafruit ST7735 Library (em vez de u8g2, que é focada em displays
  monocromáticos, ou TFT_eSPI, que exige mais configuração). Ainda não
  implementado no firmware — só a decisão e o pinout.

## 2026-08-20 (3)

- Implementada a **Fase B**: USB-MIDI nativo. `firmware/src/main.cpp` agora
  envia `MIDI.sendNoteOn/sendNoteOff` via `Adafruit_USBD_MIDI` (transporte USB
  nativo/TinyUSB) sempre que um pad é atingido, usando notas de teste
  consecutivas (36 a 67) só para identificar cada canal no DAW.
- `firmware/platformio.ini`: adicionado `ARDUINO_USB_MODE=0` (modo TinyUSB/OTG,
  confirmado no `boards.txt` do core `arduino-esp32` instalado — o padrão do
  board é `ARDUINO_USB_MODE=1`, modo Hardware-CDC, que não suporta classes USB
  customizadas), `ARDUINO_USB_CDC_ON_BOOT=1` (mantém Serial via CDC) e
  `lib_deps` (`Adafruit TinyUSB Library`, `FortySevenEffects/MIDI Library`).
- **Problema de linker encontrado e contornado**: o core `arduino-esp32` 3.x já
  embute sua própria TinyUSB pré-compilada, conflitando (símbolos duplicados)
  com a TinyUSB que a lib Adafruit compila do próprio código-fonte. Resolvido
  com `-Wl,--allow-multiple-definition`. Detalhes em
  [01-decisoes-arquiteturais.md](01-decisoes-arquiteturais.md).
- Build validado com sucesso (RAM 11.1%, Flash 9.5% no `esp32-s3-devkitc-1`).
  **Ainda não testado em hardware real** — falta confirmar que o módulo
  enumera como dispositivo USB-MIDI de fato e que o Serial (CDC) continua
  funcionando junto (dispositivo composto).

## 2026-08-20 (2)

- Implementada a **Fase A**: firmware básico (`firmware/src/main.cpp`) que
  instancia 4x `HelloDrumMUX_4051` + 32x `HelloDrum` e reporta hits via Serial
  (sensibilidade/threshold padrão da lib, sem MIDI/OLED/botões ainda).
- Definido pinout proposto para o ESP32-S3 (S0/S1/S2 compartilhados + 4 pinos
  ADC1 dedicados, evitando strapping pins e os pinos do USB nativo). Ver
  [02-hardware.md](02-hardware.md).
- **Bug encontrado e corrigido na lib vendorizada**: `padType[16]` e
  `showInstrument[]` (16 entradas) são indexados por `padNum`/`nameIndex`, que
  vão até 31 com 32 pads — causaria overflow de memória a partir do pad 17.
  Ambos ampliados para 32. Detalhes em
  [03-biblioteca-hellodrum.md](03-biblioteca-hellodrum.md).
- PlatformIO CLI instalado (`pip install --user platformio`) e build validado:
  compila com sucesso para `esp32-s3-devkitc-1` (RAM 7.0%, Flash 8.7%). Ainda
  **não testado em hardware real** — o hardware com os 4x CD4051 ainda não foi
  montado, então a lógica de sensing em si não foi validada com sinais reais,
  só a compilação/estrutura do código.

## 2026-08-20

- Estruturação inicial do projeto: repositório Git criado, pastas `docs/`,
  `firmware/` (PlatformIO) e `desktop-app/` criadas.
- Biblioteca [HelloDrum-arduino-Library](https://github.com/RyoKosaka/HelloDrum-arduino-Library)
  (v0.7.7) clonada e vendorizada em `firmware/lib/HelloDrum-arduino-Library`.
- Análise inicial do código-fonte da lib: confirmado suporte nativo a até 8x
  CD4051 (64 canais) via `rawValue[64]` + `muxNum` sequencial — 4x CD4051 (32
  canais) não exige modificação na lib, apenas cálculo manual do índice do pad
  (`muxNum * 8 + canal_local`).
- Decisões tomadas: placa ESP32-S3, toolchain PlatformIO, lib base vendorizada
  (fork local, não dependência externa). Detalhes em
  [01-decisoes-arquiteturais.md](01-decisoes-arquiteturais.md).
- Identificada lacuna: a lib não tem exemplo de USB-MIDI nativo para ESP32 (só
  BLE-MIDI ou MIDI serial) — vai precisar de integração própria com a stack USB
  (TinyUSB) do core arduino-esp32. Ver
  [03-biblioteca-hellodrum.md](03-biblioteca-hellodrum.md).
- Nota de ambiente: PlatformIO CLI ainda não instalado na máquina de dev.

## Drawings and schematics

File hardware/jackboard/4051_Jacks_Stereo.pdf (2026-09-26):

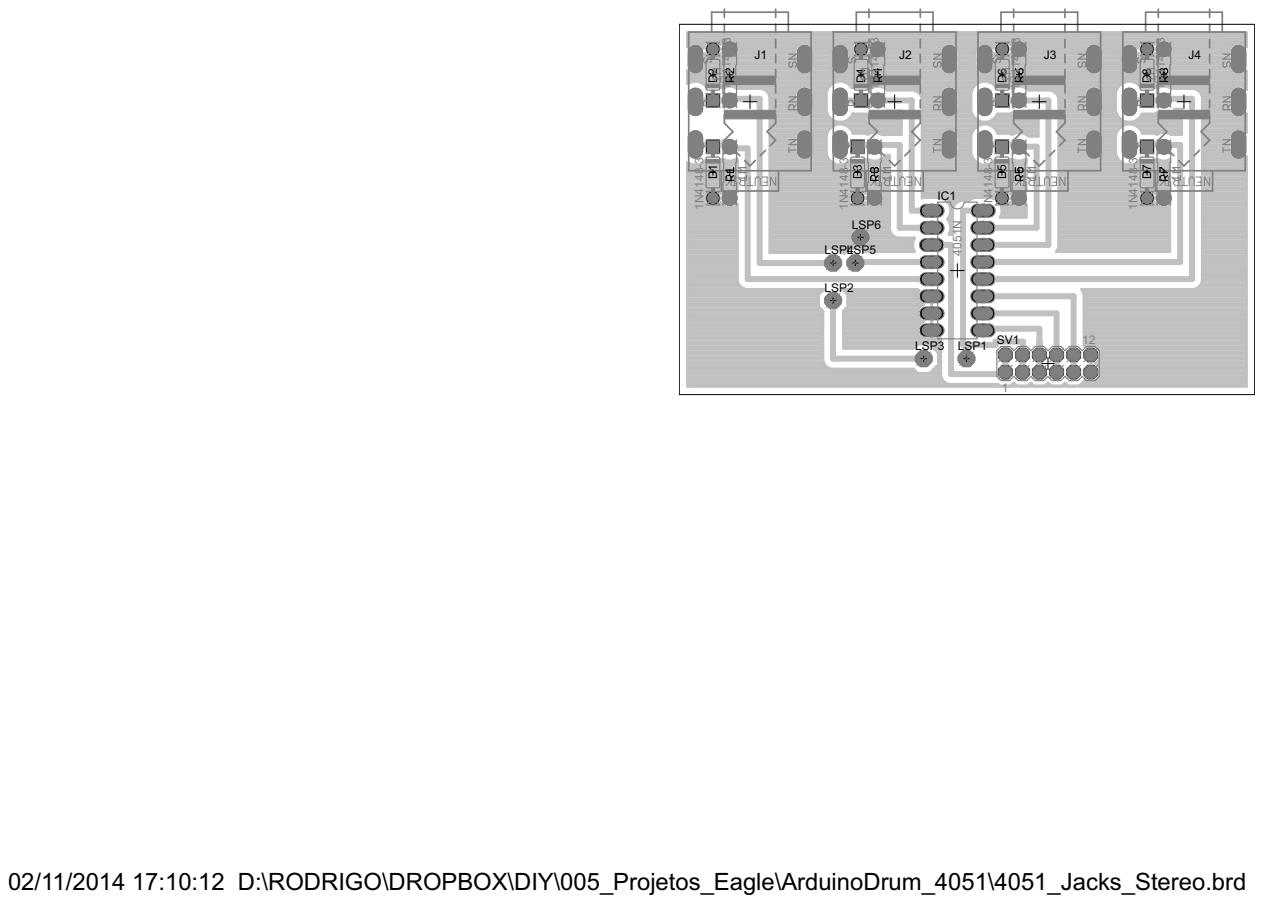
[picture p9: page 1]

02/11/2014 17:10:12 D:\RODRIGO\DROPBOX\DIY\005_Projetos_Eagle\ArduinoDrum_4051\4051_Jacks_Stereo.brd

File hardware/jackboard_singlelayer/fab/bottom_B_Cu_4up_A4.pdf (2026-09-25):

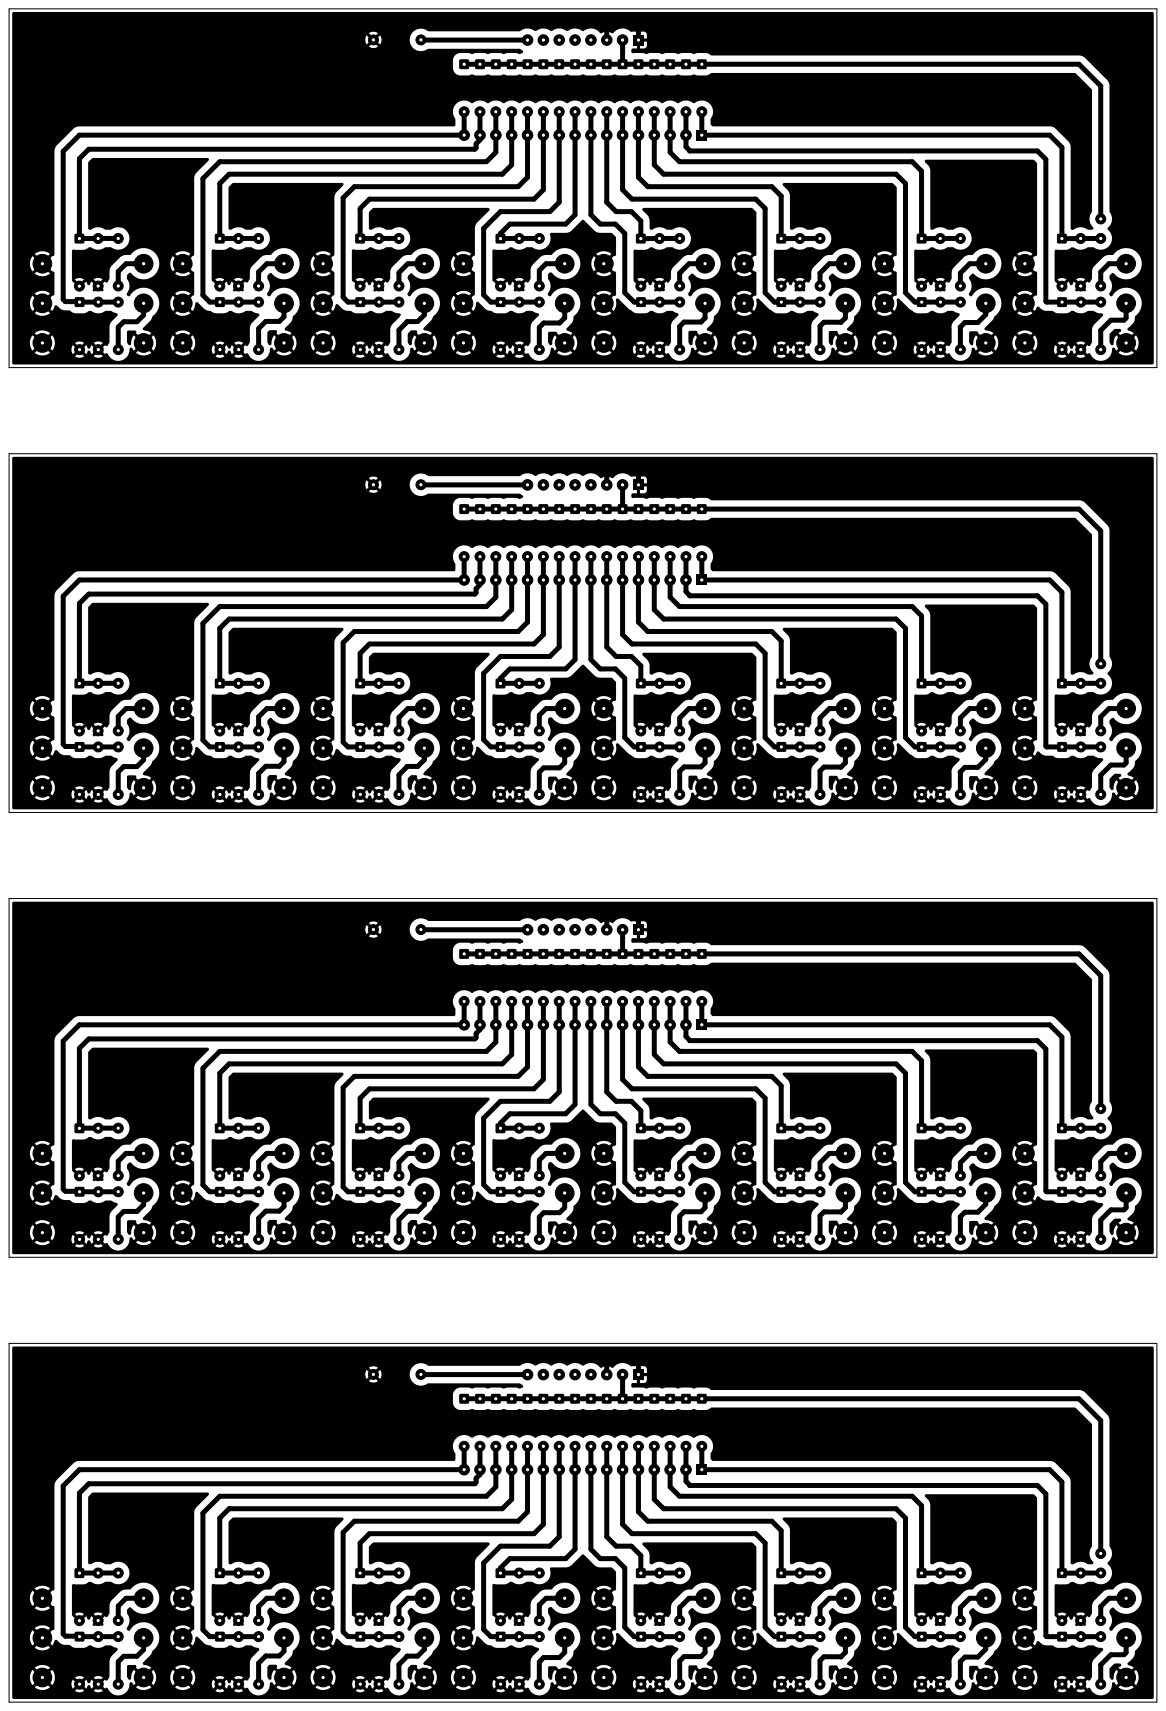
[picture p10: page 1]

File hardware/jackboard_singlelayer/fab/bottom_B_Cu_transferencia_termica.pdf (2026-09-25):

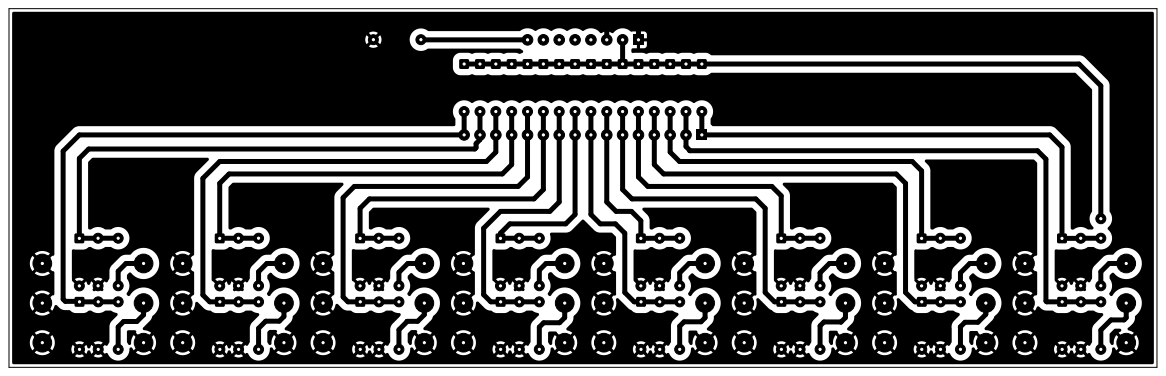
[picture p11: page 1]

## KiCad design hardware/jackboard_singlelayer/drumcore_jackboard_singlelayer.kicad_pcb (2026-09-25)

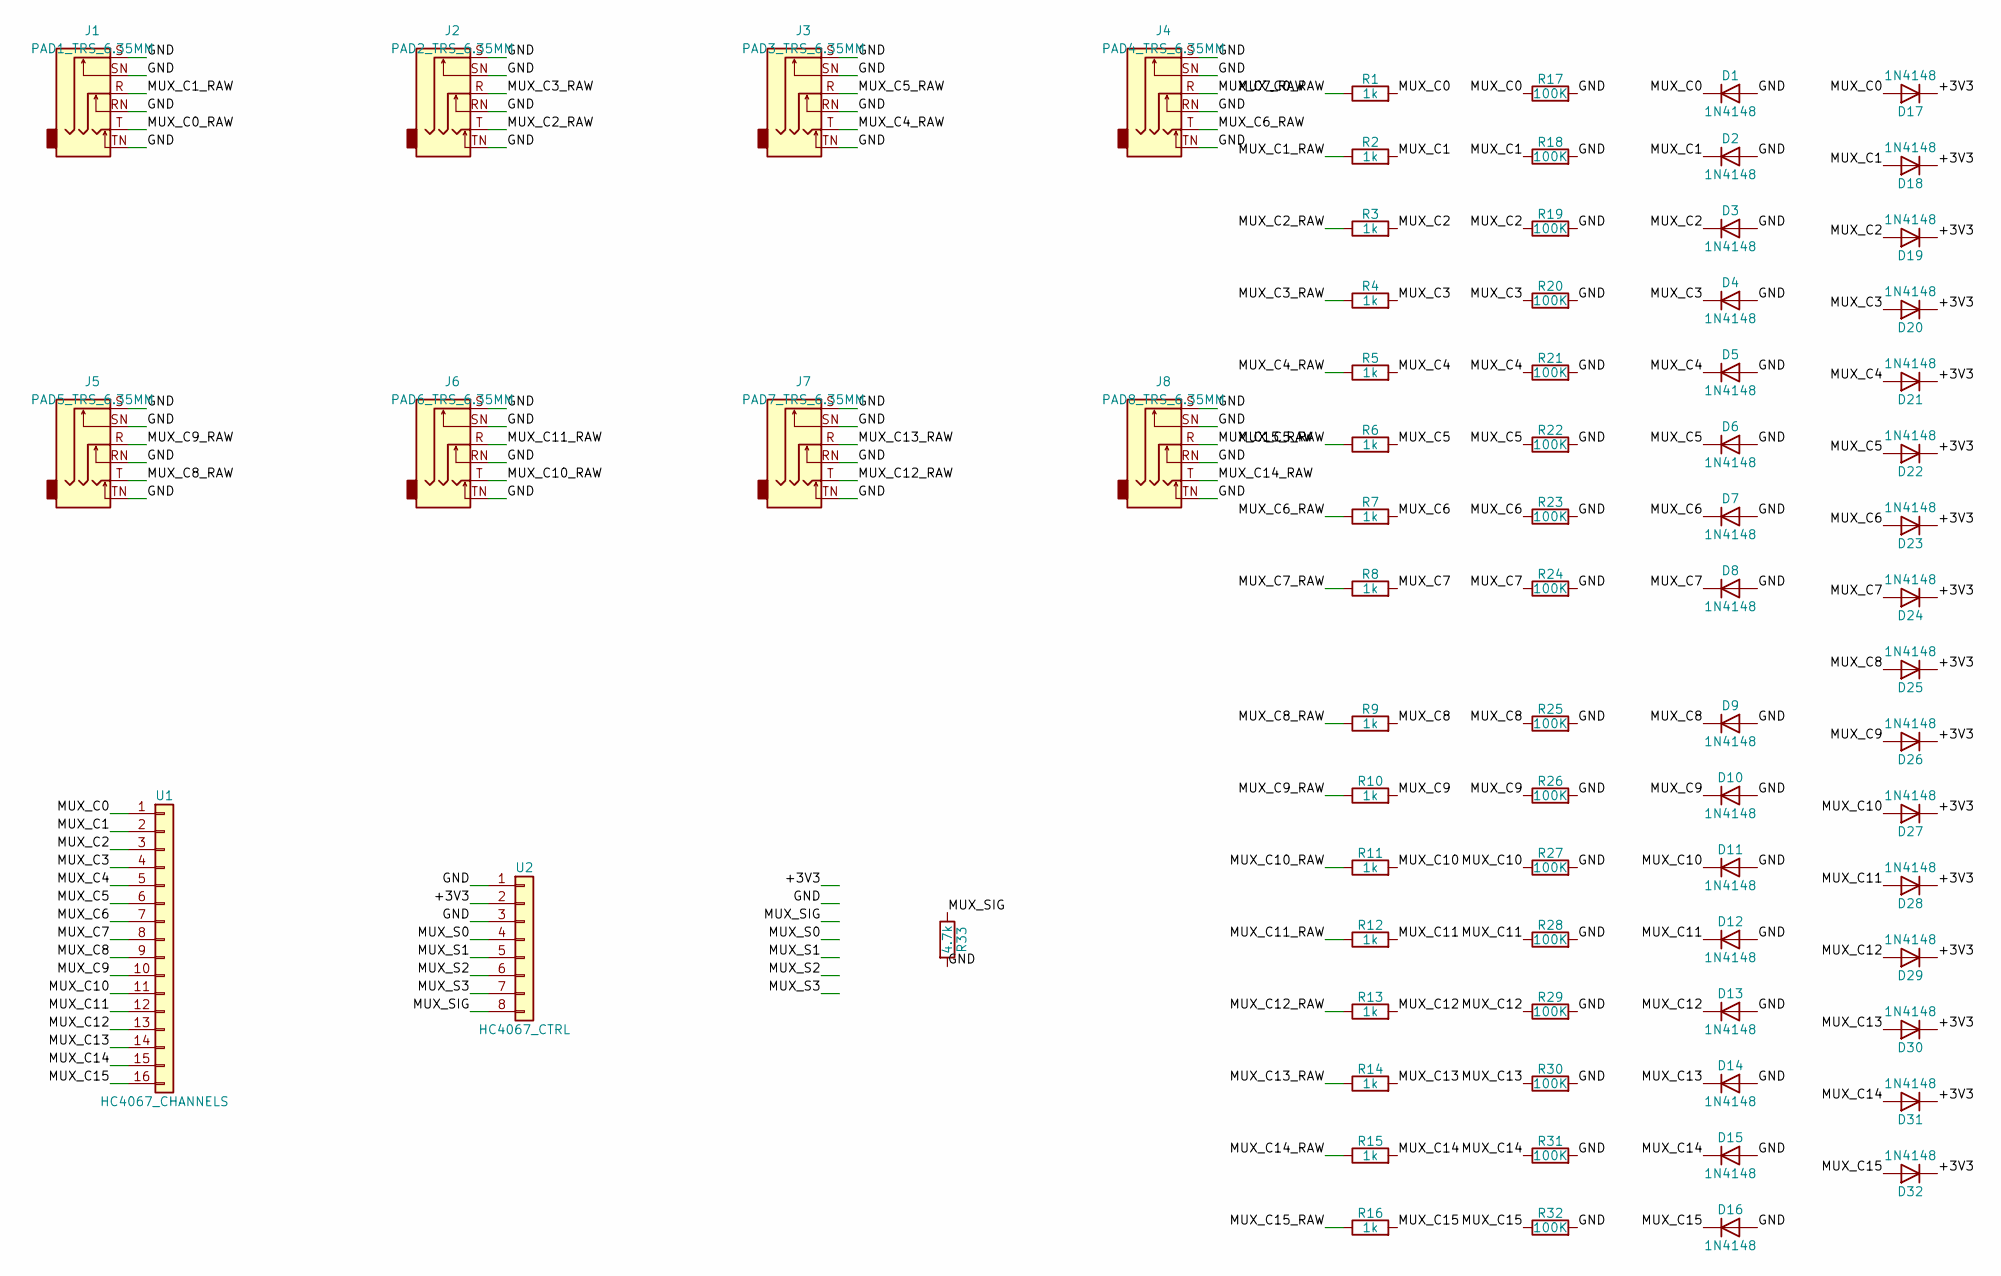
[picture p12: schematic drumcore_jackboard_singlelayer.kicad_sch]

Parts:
D1, D2, D3, D4, D5, D6, D7, D8, D9, D10, D11, D12, D13, D14, D15, D16, D17, D18, D19, D20, D21, D22, D23, D24, D25, D26, D27, D28, D29, D30, D31, D32: 1N4148; D_DO-35_SOD27_P7.62mm_Horizontal
J1: PAD1_TRS_6.35MM; Jack_6.35mm_Neutrik_NMJ6HCD2_Horizontal
J2: PAD2_TRS_6.35MM; Jack_6.35mm_Neutrik_NMJ6HCD2_Horizontal
J3: PAD3_TRS_6.35MM; Jack_6.35mm_Neutrik_NMJ6HCD2_Horizontal
J4: PAD4_TRS_6.35MM; Jack_6.35mm_Neutrik_NMJ6HCD2_Horizontal
J5: PAD5_TRS_6.35MM; Jack_6.35mm_Neutrik_NMJ6HCD2_Horizontal
J6: PAD6_TRS_6.35MM; Jack_6.35mm_Neutrik_NMJ6HCD2_Horizontal
J7: PAD7_TRS_6.35MM; Jack_6.35mm_Neutrik_NMJ6HCD2_Horizontal
J8: PAD8_TRS_6.35MM; Jack_6.35mm_Neutrik_NMJ6HCD2_Horizontal
R1, R2, R3, R4, R5, R6, R7, R8, R9, R10, R11, R12, R13, R14, R15, R16: 1k; R_Axial_DIN0207_L6.3mm_D2.5mm_P7.62mm_Horizontal
R17, R18, R19, R20, R21, R22, R23, R24, R25, R26, R27, R28, R29, R30, R31, R32: 100K; R_Axial_DIN0207_L6.3mm_D2.5mm_P7.62mm_Horizontal
R33: 4.7k; R_Axial_DIN0207_L6.3mm_D2.5mm_P7.62mm_Horizontal
U1: HC4067_CHANNELS; PinSocket_1x16_P2.54mm_Vertical
U2: HC4067_CTRL; PinSocket_1x08_P2.54mm_Vertical

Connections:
/+3V3: D17.1 (K), D18.1 (K), D19.1 (K), D20.1 (K), D21.1 (K), D22.1 (K), D23.1 (K), D24.1 (K), D25.1 (K), D26.1 (K), D27.1 (K), D28.1 (K), D29.1 (K), D30.1 (K), D31.1 (K), D32.1 (K), U2.2
/GND: D1.2 (A), D2.2 (A), D3.2 (A), D4.2 (A), D5.2 (A), D6.2 (A), D7.2 (A), D8.2 (A), D9.2 (A), D10.2 (A), D11.2 (A), D12.2 (A), D13.2 (A), D14.2 (A), D15.2 (A), D16.2 (A), J1.RN, J1.S, J1.SN, J1.TN, J2.RN, J2.S, J2.SN, J2.TN, J3.RN, J3.S, J3.SN, J3.TN, J4.RN, J4.S, J4.SN, J4.TN, J5.RN, J5.S, J5.SN, J5.TN, J6.RN, J6.S, J6.SN, J6.TN, J7.RN, J7.S, J7.SN, J7.TN, J8.RN, J8.S, J8.SN, J8.TN, R17.2, R18.2, R19.2, R20.2, R21.2, R22.2, R23.2, R24.2, R25.2, R26.2, R27.2, R28.2, R29.2, R30.2, R31.2, R32.2, R33.2, U2.1, U2.3
/MUX_C0: D1.1 (K), D17.2 (A), R1.2, R17.1, U1.1
/MUX_C0_RAW: J1.T, R1.1
/MUX_C1: D2.1 (K), D18.2 (A), R2.2, R18.1, U1.2
/MUX_C1_RAW: J1.R, R2.1
/MUX_C2: D3.1 (K), D19.2 (A), R3.2, R19.1, U1.3
/MUX_C2_RAW: J2.T, R3.1
/MUX_C3: D4.1 (K), D20.2 (A), R4.2, R20.1, U1.4
/MUX_C3_RAW: J2.R, R4.1
/MUX_C4: D5.1 (K), D21.2 (A), R5.2, R21.1, U1.5
/MUX_C4_RAW: J3.T, R5.1
/MUX_C5: D6.1 (K), D22.2 (A), R6.2, R22.1, U1.6
/MUX_C5_RAW: J3.R, R6.1
/MUX_C6: D7.1 (K), D23.2 (A), R7.2, R23.1, U1.7
/MUX_C6_RAW: J4.T, R7.1
/MUX_C7: D8.1 (K), D24.2 (A), R8.2, R24.1, U1.8
/MUX_C7_RAW: J4.R, R8.1
/MUX_C8: D9.1 (K), D25.2 (A), R9.2, R25.1, U1.9
/MUX_C8_RAW: J5.T, R9.1
/MUX_C9: D10.1 (K), D26.2 (A), R10.2, R26.1, U1.10
/MUX_C9_RAW: J5.R, R10.1
/MUX_C10: D11.1 (K), D27.2 (A), R11.2, R27.1, U1.11
/MUX_C10_RAW: J6.T, R11.1
/MUX_C11: D12.1 (K), D28.2 (A), R12.2, R28.1, U1.12
/MUX_C11_RAW: J6.R, R12.1
/MUX_C12: D13.1 (K), D29.2 (A), R13.2, R29.1, U1.13
/MUX_C12_RAW: J7.T, R13.1
/MUX_C13: D14.1 (K), D30.2 (A), R14.2, R30.1, U1.14
/MUX_C13_RAW: J7.R, R14.1
/MUX_C14: D15.1 (K), D31.2 (A), R15.2, R31.1, U1.15
/MUX_C14_RAW: J8.T, R15.1
/MUX_C15: D16.1 (K), D32.2 (A), R16.2, R32.1, U1.16
/MUX_C15_RAW: J8.R, R16.1
/MUX_S0: U2.4
/MUX_S1: U2.5
/MUX_S2: U2.6
/MUX_S3: U2.7
/MUX_SIG: R33.1, U2.8

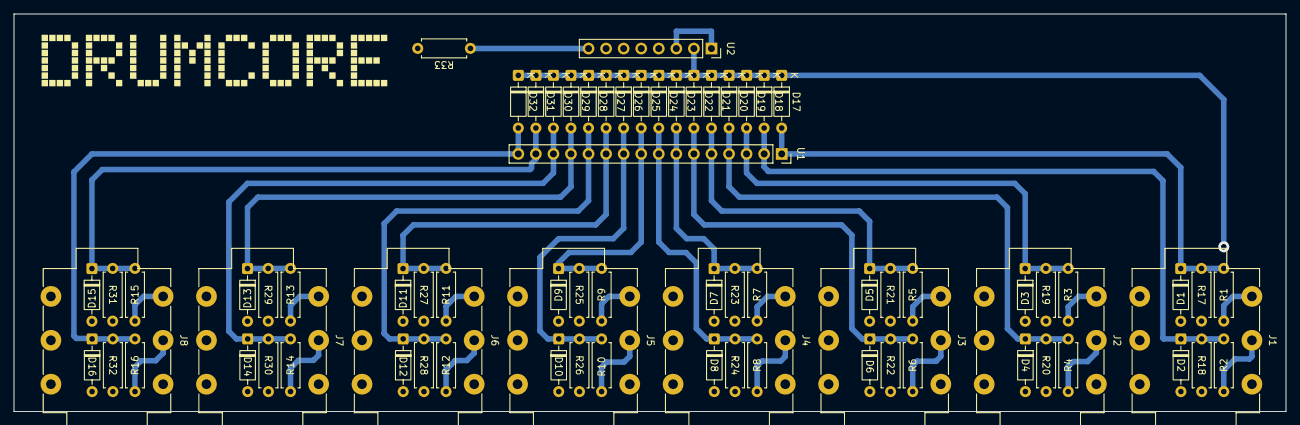
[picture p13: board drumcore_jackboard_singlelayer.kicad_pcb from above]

Board: 2 copper layers, 184.0 x 57.5 mm, 75 parts (0 on the bottom side), 35 nets.

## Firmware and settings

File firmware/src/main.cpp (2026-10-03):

/*
  DrumCore - Firmware ESP32-S3 (módulo MIDI-USB/BLE para bateria eletrônica)

  Projeto renomeado de "HelloDrum" para "DrumCore" em 2026-08-21 - ver
  docs/01-decisoes-arquiteturais.md. A biblioteca de sensing de terceiros
  (vendorizada em firmware/lib/HelloDrum-arduino-Library) mantém o nome
  original do autor (RyoKosaka) - não é nosso projeto, não renomeamos.

  Fases A-H (leitura de 32 canais, USB-MIDI, EEPROM, protocolo serial, nome
  livre por pad, tipos de sensor, BLE-MIDI): ver histórico em
  docs/CHANGELOG.md e docs/01-decisoes-arquiteturais.md - a base de sensing,
  persistência e protocolo dessas fases continua igual.

  Fase J: navegação/tela redesenhada seguindo o spec de UI em design/SPEC.md
  (produzido com Claude Design) - substitui inteiramente a Fase C/I. Agora
  são 6 telas (BOOT, LIVE, PADS, PAD_EDIT, SIGNAL, GLOBAL) com semântica de
  encoder diferente (ENC1 = página/pad em foco, ENC2 = navegação/valor,
  ambos com gesto de hold 600ms) e persistência explícita (GLOBAL > SALVAR)
  em vez de auto-save a cada edição pelos encoders. Ver
  docs/01-decisoes-arquiteturais.md pro racional completo e as adaptações
  feitas (não tínhamos DIN MIDI, o app continua com auto-save).

  Fase K: troca da multiplexação de 4x CD4051 (8 canais cada) para 2x
  CD4067/HW-178 (16 canais cada) - mesmas 32 entradas, só menos placas pra
  montar. Só a camada de MUX mudou (HelloDrumMUX_4067 em vez de _4051, 4
  pinos de seleção S0-S3 em vez de 3); pads[]/rawValue[]/EEPROM/protocolo
  continuam iguais. Ver docs/01-decisoes-arquiteturais.md.

  Pinout: ver docs/02-hardware.md. Build: ver firmware/platformio.ini.
*/

#include <Arduino.h>
#include <Adafruit_TinyUSB.h>
#include <MIDI.h>
#include <hellodrum.h>
#include <SPI.h>
#include <Adafruit_GFX.h>
#include <Adafruit_ST7735.h>
#include <RotaryEncoder.h>
#include <ArduinoJson.h>
#include <BLEMIDI_Transport.h>
#include <hardware/BLEMIDI_ESP32.h>
#include <math.h>

// Versao do firmware - injetada em build_flags via firmware/version_flag.py
// (le a env var FW_VERSION, setada pelo workflow de release a partir da tag
// git) a partir da tag git da release. Fallback "dev" cobre builds locais
// fora da CI, e os envs de teste isolado (test_display.cpp etc.), que nao
// carregam esse extra_scripts. Usado na tela BOOT e no campo
// "firmware_version" de device_info (ver sendDeviceInfo()) - e' o que
// permite o app comparar contra a ultima release no GitHub.
#ifndef FW_VERSION
#define FW_VERSION "dev"
#endif

// Religamento manual do hardware USB nativo (Fase Q, 2026-09-01) - ver
// docs/01-decisoes-arquiteturais.md pro relato completo da investigacao.
// No ESP32/Adafruit TinyUSB Arduino, Adafruit_USBD_Device::begin() NAO liga
// o periferico USB de verdade (e' um stub vazio nesse chip - a lib assume
// que o core arduino-esp32 faz isso). O caminho automatico do core
// (USB.begin(), via CDC/MSC/DFU_ON_BOOT) so' dispara com essas flags
// ligadas, e QUANDO usado aqui travou o boot (a tarefa "usbd" do CORE
// chamando tud_task() da ADAFRUIT - duas pilhas TinyUSB diferentes
// misturadas, incompativeis, nucleo trava, watchdog aborta em loop).
// A funcao abaixo e' a mesma sequencia que a PROPRIA lib Adafruit usa nas
// outras placas que suporta (SAMD/RP2040/nRF) - reset do periferico,
// configuracao dos pinos D+/D- (USBPHY_DM_NUM/DP_NUM), reset do core DWC2,
// tusb_init() - só que ela vem DESLIGADA de proposito no arquivo da lib
// pra ESP32 (Adafruit_TinyUSB_esp32.cpp, bloco "#if 0", comentario "This
// port implemented is not needed and left here for reference only").
// Replicamos aqui (sem editar o arquivo vendorizado da lib) porque e' a
// unica forma encontrada que efetivamente religa o hardware sem misturar
// as duas pilhas TinyUSB diferentes que coexistem nesse binario (a
// precompilada do core, libarduino_tinyusb.a, e a da Adafruit, compilada a
// partir do source) - usa so' as pecas de baixo nivel da Adafruit (mesma
// origem do tud_task() que "ganha" no link via -Wl,--allow-multiple-definition,
// ver platformio.ini), entao fica tudo consistente/da mesma implementacao.
#include "soc/soc.h"
#include "soc/periph_defs.h"
#include "soc/usb_periph.h"
#include "soc/usb_struct.h"
#include "soc/usb_reg.h"
#include "hal/usb_hal.h"
#include "driver/gpio.h"
#include "driver/periph_ctrl.h"
#include "esp_rom_gpio.h"
#include "wifi_portal.h" // Fase AE - Wi-Fi + ConfigTool servido pela placa

#define USBD_STACK_SZ (4096)

static void usbHardwareTask(void *param)
{
    (void)param;
    while (1)
    {
        tud_task();
    }
}

static void configureUsbPins(usb_hal_context_t *usb)
{
    for (const usb_iopin_dsc_t *iopin = usb_periph_iopins; iopin->pin != -1; ++iopin)
    {
        if ((usb->use_external_phy) || (iopin->ext_phy_only == 0))
        {
            esp_rom_gpio_pad_select_gpio(iopin->pin);
            if (iopin->is_output)
            {
                esp_rom_gpio_connect_out_signal(iopin->pin, iopin->func, false, false);
            }
            else
            {
                esp_rom_gpio_connect_in_signal(iopin->pin, iopin->func, false);
                if ((iopin->pin != GPIO_FUNC_IN_LOW) && (iopin->pin != GPIO_FUNC_IN_HIGH))
                {
                    PIN_INPUT_ENABLE(GPIO_PIN_MUX_REG[iopin->pin]);
                }
            }
            esp_rom_gpio_pad_unhold(iopin->pin);
        }
    }
    if (!usb->use_external_phy)
    {
        gpio_set_drive_capability((gpio_num_t)USBPHY_DM_NUM, GPIO_DRIVE_CAP_3);
        gpio_set_drive_capability((gpio_num_t)USBPHY_DP_NUM, GPIO_DRIVE_CAP_3);
    }
}

void bringUpNativeUsbHardware()
{
    periph_module_reset(PERIPH_USB_MODULE);
    periph_module_enable(PERIPH_USB_MODULE);

    usb_hal_context_t hal = {.use_external_phy = false};
    usb_hal_init(&hal);
    configureUsbPins(&hal);

    USB0.grstctl |= USB_CSFTRST;
    while ((USB0.grstctl & USB_CSFTRST) == USB_CSFTRST)
    {
    }

    // API nova do TinyUSB (versao vendorizada aqui exige role/speed
    // explicitos - o tusb_init() sem argumentos so' compila se
    // CFG_TUSB_RHPORT0_MODE estiver definido em tusb_config.h, o que nao e'
    // o caso nesse port ESP32 da Adafruit).
    tusb_rhport_init_t rhInit = {.role = TUSB_ROLE_DEVICE, .speed = TUSB_SPEED_AUTO};
    tusb_init(0, &rhInit);

    xTaskCreate(usbHardwareTask, "usbd", USBD_STACK_SZ, NULL, configMAX_PRIORITIES - 1, NULL);
}

// ---------------------------------------------------------------------------
// Pinout - Fase Z (2026-09-05, reorganizado por FUNCAO em vez de por
// alimentacao - ver docs/01-decisoes-arquiteturais.md pro racional
// completo). Usa o pinout REAL da placa comprada (dev board ESP32-S3 c/
// headers fisicos esquerdo/direito - ver docs/02-hardware.md). A partir
// desta fase a placa fisica vai ter 3V3/GND disponiveis nos DOIS headers
// (pads extras adicionados por fora do dev board original), entao a
// divisao deixou de ser "quem precisa de VCC" (Fase L) e passou a ser por
// FUNCAO: interface do usuario (encoder + tela) num header, sensing (MUX)
// no outro - cada lado continua usando um bloco unico de pinos fisicamente
// CONTIGUOS (sem nenhum outro sinal no meio), so' que agrupados por essa
// logica nova:
//   HEADER ESQUERDO - interface (encoder + tela), GPIO4,5,6,7,15,16,17,18,8
//     (bloco continuo de 9 pinos, logo apos o 3V3/RST do topo): encoder nos
//     3 primeiros (4,5,6), tela nos 6 seguintes (7,15,16,17,18,8).
//   HEADER DIREITO - sensing (2x CD4067), GPIO1,2,42,41,40,39 (bloco
//     continuo de 6 pinos, mesma faixa antes usada pelos 2 encoders -
//     Fase Y ja tinha liberado GPIO1/2/42 do 2o encoder; agora GPIO41/40/39
//     tambem saem do encoder unico, que migrou pro header esquerdo).
// SIG0/SIG1 (leitura analogica dos 2 MUX) precisam de pino ADC - unicos 2
// pinos ADC nesse bloco direito sao GPIO1/GPIO2 (ADC1_CH0/CH1), entao SIG0/
// SIG1 ficam neles; S0-S3 (linhas digitais de selecao, sem precisar de ADC)
// ficam em GPIO42/41/40/39. Isso troca o MUX de ADC2 (Fase L) pra ADC1 -
// simplifica o racional antigo ("ADC2 e' seguro aqui pq nao tem Wi-Fi"): em
// ADC1 esse cuidado nem precisa ser mencionado, nunca conflita com nada.
// ---------------------------------------------------------------------------

// --- Encoder (1x, Fase Y) - header ESQUERDO ---
#define ENC_A 4
#define ENC_B 5
#define ENC_SW 6

#define HOLD_MS 600     // duracao de "hold" no encoder (design/SPEC.md)
#define SW_DEBOUNCE_MS 25

// --- Tela TFT ST7735 (SPI) - header ESQUERDO, mesmo bloco do encoder ---
// Ordem dos GPIOs (7,15,16,17,18,8) casada com a ordem fisica do proprio
// conector da tela (GND,VDD,SCL,SDA,RST,DC,CS,BLK - a pedido do Rodrigo,
// 2026-09-06) - sem cruzar fio nenhum: SCL(7),SDA(15),RST(16),DC(17),
// CS(18),BLK(8).
#define TFT_SCLK 7
#define TFT_MOSI 15
#define TFT_RST 16
#define TFT_DC 17
#define TFT_CS 18
#define TFT_BLK 8

// --- CD4067 (2x, 32 canais) - header DIREITO ---
// 2026-10-01: ordem do S0-S3 invertida (S0=39 ... S3=42) e SIGs trocados
// pra bater com a fiacao da jackboard A montada (Rodrigo). GPIO39-42 sao os
// pinos de JTAG por pino (MTCK/MTDO/MTDI/MTMS), livres como GPIO - o S3 usa
// o JTAG pelo USB (GPIO19/20) por padrao; nenhum deles e' de strapping.
#define MUX_S0 39
#define MUX_S1 40
#define MUX_S2 41
#define MUX_S3 42

#define MUX0_Z 2 // SIG da jackboard A (jacks 1-8, pads 0-15) - ADC1_1
#define MUX1_Z 1 // SIG da jackboard B (jacks 9-16, pads 16-31) - ADC1_0

#define NUM_MUX 2
#define PADS_PER_MUX 16
#define NUM_PADS (NUM_MUX * PADS_PER_MUX) // 32

// ---------------------------------------------------------------------------
// Paleta (RGB565) - tokens do design/SPEC.md secao 4.
// ---------------------------------------------------------------------------
#define COL_BG 0x10A3
#define COL_SURFACE 0x1925
#define COL_LINE 0x3A09
#define COL_TXT_DIM 0x7C52
#define COL_TXT 0xE77E
#define COL_ACCENT 0x069F
#define COL_EDIT 0xFD84
#define COL_HIT 0xFBC3
#define COL_OK 0x368F

// Canal MIDI de percussao (GM), agora configuravel via GLOBAL > MIDI CH
// (persistido em midiChannel - ver globals mais abaixo). DRUM_MIDI_CHANNEL
// so' e' usado como valor padrao no primeiro boot.
#define DEFAULT_MIDI_CHANNEL 10

// CC usado para a posicao do pedal de chimbal (pad.pedalCC, ja vem 0-127 da
// lib). 4 = "Foot Controller" no GM - ajustar se o software do outro lado
// esperar outro numero de CC.

// Primeira nota MIDI usada (pad 0) - so para identificar cada canal nos
// testes iniciais. O usuario pode reatribuir por pad via a tela ou o app.
#define FIRST_TEST_NOTE 36

// Nome livre por pad (ex: "Caixa"), editavel so pelo app (nao entra
// no fluxo dos encoders/TFT) - ver docs/01-decisoes-arquiteturais.md. O
// numero do pad nunca e' editavel: o nome exibido e' sempre "N - Label", ou
// "Pad N" enquanto nao houver label definido.
#define PAD_LABEL_MAX_LEN 20                     // "Chimbal Aberto" etc + '\0'
#define PAD_NAME_MAX_LEN (PAD_LABEL_MAX_LEN + 8) // "32 - " + label + margem

// ---------------------------------------------------------------------------
// Tipos de sensor por pad (Fase G) - ver docs/05-tipos-de-sensor.md pro
// detalhamento de cada tipo (campos usados, canais consumidos, etc). Nenhum
// tipo dessa lib usa mais de 2 canais - o construtor de HelloDrum so aceita
// 1 ou 2 pinos.
// ---------------------------------------------------------------------------
#define PAD_SINGLE 0        // 1 canal - pad/prato simples
#define PAD_DUAL 1          // 2 canais - pad com aro (head + rim)
#define PAD_HIHAT_SINGLE 2  // 1 canal - chimbal simples (nota muda com open/close do pedal linkado)
#define PAD_CYMBAL_2ZONE 3  // 2 canais - prato 2 zonas (bow + edge)
#define PAD_HIHAT_2ZONE 4   // 2 canais - chimbal 2 zonas (bow + edge, nota muda com open/close)
#define PAD_CYMBAL_3ZONE 5  // 2 canais - prato 3 zonas (bow + edge/cup por threshold, ex: PCY135/155)
#define PAD_HIHAT_PEDAL 6   // 1 canal - controlador de pedal FSR/VH-10/VH-11
#define PAD_HIHAT_OPTICAL 7 // 1 canal - controlador de pedal optico (TCRT5000)
// 2 canais - caixa 3 zonas (centro/pele=head, borda da pele=edge, aro=rim),
// so' com 2 piezos: tip = piezo central, ring = piezo da borda/aro.
// 2026-10-01: usa snare3zoneMUX()/snare3zoneSensing() (lib vendorizada) -
// aro pela RAZAO pico ring / pico tip (rim_threshold = %), borda da pele
// pela razao pico tardio / pico cedo do piezo central (rim_sensitivity = %).
// Antes reusava cymbal3zoneSensing() (esquema Yamaha de chaves, espera
// pull-up - nao servia pra piezo). Ver docs/05-tipos-de-sensor.md.
#define PAD_SNARE_3ZONE 8
// 1 canal - sensor de contato (fita de aluminio ligada direto no pino
// analogico, sem piezo). Nao usa envelope/threshold de vibracao da lib -
// e' um gatilho binario: raw acima do threshold configurado = "tocado",
// dispara nota com velocity fixo em 127 (sem curva/gain/sensibilidade pra
// calibrar, ver getFieldsForType()). Ver dispatchChoke() e
// docs/05-tipos-de-sensor.md.
#define PAD_CHOKE 9
#define PAD_TYPE_COUNT 10

#define PAD_NO_LINK 255 // valor "nenhum" para hihatPedalChannel[]

bool padTypeUsesSecondChannel(byte type)
{
    return type == PAD_DUAL || type == PAD_CYMBAL_2ZONE || type == PAD_HIHAT_2ZONE || type == PAD_CYMBAL_3ZONE || type == PAD_SNARE_3ZONE;
}

// Jackboard: cada jack TRS leva 2 canais - canal par (0-based: 0, 2, 4...)
// = TIP, impar = RING (confirmado pelo Rodrigo, 2026-09-27; ver
// docs/02-hardware.md). Pad de 2 zonas le a zona principal no proprio canal
// e a 2a no seguinte (recomputeChannelPrimary()), entao so' pode comecar no
// TIP: pele/corpo no tip, aro/borda no ring - padrao dos pads de mercado.
// Comecando num RING a 2a zona cairia no tip do jack seguinte (outro cabo).
bool padIsJackTip(byte pad)
{
    return (pad % 2) == 0;
}

// Tipos "chimbal simples" / "chimbal 2 zonas" (nota muda com o pedal
// linkado) ficam OCULTOS desde 2026-09-27: com softwares como o Addictive
// Drums 2 o chimbal e' um pad comum com nota fixa e o software decide
// aberto/fechado pelo CC do pedal. O codigo continua aqui e configs antigas
// seguem funcionando - so' nao da' pra escolher esses tipos na tela (e o
// app tambem nao oferece). set_pad ainda aceita (import de backups).
bool padTypeHidden(byte type)
{
    return type == PAD_HIHAT_SINGLE || type == PAD_HIHAT_2ZONE;
}

bool padTypeAllowedAt(byte pad, byte type)
{
    if (!padTypeUsesSecondChannel(type))
    {
        return true;
    }
    return padIsJackTip(pad) && pad < NUM_PADS - 1;
}

bool padTypeIsHihatCymbal(byte type)
{
    return type == PAD_HIHAT_SINGLE || type == PAD_HIHAT_2ZONE;
}

bool padTypeIsHihatPedal(byte type)
{
    return type == PAD_HIHAT_PEDAL || type == PAD_HIHAT_OPTICAL;
}

const char *padTypeShortName(byte type)
{
    switch (type)
    {
    case PAD_SINGLE:
        return "PIEZO";
    case PAD_DUAL:
        return "DUAL";
    case PAD_HIHAT_SINGLE:
        return "HH-1Z";
    case PAD_CYMBAL_2ZONE:
        return "CY-2Z";
    case PAD_HIHAT_2ZONE:
        return "HH-2Z";
    case PAD_CYMBAL_3ZONE:
        return "CY-3Z";
    case PAD_HIHAT_PEDAL:
        return "HH-CTL";
    case PAD_HIHAT_OPTICAL:
        return "HH-OPT";
    case PAD_SNARE_3ZONE:
        return "SNR-3Z";
    case PAD_CHOKE:
        return "CHOKE";
    default:
        return "?";
    }
}

// ---------------------------------------------------------------------------
// Saida MIDI - GLOBAL > SAIDA. O design original (design/SPEC.md) previa
// USB/DIN/USB+DIN, mas nao temos circuito de MIDI DIN (5 pinos) no
// hardware - adaptamos pra USB/BLE/USB+BLE, os dois transportes que
// realmente existem (Fase B e H). Ver docs/01-decisoes-arquiteturais.md.
// ---------------------------------------------------------------------------
#define OUTPUT_USB 0
#define OUTPUT_BLE 1
#define OUTPUT_USB_BLE 2

// ---------------------------------------------------------------------------
// EEPROM (persistencia)
// Layout: 10 bytes/pad (campos da lib) + 1 byte flag primeiro-boot +
// PAD_LABEL_MAX_LEN bytes/pad (nome) + 1 byte/pad (tipo) + 1 byte/pad
// (link do pedal de chimbal) + 1 byte/pad (canal habilitado, Fase N) +
// 1 byte/pad (retrigger, Fase P - persistido separado da lib de proposito,
// ver docs/01-decisoes-arquiteturais.md) + 1 byte/pad (gain, Fase P) +
// 1 byte/pad (xtalk, Fase P) + 1 byte/pad (xtalk_group, Fase P) +
// 1 byte/pad (hihat_invert, Fase X) + 2 bytes de config global
// (midi_channel, midi_output).
// ---------------------------------------------------------------------------
#define EEPROM_BYTES_PER_PAD 10
#define EEPROM_INIT_FLAG_ADDR (NUM_PADS * EEPROM_BYTES_PER_PAD)
#define EEPROM_NAMES_ADDR (EEPROM_INIT_FLAG_ADDR + 1)
#define EEPROM_TYPES_ADDR (EEPROM_NAMES_ADDR + NUM_PADS * PAD_LABEL_MAX_LEN)
#define EEPROM_HIHAT_LINK_ADDR (EEPROM_TYPES_ADDR + NUM_PADS)
#define EEPROM_ENABLED_ADDR (EEPROM_HIHAT_LINK_ADDR + NUM_PADS)
#define EEPROM_RETRIGGER_ADDR (EEPROM_ENABLED_ADDR + NUM_PADS)
#define EEPROM_GAIN_ADDR (EEPROM_RETRIGGER_ADDR + NUM_PADS)
#define EEPROM_XTALK_ADDR (EEPROM_GAIN_ADDR + NUM_PADS)
#define EEPROM_XTALK_GROUP_ADDR (EEPROM_XTALK_ADDR + NUM_PADS)
#define EEPROM_HIHAT_INVERT_ADDR (EEPROM_XTALK_GROUP_ADDR + NUM_PADS)
#define EEPROM_GLOBAL_ADDR (EEPROM_HIHAT_INVERT_ADDR + NUM_PADS)
// 2026-09-27: 2 areas novas no FIM do layout - os enderecos antigos nao
// mudam, e EEPROM.begin() com tamanho maior preserva o conteudo e preenche
// os bytes novos com 0xFF (placa ja' em uso le 0xFF = valor padrao, ver
// loadAllFromEeprom()).
#define EEPROM_PEDAL_NOTE_ADDR (EEPROM_GLOBAL_ADDR + 2)
#define EEPROM_PEDAL_CC_ADDR (EEPROM_PEDAL_NOTE_ADDR + NUM_PADS)
#define EEPROM_JACK_LABELS_ADDR (EEPROM_PEDAL_CC_ADDR + NUM_PADS)
#define EEPROM_SIZE (EEPROM_JACK_LABELS_ADDR + JACK_COUNT * (JACK_LABEL_MAX_LEN + 1))
#define jackLabelEepromAddr(j) (EEPROM_JACK_LABELS_ADDR + (j) * (JACK_LABEL_MAX_LEN + 1))
#define EEPROM_INIT_MAGIC 0xA5

#define padLabelEepromAddr(i) (EEPROM_NAMES_ADDR + (i) * PAD_LABEL_MAX_LEN)

// Cada HelloDrumMUX_4067 recebe um muxNum sequencial automatico (0..1, na
// ordem de instanciacao abaixo). Ver docs/01-decisoes-arquiteturais.md.
HelloDrumMUX_4067 mux[NUM_MUX] = {
    HelloDrumMUX_4067(MUX_S0, MUX_S1, MUX_S2, MUX_S3, MUX0_Z),
    HelloDrumMUX_4067(MUX_S0, MUX_S1, MUX_S2, MUX_S3, MUX1_Z),
};

// pads[i] usa i diretamente como indice em rawValue[] (pin_1), pois os 2 MUX
// acima sao instanciados em ordem (muxNum 0..1) e i == muxNum*PADS_PER_MUX +
// canal. Cada pad e' construido com 2 pinos (i, i+1) quando i+1 existe -
// assim um mesmo objeto ja suporta ser usado como single-channel (metodos
// que so leem pin_1) OU dual-channel (metodos que tambem leem pin_2), sem
// precisar reconstruir nada quando o tipo do pad muda em runtime.
//
// [MODIFICADO - projeto DrumCore, 2026-08-31] array default (sem lista de
// inicializadores) - cada pad e' inicializado via pads[i].begin(...) dentro
// do setup() (ver la), nao aqui. Motivo: uma lista de 27+ chamadas de
// construtor nao-trivial nesse array global travava o boot (watchdog reset
// antes do setup(), sem erro visivel) - a inicializacao estatica roda na
// tarefa principal, que tem so 4KB de pilha; sem garantia de RVO (nao
// estamos em C++17), os temporarios de cada elemento podem ficar vivos
// simultaneamente ate o fim da instrucao inteira, e sizeof(HelloDrum)~100
// bytes x 27+ elementos estoura isso. Isolado e confirmado com um teste
// minimo (26 funciona, 27 nao) - ver docs/01-decisoes-arquiteturais.md pro
// diagnostico completo e firmware/lib/HelloDrum-arduino-Library/src/
// hellodrum.h pro construtor padrao + begin() adicionados.
HelloDrum pads[NUM_PADS];

// Objeto USB-MIDI (TinyUSB) + instancia da lib MIDI (FortySevenEffects) usando
// esse objeto como transporte.
Adafruit_USBD_MIDI usb_midi;
MIDI_CREATE_INSTANCE(Adafruit_USBD_MIDI, usb_midi, MIDI);

// Instancia BLE-MIDI (Fase H) - transporte adicional, em paralelo ao
// USB-MIDI acima. "BleMidi" e' a interface MIDI (usada pra enviar
// notas/CC); a macro tambem gera "BLEBleMidi" (o transporte, usado so pra
// registrar os callbacks de conexao). "DrumCore" e' o nome anunciado via
// Bluetooth.
BLEMIDI_CREATE_INSTANCE("DRUMCORE", BleMidi)

volatile bool bleMidiConnected = false;

// Tela TFT (driver ST7735S, variante 1.44" 128x128 - ver Modelo Tela.jpeg).
Adafruit_ST7735 tft(TFT_CS, TFT_DC, TFT_RST);
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
void loop()
{
#ifdef TINYUSB_NEED_POLLING_TASK
    TinyUSBDevice.task();
#endif

    measureLoop();
    scanActiveChannels();

    applyPadGain(); // Fase P - antes do dispatch, pra ja ler o rawValue calibrado

    for (byte i = 0; i < NUM_PADS; i++)
    {
        // padEnabled[i] == false: canal desligado de proposito (slot sem
        // sensor conectado) - nem processa o rawValue dele, pra ruido/
        // interferencia nesse canal nunca virar hit/nota. Ver
        // docs/01-decisoes-arquiteturais.md (Fase N).
        if (channelPrimary[i] && padEnabled[i])
        {
            dispatchSensing(i);
        }
    }

    suppressCrosstalk(); // Fase P - depois do dispatch, antes de decidir o que enviar

    for (byte i = 0; i < NUM_PADS; i++)
    {
        if (channelPrimary[i] && padEnabled[i])
        {
            handlePadResult(i);
        }
    }

    if (currentPage == PAGE_AUTOTUNE)
    {
        autoTuneTick();
    }

    handleEncoder();
    renderScreen();
    pollSerialCommands();
    wifiPortalPoll(); // Fase AE - comandos vindos do Wi-Fi, rede de casa, busca de redes
}

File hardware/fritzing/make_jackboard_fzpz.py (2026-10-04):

#!/usr/bin/env python3
"""
Gera a peca do Fritzing da jackboard single-layer (DrumCore_Jackboard.fzpz).

Uso:  python hardware/fritzing/make_jackboard_fzpz.py
Saida: hardware/fritzing/DrumCore_Jackboard.fzpz (+ os arquivos soltos em
       hardware/fritzing/part/, pra conferir/editar).

As medidas vem do projeto KiCad hardware/jackboard_singlelayer/ (lidas do
.kicad_pcb e da netlist, sem editar nada - 2026-10-04). Se a placa mudar,
atualizar as constantes abaixo:
  - contorno (Edge.Cuts): x 55.1375-239.1375, y 69.2-126.7 mm (184 x 57,5)
  - jacks J1..J8: origem em x = 234.2075 - 22.5*(n-1), y = 110.05, rot -90;
    pads T (origem), R (+6.35 em y), S (+12.7), TN/RN/SN (-16.23 em x);
    corpo (F.Fab) de x-18.3 a x+0.98, y-6.83 a y+19.7 (passa 3 mm da borda)
  - U2 (controle do MUX, barra 1x8): pino 1 em (156.0275, 74.2), passo -2.54
    em x. Pinos: 1 GND, 2 +3V3, 3 GND (= EN do modulo), 4 S0, 5 S1, 6 S2,
    7 S3, 8 SIG
  - U1 (canais do MUX, barra 1x16): pino 1 em (166.1875, 89.44), passo -2.54
  - J(n) tip = canal 2(n-1), ring = canal 2(n-1)+1 (MUX_C0_RAW...)

Conectores da peca: os 8 pinos de controle (fios pro ESP32) e tip/ring dos
8 jacks (pra ligar os pads no diagrama). Os pads de GND dos jacks aparecem
na vista PCB so' como cobre.
"""
import os
import zipfile

HERE = os.path.dirname(os.path.abspath(__file__))
OUT_DIR = os.path.join(HERE, "part")
FZPZ = os.path.join(HERE, "DrumCore_Jackboard.fzpz")
NAME = "drumcore_jackboard"
# Fixo: mudar o moduleId faz o Fritzing tratar como outra peca.
MODULE_ID = "DrumCore_Jackboard_SingleLayer_v1_5e1c2a7e"

# ------------------------------------------------------------ geometria (mm, KiCad)
BX0, BY0, BX1, BY1 = 55.1375, 69.2, 239.1375, 126.7
BW, BH = BX1 - BX0, BY1 - BY0
JACK_Y = 110.05
JACK_BOTTOM = JACK_Y + 19.7  # bico do jack, fora da borda
H_TOTAL = JACK_BOTTOM - BY0  # altura com os jacks


def jack_x(n):  # n = 1..8
    return 234.2075 - 22.5 * (n - 1)


CTRL_X1, CTRL_Y, PITCH = 156.0275, 74.2, 2.54
CTRL = ["GND", "VCC", "EN", "S0", "S1", "S2", "S3", "SIG"]
CTRL_DESC = {
    "GND": "GND",
    "VCC": "Alimentacao 3,3 V (VCC do MUX e grampo dos diodos)",
    "EN": "EN do MUX - ja ligado ao GND na placa",
    "S0": "Selecao de canal S0 (ESP32 GPIO39)",
    "S1": "Selecao de canal S1 (ESP32 GPIO40)",
    "S2": "Selecao de canal S2 (ESP32 GPIO41)",
    "S3": "Selecao de canal S3 (ESP32 GPIO42)",
    "SIG": "Saida analogica do MUX (placa A: GPIO2, placa B: GPIO1)",
}
CH_X1, CH_Y = 166.1875, 89.44


def ctrl_x(i):  # i = 0..7
    return CTRL_X1 - PITCH * i


def bx(x):  # KiCad -> coordenada da peca
    return round(x - BX0, 3)


def by(y):
    return round(y - BY0, 3)


# Conectores: 0-7 controle, 8.. = J1 tip, J1 ring, J2 tip...
CONNECTORS = []
for i, n in enumerate(CTRL):
    CONNECTORS.append({"id": f"connector{i}", "name": n, "desc": CTRL_DESC[n]})
for j in range(1, 9):
    for k, (lab, dy) in enumerate((("tip", 0.0), ("ring", 6.35))):
        ch = 2 * (j - 1) + k
        CONNECTORS.append(
            {
                "id": f"connector{8 + 2 * (j - 1) + k}",
                "name": f"J{j} {lab}",
                "desc": f"Jack {j}, {lab} = canal {ch} do MUX (pad {ch + 1} no ConfigTool)",
                "jack": j,
                "dy": dy,
            }
        )

FONT = "font-family=\"'Droid Sans', Arial, sans-serif\""


# ------------------------------------------------------------ breadboard
def breadboard_svg():
    w, h = round(BW, 3), round(H_TOTAL, 3)
    o = [
        '<?xml version="1.0" encoding="UTF-8"?>',
        f'<svg xmlns="http://www.w3.org/2000/svg" width="{w}mm" height="{h}mm" viewBox="0 0 {w} {h}">',
        '<g id="breadboard">',
        # placa (fenolite cobreada)
        f'<rect x="0" y="0" width="{w}" height="{round(BH, 3)}" rx="1" fill="#c9773b" stroke="#8a4a1f" stroke-width="0.3"/>',
        f'<text x="6" y="9" {FONT} font-size="4" font-weight="bold" fill="#5a2c0c">DRUMCORE JACKBOARD</text>',
        f'<text x="6" y="14" {FONT} font-size="2.6" fill="#5a2c0c">16 canais - 8 jacks TRS 6,35 mm</text>',
    ]
    # jacks
    for j in range(1, 9):
        x0 = bx(jack_x(j) - 18.3)
        y0 = by(JACK_Y - 6.83)
        jw, jh = 19.3, 26.53
        o.append(f'<rect x="{x0}" y="{y0}" width="{jw}" height="{jh}" rx="1" fill="#222" stroke="#000" stroke-width="0.3"/>')
        cx = bx(jack_x(j) - 9.0)
        # bico rosqueado saindo da borda
        o.append(f'<rect x="{round(cx - 5, 3)}" y="{round(by(BY1) - 0.5, 3)}" width="10" height="{round(H_TOTAL - by(BY1) + 0.5, 3)}" fill="#3a3a3a" stroke="#000" stroke-width="0.2"/>')
        o.append(f'<circle cx="{cx}" cy="{round(H_TOTAL - 1.6, 3)}" r="1.4" fill="#000"/>')
        o.append(f'<text x="{cx}" y="{round(y0 + 4.2, 3)}" {FONT} font-size="3.2" fill="#eee" text-anchor="middle">J{j}</text>')
    # modulo do MUX (azul) entre as 2 barras
    mx0, mx1 = bx(CH_X1 - 15 * PITCH) - 2.2, bx(max(CH_X1, CTRL_X1)) + 2.2
    my0, my1 = by(CTRL_Y) - 2.4, by(CH_Y) + 2.4
    o.append(f'<rect x="{round(mx0, 3)}" y="{round(my0, 3)}" width="{round(mx1 - mx0, 3)}" height="{round(my1 - my0, 3)}" rx="1" fill="#1f5fbf" stroke="#0d3a80" stroke-width="0.3"/>')
    o.append(f'<rect x="{round(mx1 - 11, 3)}" y="{round((my0 + my1) / 2 - 2.2, 3)}" width="8" height="5.2" fill="#111"/>')
    o.append(f'<text x="{round(mx0 + 3, 3)}" y="{round((my0 + my1) / 2 + 1.2, 3)}" {FONT} font-size="1.9" fill="#fff">CD74HC4067 16-ch MUX</text>')
    for i in range(16):  # barra dos canais (so' desenho)
        x = bx(CH_X1 - PITCH * i)
        o.append(f'<rect x="{round(x - 0.6, 3)}" y="{round(by(CH_Y) - 0.6, 3)}" width="1.2" height="1.2" fill="#bbb"/>')
    # pinos de controle (conectores)
    for i, n in enumerate(CTRL):
        x, y = bx(ctrl_x(i)), by(CTRL_Y)
        o.append(f'<rect id="connector{i}pin" x="{round(x - 0.8, 3)}" y="{round(y - 0.8, 3)}" width="1.6" height="1.6" fill="#d4af37" stroke="#8a6d1a" stroke-width="0.15"/>')
        o.append(f'<text x="{x}" y="{round(y + 3.4, 3)}" {FONT} font-size="1.05" fill="#fff" text-anchor="middle">{n}</text>')
    # tip/ring de cada jack (conectores) - no corpo do jack
    for c in CONNECTORS[8:]:
        x = bx(jack_x(c["jack"]) - 9.0)
        y = by(JACK_Y + 3 + c["dy"] * 1.4)
        lab = "T" if c["dy"] == 0 else "R"
        o.append(f'<circle id="{c["id"]}pin" cx="{x}" cy="{round(y, 3)}" r="1.1" fill="#c0c0c0" stroke="#666" stroke-width="0.15"/>')
        o.append(f'<text x="{round(x + 2.2, 3)}" y="{round(y + 0.9, 3)}" {FONT} font-size="2.4" fill="#eee">{lab}</text>')
    o += ["</g>", "</svg>"]
    return "\n".join(o)
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

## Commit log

2026-08-20 Estrutura inicial do projeto: docs, firmware (PlatformIO) e lib vendorizada
    Clona e vendoriza HelloDrum-arduino-Library como base para o firmware,
    documenta decisoes iniciais (ESP32-S3, PlatformIO, fork da lib) e
    achados sobre suporte nativo a 4x CD4051 (32 canais).
2026-08-20 Fase A: firmware de leitura dos 32 canais via 4x CD4051
    Implementa firmware/src/main.cpp instanciando 4x HelloDrumMUX_4051 + 32x
    HelloDrum, reportando hits via Serial (sem MIDI/OLED/botoes ainda). Define
    pinout proposto para o ESP32-S3 em docs/02-hardware.md.
    Corrige overflow de memoria na lib vendorizada: padType[] e showInstrument[]
    eram arrays fixos de 16 posicoes indexados por padNum/nameIndex, que vao até
    31 com 32 pads. Ambos ampliados para 32. Build validado com PlatformIO
    (esp32-s3-devkitc-1) - RAM 7.0%, Flash 8.7%. Ainda nao testado em hardware
    real.
    [main.cpp]
2026-08-20 Fase B: USB-MIDI nativo via Adafruit TinyUSB + MIDI Library
    Envia Note On/Off via USB-MIDI (classe de dispositivo nativa, TinyUSB) usando
    Adafruit_USBD_MIDI como transporte da FortySevenEffects MIDI Library, mantendo
    a mesma API MIDI.sendNoteOn/Off ja usada no sensing.
    Configura ARDUINO_USB_MODE=0 (modo TinyUSB/OTG - o padrao do board e modo
    Hardware-CDC, que nao suporta classes USB customizadas) e contorna conflito de
    linker entre a TinyUSB pre-compilada do core arduino-esp32 e a que a lib
    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
2026-08-20 Muda tela de OLED SSD1306 (I2C) para TFT ST7735 128x128 (SPI)
    Modelo escolhido pelo usuario por preco (Modelo Tela.jpeg). Atualiza pinout
    proposto (docs/02-hardware.md) e registra decisao de biblioteca - Adafruit
    GFX + Adafruit ST7735 Library em vez de u8g2/TFT_eSPI
    (docs/01-decisoes-arquiteturais.md). Ainda nao implementado no firmware.
2026-08-20 Fase C: tela TFT ST7735 + navegacao via 2 encoders rotativos
    Adiciona tela TFT (Adafruit GFX + Adafruit ST7735 Library) mostrando
    pad/item/valor atuais, e 2 encoders rotativos com chave (mathertel/
    RotaryEncoder) para navegar/editar - substituindo os 5 botoes discretos
    originalmente previstos.
    Os encoders alimentam HelloDrumButton::readButton() diretamente (overload ja
    existente na lib para sinais externos), sem precisar modificar a lib.
    Encoder 1 (giro=pad/valor, chave=EDIT), Encoder 2 (giro=item/parametro,
    chave reservada).
    Corrige uso incorreto de settingName() (precisa ser chamado por pad pra
    nameIndexMax ficar correto, e precisa de buffer estatico pro nome - guarda
    ponteiro, nao copia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
    [main.cpp]
2026-08-20 Fase D: persistencia de configuracao em EEPROM (NVS)
    Ativa EEPROM_ESP no setup() com flag de primeiro-boot: initMemory() grava os
    defaults na primeira vez, loadMemory() restaura o salvo nos boots seguintes.
    Escritas via encoder ja commitam sozinhas dentro de settingEnable() (lib),
    sem codigo extra nosso.
    Corrige bug real na lib vendorizada: o branch UP do item SENSITIVITY em
    settingEnable() usava padNum*8 em vez de padNum*10 (usado por todo o resto
    do layout), corrompendo dados de outro pad para padNum >= 1. So apareceu
    agora porque e' a primeira fase com EEPROM de fato ativa.
    Build validado (compila e linka). Teste em hardware real ainda pendente -
    sem como simular reboot com NVS real sem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
    [main.cpp]
2026-08-20 Fase E (firmware) + inicio da interface desktop (Electron/React/TS)
    Firmware: protocolo serial NDJSON sobre USB-CDC (bblanchon/ArduinoJson) -
    comandos get/set por pad, device_info, eventos de hit, logs de boot. Todo
    o trafego Serial agora e' JSON (antes eram prints de texto livre). Contrato
    completo em docs/04-protocolo-serial.md.
    Desktop app: scaffold Electron + React + TypeScript (electron-vite). Tela
    de conexao serial, grid de 32 pads, editor de parametros, "modo demo"
    (simula o modulo sem hardware/porta serial). Corrigidas vulnerabilidades de
    dependencias do scaffold inicial antes de seguir (electron/vite
    desatualizados).
    Stack e protocolo decididos com o usuario - ver
    docs/01-decisoes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
    [main.cpp]
2026-08-20 Fase F: nome livre por pad, editavel so pelo app desktop
    Cada pad ganha um "label" de texto livre (ex: "Caixa"), persistido em
    EEPROM. Numero do pad fixo - nome exibido sempre "N - label" (ou "Pad N"
    sem label), tanto na tela TFT quanto no app.
    Firmware: padLabels/padNames em main.cpp, layout de EEPROM estendido.
    Protocolo set_pad ganhou o campo "label" (string), reaproveitando o comando
    existente em vez de criar um novo (set_pad com field=label responde com o
    pad_config atualizado, os demais campos continuam respondendo com ack).
    App desktop: campo de texto no editor do pad, numero fixo ao lado, commit
    ao sair do campo/Enter. Modo demo atualizado.
    Build/typecheck do firmware e do app val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
    [main.cpp]
2026-08-20 Fase G: 8 tipos de sensor + topologia de canais configuravel pelo app
    Implementa todos os tipos de sensor documentados pela HelloDrum-lib
    (simples, aro/dual, chimbal simples, prato 2 zonas, chimbal 2 zonas, prato
    3 zonas, pedal FSR/VH-10/VH-11, pedal optico TCRT5000). Nenhum tipo usa
    mais de 2 canais - confirmado lendo o codigo-fonte da lib (o prato de 3
    zonas usa o MESMO canal do switch de borda pra derivar a 3a zona/cup, via
    threshold mais alto, nao um canal separado).
    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
2026-08-20 App desktop: lista de pads compacta em vez de grid de botoes grandes
    PadGrid.tsx agora renderiza uma linha por pad (numero, nome ou "Sem nome",
    nota) numa coluna fixa mais estreita, em vez de um grid 4 colunas de
    botoes grandes. Deixa mais espaco pro editor do pad. So UI, sem mudanca de
    protocolo/firmware.
2026-08-20 Adiciona simulador do LCD + encoders no app desktop
    Nova aba "Simulador do modulo" (HardwareSimulator.tsx) que recria a tela
    TFT 128x128 e a navegacao pelos 2 encoders rotativos, reproduzindo a mesma
    maquina de estados do firmware (handleConfigInputs()/renderScreen() em
    main.cpp): navegar pad/item fora de edicao, so o encoder 1 funciona
    durante a edicao (igual ao readButton() real), flash EDITAR/OK, mensagem
    de canal ocupado.
    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
2026-08-20 Adiciona esquematico visual de ligacao do hardware
    Reune o pinout ja documentado (ESP32-S3, 4x CD4051, tela TFT ST7735, 2
    encoders) num diagrama SVG unico, com legenda de cores por subsistema,
    tabelas de referencia e notas de montagem que ainda nao estavam explicitas
    em lugar nenhum (VDD/VSS/INH do CD4051, pull-up interno dos encoders sem
    resistor externo).
    Salvo em docs/assets/esquematico-hellodrum.html e tambem publicado como
    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
2026-08-21 Fase H: BLE-MIDI simultaneo ao USB-MIDI
    Adiciona lathoub/Arduino-BLE-MIDI (stack Bluedroid do proprio core, sem
    dependencia extra) como transporte adicional - todo hit/CC vai tanto pro
    USB-MIDI quanto pro BLE-MIDI quando houver um dispositivo pareado. Nao e'
    um modo a escolher, os dois ficam sempre ativos.
    Instancia nomeada "BleMidi" (BLEMIDI_CREATE_INSTANCE) em vez do nome padrao
    "MIDI" que colidiria com o MIDI ja usado pro USB. Nome anunciado via
    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
2026-08-21 Corrige sliders do editor de pad nao refletindo valor alterado
    set_pad em campos numericos responde com ack (nao pad_config), mas
    App.tsx so registrava o ack no log sem atualizar o estado local "pads".
    Como os sliders sao inputs controlados ligados a esse estado, eles sempre
    reexibiam o valor antigo apos arrastar - parecia que o slider "nao
    funcionava".
    Corrigido aplicando pad/field/value do ack no estado local tambem. Afeta
    tanto o modo demo quanto o modulo real.
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2026-09-02 Fase R/S: USB-MIDI funcionando, bug do pads[] corrigido, tela em paisagem
    - USB-MIDI reconhecido de verdade por uma DAW (causa raiz: hardware
    nunca era religado nesse chip sem CDC/MSC/DFU_ON_BOOT - religamento
    manual via bringUpNativeUsbHardware()). BLE-MIDI confirmado anunciando
    certo (falta so' um app-ponte no Windows).
    - Causa raiz do bug do array pads[] (Fase Q) finalmente encontrada:
    colisao de nome entre a flag PULLUP da lib e a constante PULLUP do
    core arduino-esp32 - pinMode() era chamado com indices de canal do MUX
    como se fossem GPIOs de verdade. Leitura real por pad restaurada.
    - Primeiro sensing de piezo real validado de ponta a ponta - achada e
    corrigida uma segund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
    [drumcore_jackboard.kicad_pcb, drumcore_jackboard.kicad_sch, drumcore_mainboard.kicad_pcb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]
2026-09-02 Fases U-X: auto-tune multi-zona, correcao de gain, calibracao de HHC
    - Fase U/V: auto-tune ganha rodadas extras pra pads de 2+ canais -
    PAD_DUAL calibra o aro (diferenca entre canais), prato/caixa 3 zonas
    calibram edge+cup/aro (faixas de threshold no mesmo canal secundario).
    - Fase W: corrige batidas fracas nao detectadas na calibracao - o gain
    antigo do pad distorcia a leitura do assistente (rawValue[] e'
    compartilhado com a lib); agora forca gain neutro durante toda a
    calibracao.
    - Fase X: novo assistente de captura de range pro controlador de pedal
    (HHC) - sensor de posicao continua, sem golpes/niveis - e campo
    hihat_invert (Sim/Nao) pra sensores que mandam a posicao inverti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
    [main.cpp]
2026-09-04 Jackboard: pinos T/R corrigidos + rede de protecao por canal; teste do sensor hall
    Hardware (hardware/jackboard):
    - Esquematico: jacks usavam TN/RN (contato normal/switched) como sinal por
    engano - corrigido pra usar T/R de verdade (Tip=par, Ring=impar), com
    TN/RN/S/SN todos em GND.
    - Adicionada rede de protecao por canal (16x): resistor serie 100R + resistor
    paralelo 100k + diodo BAT85, mesma topologia do esquema de referencia da
    HelloDrum-arduino-Library pro MUX (docs/circuit.md).
    - PCB: jacks recriados com a netlist corrigida (sync limpo, sem conflito de
    net reatribuido em pad ja roteado) e realinhados no passo fisico de
    22.5mm; os 48 componentes de protecao posicionados no es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
    [drumcore_jackboard.kicad_pcb, drumcore_jackboard.kicad_sch]
2026-09-05 Jackboard: roteamento completo, logo, GND ajustado; docs e site atualizados
    - Jackboard: roteamento completo (0 curtos/desconectados no DRC), U1/U2
    recentralizados, logo "DRUMCORE" na serigrafia (F.SilkS), pad de teste
    +3V3 no estilo dos resistores, placa redimensionada (rosca do jack pra
    fora) com malha de GND reajustada. Gerbers regenerados em
    hardware/jackboard/fab/.
    - mainboard aposentada (fiação simplificada dispensa PCB dedicada) e
    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
    [drumcore_jackboard-B_Cu.gbl, drumcore_jackboard-B_Mask.gbs, drumcore_jackboard-B_Silkscreen.gbo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]
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2026-09-05 Fixa versao da plataforma espressif32 (7.0.1) no platformio.ini
    Sem versao fixada, a CI (instalacao do zero a cada run) puxa a "latest"
    do momento - hoje 7.1.1, divergindo silenciosamente da 7.0.1 testada e
    funcionando aqui localmente. Bibliotecas (lib_deps) ja batiam identicas
    nos dois lados; so a plataforma divergia. Suspeita forte de ser a causa
    do build da CI nao chegar no estagio de upload/write_flash (log da CI
    confirmado pelo Rodrigo: nenhuma linha 'write_flash' encontrada).
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2026-09-05 CI: publica upload_log.txt num branch de debug (diagnostico temporario)
    A extracao continua falhando mesmo com PTY real - preciso ver o log
    completo pra saber por que, e nao consigo baixar logs do Actions sem um
    token (sessao sem navegador). Clone separado em /tmp cria/forca-push um
    branch orfao "ci-debug-logs" so' com o log, legivel via
    raw.githubusercontent.com sem autenticacao. Remover este passo assim que
    o problema for identificado e corrigido.
2026-09-05 Fixa tool-scons@4.40801.0 - causa real do build falhar so' com -v na CI
    Achado com o log completo (publicado via ci-debug-logs, ja que nao dava
    pra baixar logs do Actions sem token): a CI (instalacao do zero) puxava
    tool-scons@4.41101.0 (SCons upstream 4.11.1), que tem um bug real no
    print_cmd_line do modo verbose (SCons/Action.py: `s + "\n"` com `s` sendo
    o sentinela `_Null`, TypeError, build inteiro falha com -v). So' acontece
    em verbose - por isso nunca aparecia como erro de compilacao "normal", so'
    como ausencia da linha write_flash. tool-scons@4.40801.0 (SCons 4.8.1, o
    que ja estava em cache local) nao tem esse bug.
2026-09-05 CI: patcha o bug do SCons verbose em vez de tentar fixar versao
    platform_packages nao funcionou pra fixar o tool-scons - o PlatformIO
    instala a versao pedida E a que o espressif32@7.0.1 realmente requer,
    detecta conflito e remove a nossa (confirmado no log real da CI). Em vez
    de brigar com a resolucao de pacotes do PlatformIO, patcha direto o
    arquivo com bug (SCons/Action.py:print_cmd_line, faz `s + "\n"` quando `s`
    e' o sentinela `_Null`) depois que os pacotes sao instalados por um build
    normal (sem -v), antes do build verboso que a CI de release precisa pra
    descobrir os parametros reais de flash.
2026-09-05 Remove passo de debug temporario da CI (problema resolvido) + CHANGELOG
    Pipeline de release do firmware validada de ponta a ponta (fw-v0.0.2-test):
    binario mesclado agora sai com flash_mode/freq/size reais (dio/80m/16MB),
    nao mais os valores errados assumidos antes. Resumo completo da
    investigacao (3 causas raiz distintas) no CHANGELOG.
2026-09-05 Mensagem clara + cache pro limite de requisicoes da API do GitHub
    O erro que o Rodrigo viu ("GitHub respondeu 403") era o limite de 60
    requisicoes/hora sem login da API do GitHub, estourado pelos testes
    manuais de CI desta sessao (mesmo IP). Nao era bug novo, mas a mensagem
    generica nao deixava isso claro - agora detecta especificamente esse caso
    (via header x-ratelimit-remaining) e mostra o horario de reset. Tambem
    adicionado cache de 5 min no processo main - a aba Firmware remonta (e
    rebuscava do zero) toda vez que o usuario troca de aba, o que sozinho ja
    poderia estourar o limite em uso normal.
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2026-09-05 Corrige build do web-app na CI: instala deps do desktop-app tambem
    Causa real (achada com o log publicado no branch de debug): web-app/
    importa componentes direto de desktop-app/src/renderer/src/ (sem
    duplicar codigo), mas a resolucao de modulos do TypeScript/Node sobe a
    partir do arquivo importador, nao da raiz do projeto - como esses
    arquivos moram fisicamente em desktop-app/, precisam do
    desktop-app/node_modules instalado (react/react-dom/esptool-js e os
    @types/* deles, que ficam em devDependencies) pra resolver. So'
    "funcionava" local por acidente (node_modules do desktop-app ja instalado
    de sessoes anteriores) - reproduzido e confirmado removendo node_modules
    localmente antes de aplicar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
2026-09-05 Corrige duas copias de React no bundle do web-app (tela em branco)
    App.tsx/FirmwareManager.tsx (fisicamente dentro de desktop-app/) estavam
    resolvendo "react"/"react-dom" a partir de desktop-app/node_modules
    (resolucao de modulo sobe a partir do arquivo que importa), enquanto
    src/main.tsx usava o web-app/node_modules - duas copias de React no
    mesmo bundle, causa classica de "Invalid hook call" (pagina carrega mas
    fica em branco, sem erro visivel fora do console do navegador).
    Confirmado inspecionando o sourcemap do build: apareciam 2 caminhos
    diferentes pra react antes do fix, 1 so' depois. Alias em
    vite.config.ts forca tudo pra copia do web-app, seja qual for o arquivo
    que importou (mesmo f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
2026-09-05 Corrige connect() nao fazendo nada no build web (faltava ajustar o guard)
    Ajustei o "disabled" do botao Conectar pra nao exigir porta pre-selecionada
    quando ports.length === 0 (build web), mas esqueci que connect() tinha o
    mesmo guard internamente (if (!selectedPort) return) - no build web
    selectedPort nunca deixa de ser '', entao clicar no botao nao fazia
    literalmente nada, nem abria o seletor nativo do navegador. Mesmo ajuste
    aplicado aqui.
2026-09-05 Corrige condicao de corrida no disconnect() (Web Serial) + gira foto da placa
    - disconnect() cancelava o reader mas nao esperava o pipeTo (port.readable
    -> TextDecoderStream) terminar de soltar o lock antes de chamar
    port.close() - a aba Firmware, ao tentar reabrir a mesma porta pra
    flashar logo em seguida, batia em "Failed to execute 'open' on
    'SerialPort': The port is already open." Agora guarda a promise do
    readLoop inteiro e espera ela terminar antes de fechar a porta.
    - esp32-uart.png girado 90 graus (ficava vertical/estreito, agora
    horizontal, melhor pro card da aba Firmware).
2026-09-06 Aposenta o app desktop (Electron); app web unificado visualmente com o site
    Só o app web (web-app/) segue como forma de configurar o módulo. O
    código compartilhado (App.tsx, componentes, protocolo, etc) foi movido
    de desktop-app/src/renderer/src/ pra dentro de web-app/src/ (sem
    duplicar), eliminando os workarounds de resolução cross-package
    (resolve.alias, server.fs.allow). desktop-app/ e o workflow do
    instalador (app-release.yml) foram removidos por completo.
    web-app agora adota a paleta/tipografia do site (IBM Plex Sans/Mono) e
    ganhou o mesmo topnav do site, incluindo a marca "DRUMCORE" (grade de
    pixels 8x4, direção 1A) como um SVG reusado também no nav das páginas
    do site.
    Text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
    [main.cpp]
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2026-09-06 Jackboard single-layer: roteamento completo J1-J8 em B.Cu, malha de GND e exports para termotransferencia
    Converte o jackboard para placa single-layer (home-etching): todo o
    roteamento dos 16 canais (J1-J8) fica na camada bottom, com chanfros de
    45 graus nos cantos em vez de ângulos retos. Adiciona malha de GND
    (GND_MESH_BOTTOM) em B.Cu estendida até o limite real da placa, com
    clearance de 0.7mm das netclasses Signal/Power. Restaura o ponto de
    teste de +3V3 perto do J1 como via (workaround para footprint sem rede
    associada). Exporta PDFs prontos para impressão: placa única em P&B
    para transferência térmica e um layout com 4 placas por folha A4.
    [drumcore_jackboard_singlelayer.kicad_pcb, drumcore_jackboard_singlelayer.kicad_sch]
2026-09-12 Novo tipo de sensor Choke, bring-up sem jackboard, correcoes na tela SIGNAL e site atualizado
    Adiciona pad_type 9 (Choke - fita de contato, gatilho binario com velocity
    fixo em 127) no firmware e no app web, com auto-tune desabilitado pra esse
    tipo. Canais 1/2 passam a ser lidos direto de 2 pinos do ESP32-S3 (GPIO9/10)
    enquanto a jackboard nao e' montada. Corrige 2 bugs na tela SIGNAL: escala
    do grafico limitada a 0-1023 em vez do fundo de escala real do ADC (0-4095),
    e o grafico nao redesenhava sozinho (ficava "congelado" ate' trocar de pad).
    Site (site/index.html, site/hardware.html) atualizado: 10 tipos de sensor,
    status de bring-up, e secao sobre a jackboard single-layer (home-etch).
    Co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
    [main.cpp]
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2026-09-15 Auto-tune: coleta por janela de tempo, curva/retrigger inferidos (Fase AA/AB)
    - Fase AA: nivel de forca (fraco/medio/forte) passa a colher por uma
    janela de 10s em vez de uma meta fixa de 8 golpes - mais amostras,
    media mais confiavel. So se aplica ao fluxo de impacto (pads normais),
    o controlador de pedal (HHC) continua com o proprio esquema de 3s por
    posicao.
    - Bugfix (pre-requisito da Fase AB): retrigger (Fase P) comparava o piso
    decrescente (escala ja mapeada 1-127, pos curve()) contra o novo golpe
    em escala bruta - deixava passar quase qualquer coisa durante o
    mask_time, quase sempre, independente da forca real. Corrigido nos 4
    pontos da lib vendorizada guardando o pico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
    [main.cpp]
2026-09-25 Jackboard single-layer: grampo duplo com 1N4148, 1k em serie, 4,7k no SIG e trilhas de 0,8mm
    Protecao por canal revisada para usar 1N4148 (o BAT85 e' dificil de
    achar aqui):
    - R1-R16 (serie) de 100R para 1k, pra limitar a corrente que passa pelo
    grampo, ja' que o 1N4148 grampeia ~0,4V mais alto que o Schottky.
    - D1-D16 trocados de BAT85 para 1N4148 (mesma posicao, catodo no sinal,
    anodo no GND).
    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
    [drumcore_jackboard_singlelayer.kicad_pcb, drumcore_jackboard_singlelayer.kicad_sch]
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2026-09-26 Hardware e capturas: sessoes rawpad, arquivos Fritzing, jackboard e fotos da tela
    [001_aro.csv, 001_centro-fraco.csv, 002_aro.csv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]
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2026-10-01 Sessao 3 do rawpad (piezo da borda mais alto) e ferramentas de captura/analise
    - captures/rawpad/sessao3: 40 batidas no J2 pela jackboard A (aro,
    pele-borda, centro-forte, centro-fraco). Folga aro x resto 4,4x
    (sessao 2: 0,7x)
    - rawpad_capture.py: opcao --jack e abertura da porta sem reiniciar a placa
    - rawpad_analyze.py: razoes ring/tip e tardio/cedo por rotulo e simulacao
    da classificacao de 3 zonas com a varredura do MUX
    [001_aro.csv, 002_aro.csv, 003_aro.csv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]
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2026-10-03 Wi-Fi fase 3: atualizar o firmware pela rede
    Aba Firmware do ConfigTool aberto pela placa: baixa a release mais recente
    (ou usa um .bin escolhido), recorta o app em app_offset e envia por
    POST /update. O modulo so' aceita depois de um clique no encoder
    (ota_request -> confirm -> armed), confere chip/imagem/hash, reinicia com o
    Wi-Fi ligado e o app reconecta sozinho. Release grava app_offset no
    manifest. Corrige a escolha da release mais recente (tags comparadas por
    numero, nao como texto).
    [main.cpp]
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2026-10-04 Peca do Fritzing da jackboard single-layer
    hardware/fritzing/DrumCore_Jackboard.fzpz gerado por make_jackboard_fzpz.py
    com as medidas do projeto KiCad (contorno, jacks, barras do MUX): vistas
    protoboard, esquematico e PCB, 24 conectores (controle do MUX + tip/ring dos
    8 jacks; EN e GND no mesmo barramento). Link na pagina de hardware. Lista de
    componentes corrigida: 7 fios por jackboard (EN ja' vai pro GND na placa).
    [make_jackboard_fzpz.py]
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2026-10-15 Esquematico do site conferido com o hardware montado
    Pinos todos batiam com o firmware. Corrigido o que divergia da placa real:
    2 portas USB-C (nativa = USB-MIDI, USB-UART = ConfigTool/gravacao) em vez
    de 1; MUX descrito como montado na jackboard (EN ja' em GND na placa, 16
    canais <- 8 jacks com protecao, 7 fios ate' o ESP32); nota do jack 1
    modificado pro SS49E; ADC2 nos pinos a evitar; selo de status verde.
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2026-10-15 Site: esquematico inteiro no quadro da pagina de hardware
    O quadro carrega schematic.html?embed: so' o diagrama, reduzido pra caber
    na largura (iframe na proporcao 16:10); clicar abre a pagina completa com
    os detalhes. Corrigida a rolagem lateral no celular (caminho de arquivo
    em <code> nao quebrava linha) e selo de status validado em verde.
2026-10-25 Crosstalk calibrado, pad Dual por razao, LIVE sem engasgar e telemetria do pedal
    - Crosstalk: pico bruto de cada canal nos ultimos 10-20 ms (na varredura do
    MUX) + tabela vitima x fonte medida pelo assistente (start/stop_xtalk_cal,
    get_xtalk, clear_xtalk). Disparo descartado abaixo de 1,5x (ate' 3x pelo
    xtalk do pad) o vazamento esperado. Resolve o bumbo disparando os toms,
    que a supressao por grupo nao pegava (so' comparava a mesma volta do loop).
    ConfigTool: Global > Crosstalk entre pads.
    - Pad Dual (tipo 1): aro pela razao ring/tip (ARO%, padrao 70), scan >= 10 ms,
    calibracao calcula a razao; pads ja' salvos migrados uma vez (sessao4).
    - Tela LIVE: redesenha e envia so' a celu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
